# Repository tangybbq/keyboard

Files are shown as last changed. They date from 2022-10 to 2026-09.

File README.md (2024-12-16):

# David Brown (d3zd3z) keyboard designs

This repo captures the design files associated with my custom
keyboards.

These keyboards are primarily focused on Steno input, mainly using
[Plover](https://www.openstenoproject.org/plover/). In the spirit of
open steno, I have made these designs open. Anyone is free to make
designs based on these keyboards, for non-commercial purposes.  I am
releasing the designs under the [CC BY-NC
3.0](https://creativecommons.org/licenses/by-nc/3.0/) license.
Specifically, this means if you wish to sell a product based on the
design, you should talk to me.

## The "Jolt" keyboard

At this point, I've decided to give the keyboard a real name, hence "jolt".  The jolt 1 is still in
Eagle, and I may migrate the files here.

But, I have added the "jolt2".  The jolt2 is an experiment beyond just a traditional corne-like
keyboard, and something fully in 3-space, like the dactyl.  There are individual base plates for
left and right, and then small strips of 3 keys for each column.  The base PCB has 4 pairs of pin
headers to support these individual 3-key columns.  This will allow me to experiment with elevation
as well as just the X and Y position of each key.  I still want each column to be at the same
elevation, because I rely heavily on pressing keys together (both for my qwerty layout, and for
steno).

At this point, there are 4 PCBs here:

- [jolt2-left](jolt2/jolt2-left/): The layout of the left
  side using a directly assembled rp2040
- [jolt2-tiny2040-left](jolt2/jolt2-tiny2040-left/): The same left side pcb, but built around the [Pimoroni
  Tiny 2040](https://shop.pimoroni.com/products/tiny-2040?variant=39560012234835).  Note that only
  the left side needs the 8MB version (to hold the steno dictionary), but I just ordered all the
  same, and use the 8MB version on each side.
- [jolt2-tiny2040-right](jolt2/jolt2-tiny2040-right/): The Tiny 2040-based, made for the right side.
- [jolt2-verts](jolt2/jolt2-verts/): These are the small 3-key support boards.  It will take 28 of these,
  plus a left and a right to build a full keyboard.

In addition, there is also a [jolt2-pim-left](jolt2/jolt2-pim-left/), based around the [Pimoroni
PGA2350](https://shop.pimoroni.com/products/pga2350?variant=42092629229651).  There are numerous
errors in this that need to be fixed, as I messed up the reference numbers for the headers to the
key-boards.

## The "bletest2"

This isn't really a keyboard, but my experiments putting an nRF5340 module on a board.  This is work
in progress, and has numerous things I've discovered wrong with it.  I will work to improve it over
time:

- The power supply was suppose to auto switch between USB power and battery power.  However, I
  accidentally chose a boost converter instead of a boost/buck converter, and if USB is connected,
  all it does is fry everything on the board.  You can either leave out D1, or install a chain of
  diodes in its place (I used 5) to drop the voltage enough to make VBUS less than the 3.3.
  Auto-switching will probably end up preferring the battery, though, so I just recommend removing
  D1 entirely, and powering the board off of the batteries.
- The RGB LEDs don't work.  I'm not quite sure what is wrong, as I see no signal on the DIN pin.  I
  maybe have issues, given the difficult of properly soldering down the BLE module.
- The LEDs probably need a 5V supply, which isn't readily available.  Realistically, if I build a
  battery power device, I'll likely just use an analog RGB component, and use 3 gpios with PWM.

The intent was to be able to remove the various jumpers, and use the Power Profiler Kit II to
observer power consumption.  Despite rev 2, I'm still not far enough along with this to be able to
do that meaningfully.

## The "shield-kb1"

This is an Arduino-style shield, designed to plug into the nRF5340 DK.  It provides non-working
LEDs, a 2x2 keyboard matrix, and inter-board headers for left and right that should allow it to talk
to the jolt or proto3 designs.

## The "proto3"

This is basically the same design as the proto2, but with a third row.
The qmk supports an easier qwerty mode, but still with a modified
homerow modifier support (I use the lower row as it has slightly fewer
rollover conflicts).

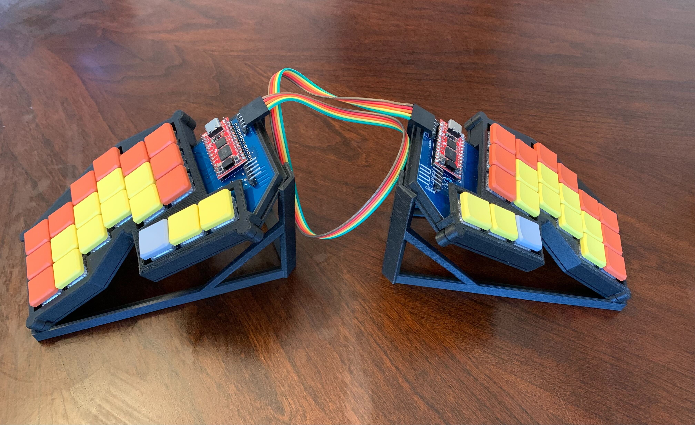
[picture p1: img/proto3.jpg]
proto3


The BOM is the same as the proto2, but it will need 42 diodes.

## The "proto2"

For lack of a better name, this first design is called the "proto2".

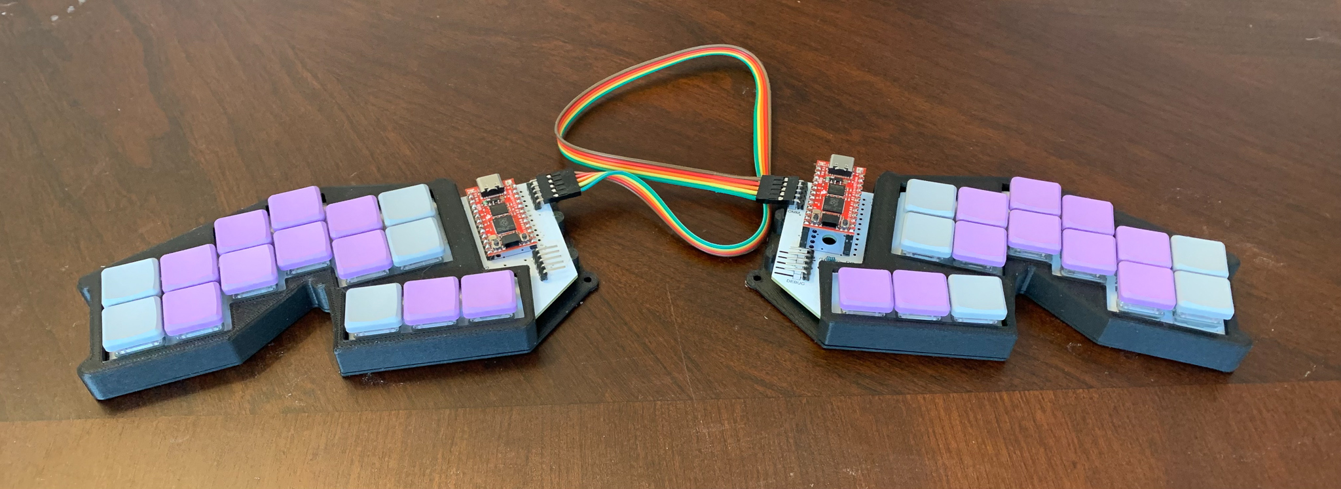
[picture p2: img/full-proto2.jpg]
full-proto2


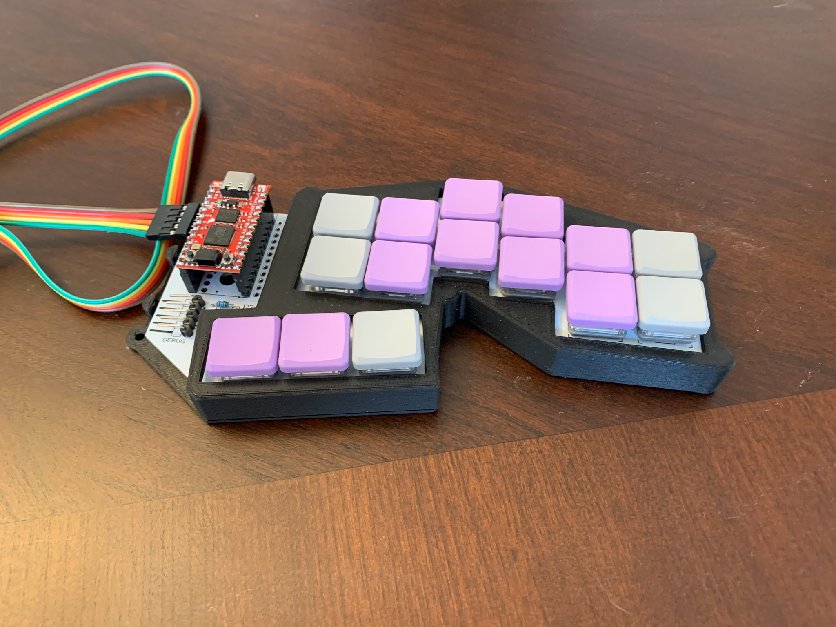
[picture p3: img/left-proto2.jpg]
left-proto2


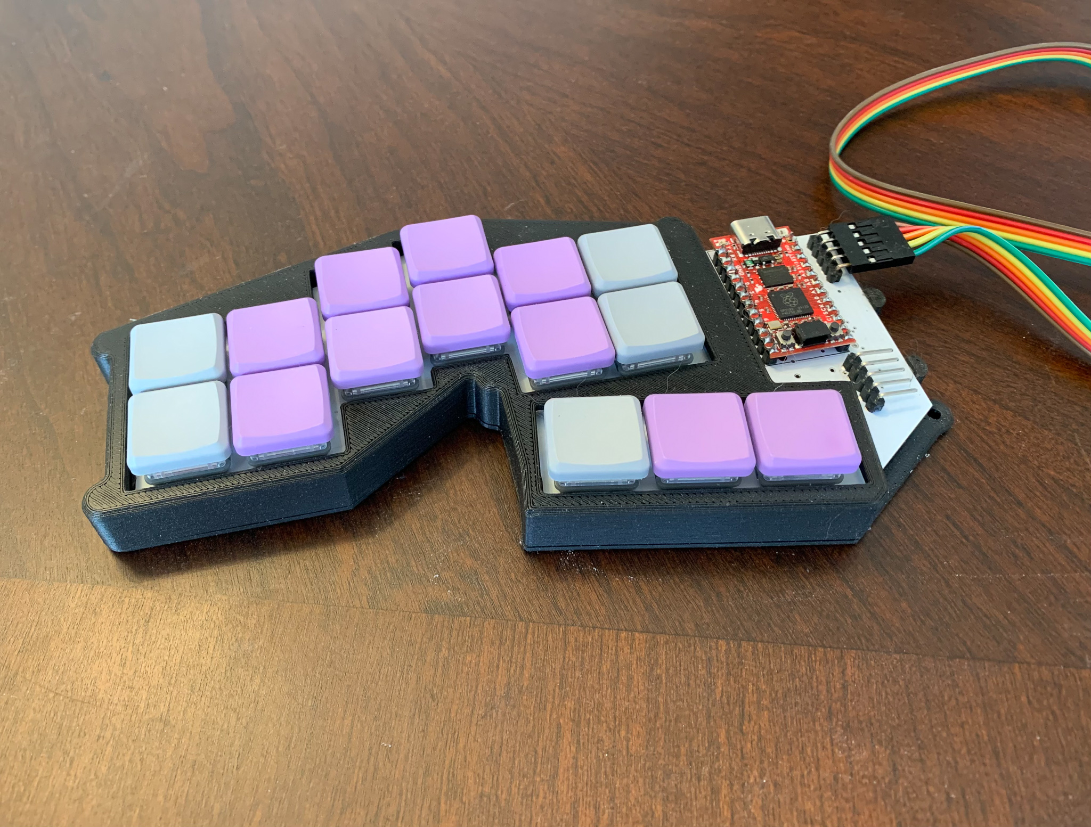
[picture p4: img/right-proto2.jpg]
right-proto2


There was an earlier prototype, that was handwired, and rather
fragile.  This is the first version I would consider to be a usable
keyboard.  In the above pictures, the left half has the MCU (Pro Micro
RP2040) soldered directly to a header, soldered to the PCB, and the
right one uses a socket.

To build this, in addition to the PCBs, you will need

- 2 [Pro Micro RP2040](https://www.sparkfun.com/products/18288)
  boards.  At the time of my build, these are running about $11, and
  seem readily available.
- 30 Kailh Choc switches.  I sourced mine from
  [Mkultra](https://mkultra.click/choc-switches).  I recommend the
  "pink" version, which has 20gf springs, and I find work well.
- 30 keycaps for these switches.  I used the [MBK Factory
  Colors](https://mkultra.click/mbk-factory-colors/) keycaps, which
  allows me to make the "primary" keys stand out a little, and just
  looks rather nice.
- 30 general purpose SOD123 diodes.  I got
  [BAV19W](https://www.digikey.com/en/products/detail/smc-diode-solutions/BAV19W/5993796),
  although almost any diode will work for this.
- 2 or 4 5-pin right angle headers.  Two are needed for the
  communication between the boards.  The others are interested if you
  want to use SWD, since the RP2040 Pro Micro inconveniently puts
  these connectors on the underside of the board.

The PCB is reversable.  The RP2040 board should be mounted in the
labeled holes, which is always the left set when viewed from the top.
The diodes are intended to be soldered to the bottom side of the
board.

I have also a case design that can be 3d printed.  The models are for
the right side. Use your slicing software to mirror about the X axis
to print the pieces for the other side.

The firmware I am using for this keyboard is in my fork of
[QMK](https://github.com/tangybbq/qmk_firmware/tree/proto2).

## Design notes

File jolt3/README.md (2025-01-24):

# The Jolt 3

The Jolt 2, with the varying-elevation design has turned out to be a rather nice keyboard to use.
However there are some challenges:

- Even with sockets, assembling all of the key risers is quite time consuming.  This makes it more
  challenging to experiment with the rest of the electronics.
- With more circuitry on the main board, the left/right distinction greatly increases the work to
  try a new design.

As such, the main goal of the Jolt 3 is to modularize the board design.  This is similar to using
existing rp2040 modules in the design, but in this case, the mezzanine board is my design instead,
with the following changes:

- Larger available area.  This allows me to put more on the board.
- Always have a debug headers.  The plethora of small boards that don't bother with debug headers is
  baffling to me.  I understand a lot of people are doing python, but this makes the board almost
  entirely useless for any serious development.

In order to make this board able to be used on either side of the keyboard, we'll need to avoid any
connectors that vary from side to side, notably the rj-45 (or whatever jack I decide on).  Now might
be a good time to try a different connector.  USB-C would work well for this, but it seems to be
hard to find thin USB-C cables.  I don't want 240W, I want a thin cable.  The old Apple cable is
really nice, but is getting harder and harder to find.  Another option is RJ-9.  The cables aren't
quite as available (and tend to be curly), but this might be a nice compromise.

Another thought, since I now have a tented stand, is to put the rj45 on the bottom side of the
board, and cut a notch for it.

It is fine to have the USB and debug header on the small board.

Sockets are going to be nice.  Regular pin header sockets are fine, but do lift the board up quite a
bit.  It still might end up being the best approach, as narrower pitch are harder to find.

This design should make some number of pins available in standard places:

- GPIOs for row and column.  4+6 is adequate for any of my current designs.  A two-row version with
  a single CPU would need 5+6, so 11 pins for this seems fine.
- Pins for the RJ-45?  If this is underneath, it gives more space.
- Battery.  The base board should be designed to allow a battery underneath.  The lines will just
  run directly to the small board.

## Dimensions

If we put the RJ-45 underneath, this gives us 41mm across by 39mm high.  It might make more sense to
just have the board be square at 40x40mm.

For a two-row design, this space could still be available.  It is unclear to me where my future
desire for 2-row will go (it depends on whether I become fully comfortable with steno+taipo).

## Design

The main boards will be jolt3-left, and jolt3-right, with the same connector on each.

- Supports the 7 risers in the same positioning and connection as the jolt2.
- Has a 40x40mm area for a mezzanine board.
- Defines a pinout for connections between the boards.  There are 20 pins needed, plus whatever is
  needed for extra grounding. A single row is likely to be fine.r
- Decide on the particular mezzanine connector to use.  It might make sense to have on one side with
  standoffs on the other sides.

The smallest M-2 size is 22x42, which would fit (but give half the available area.

I've ended up going for the [DF40C](https://www.hirose.com/product/p/CL0684-4010-9-51#) series of
connectors, 30 pin with a 3mm board spacing.  I could probably do 2mm, but the pins on the RJ-45 are
fairly long, and 3mm avoids the need to trim.  I'll use 3 1mm thick nylon washers for each standoff.

Rev A implements the following:

- jolt3-left: The left side.  The only components are the holes to mount the risers, the RJ-45, a
  place to mount the 2AA battery holder, and two pull up resistors for I2C.
- jolt3-right: The same as left, with minor changes: no pullups on I2C, Tx and Rx on the serial
  lines are swapped.
- jolt3-mez2040: The rp2040 circuitry on the mezzanine board.  I ended up with 38x38mm, to bring the
  mounting holes in enough on the main board to clear the stand.  The rp2040 is rotated 90 degrees
  to better route gpios to the connector (moves the crystal out of the way).
- Use the same riser boards "jolt2-verts" from the Jolt2.

The biggest change from previous designs is moving away from the Arm Cortex-M debug header to the
6-pin [Tag Connect](https://www.tag-connect.com/).  This requires no components on the board, just
some holes and pads, taking about the same area as the Cortex-M connector.  There is a smaller one,
but for these prototypes, the definitive connection seems better.  The cable is about $45 and should
last a long time.

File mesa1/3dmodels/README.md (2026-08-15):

# mesa1 3D models

Models for the parts that stick up off the board, so the 3D viewer and
`File → Export → STEP` show what a case or stand actually has to clear.

| File | Footprint | Offset (mm) | Rotation (deg) |
|---|---|---|---|
| `Kailh_socket_PG1350.step` | `mesa1:Kailh_socket_PG1350` | 0, 0, 0 | 0, 0, 0 |
| `SW_Kailh_Choc_V1.step` | `mesa1:Kailh_socket_PG1350` | 0, 0, 0 | 0, 0, **180** |
| `MBK_Keycap_1u.step` | `mesa1:Kailh_socket_PG1350` | 0, 0, **6.65** | 0, 0, 0 |
| `Pimoroni_Tiny2040.step` | `mesa1:Pimoroni_Tiny2040` | 0, 0, 0 | 0, 0, 0 |
| `RJ45_Amphenol_54602-x08_Horizontal.step` | `Connector_RJ:RJ45_…` | 0, 0, 0 | 0, 0, 0 |

Path prefix for all of them: `${KIPRJMOD}/../3dmodels/`. Use the variable, not
an absolute path, or the references break for anyone who clones the repo.

The first three all hang off the one key footprint — it is the whole key:
switch on the front, hotswap socket on the back. Add them in Footprint Editor →
Properties → 3D Models, then `Tools → Update Footprints from Library` in each
PCB to push them to the placed instances.

The RJ45 model has to go on the PCB instance rather than the library footprint,
since that footprint comes from KiCad's stock `Connector_RJ` library.

## Why those numbers

**Socket.** The transform is baked into the STEP (rotate +90° about X, then
translate 5.0, -3.75, -1.6), so KiCad needs no offset. The -1.6 puts it on the
back face of the board and therefore assumes the 1.6 mm stackup — regenerate if
the board thickness changes. Alignment was checked against the footprint: the
two receptacle collars (r 1.45) land in the 3 mm NPTH at (0, 5.95) and
(-5, 3.75), and the contact tails land inside pads 1 and 2.

**Switch.** Used as published, in KiCad 3D coordinates. The upstream footprint
puts the switch pins at board (0, -5.9) / (5, -3.8); ours has them at
(0, 5.95) / (-5, 3.75), i.e. the switch is turned around, hence the 180° about
Z. With that rotation the pins line up with the socket collars.

**Keycap.** +6.65 in Z seats the cap's stem plate (model z = 1.4) on the
switch's slider top (z = 8.05). Checked for interference against the switch
solid: zero intersection volume. The two stem legs drop into the slider's
slots without bottoming out, and the skirt clears the switch housing by 1.6 mm
at rest, shrouding it on the way down.

## Envelope, per key, relative to the front face of the PCB

| | Z (mm) |
|---|---|
| Socket, lowest point | -3.44 (1.84 below the back face) |
| Board back face | -1.60 |
| Switch housing top | +5.05 |
| Keycap bottom rim | +6.65 |
| Keycap top | +10.80 |

Keycap outline is 17.45 × 16.45 mm against an 18 × 17 mm pitch, so 0.55 mm of
air between neighbours in both directions.

## Tiny 2040 and RJ45

Neither is a real vendor model — both are envelope solids, enough to place a
wall or a cutout against, not enough to render nicely.

**Tiny 2040.** Built here in FreeCAD; see `Pimoroni_Tiny2040.step`. Pimoroni do
not publish a STEP; SnapMagic and TraceParts have one but both want an account.
The XY is exact, lifted from the F.Fab geometry of our own footprint, which came
verbatim from Pimoroni's `pimoroni-boards.lbr`:

- module PCB 20.32 × 18.0, 0.4 mm corner chamfers, from X 0 to 20.32, Y ±9
- USB-C receptacle 7.82 × 8.64, X -2.175 to 5.645, overhanging the module end
- underside components filling the footprint's 16.92 × 12.6 Edge.Cuts relief

The Z split is derived, not measured. Pimoroni quote 22.9 × 18.2 × 6 mm overall;
6.00 is reproduced exactly as 1.84 underside + 1.00 module PCB + 3.16 USB-C
receptacle. Those three are a plausible decomposition of a figure that is only
quoted as a total, so treat the individual numbers as approximate — in
particular check the 1.84 before committing to a pocket depth. Overall L and W
come out 22.50 × 18.00 against their quoted 22.9 × 18.2; the package geometry is
the more trustworthy of the two.

**RJ45.** `RJ45_Amphenol_54602-x08_Horizontal.step` is a plain 6-face box,
15.31 × 17.74 × 13.5, already in this directory. It lines up with the stock
footprint exactly — X -3.210…12.100 against an F.Fab of -3.205…12.095, and Y
mirrored as KiCad's 3D convention requires.

Note that KiCad 10 does **not** ship a model for this connector. Its
`Connector_RJ.3dshapes` has only three RJ45s (`Amphenol_RJHSE538X`,
`Molex_9346520x_Horizontal`, `Pulse_JK0654219NL_Horizontal`), so the
`${KICAD10_3DMODEL_DIR}/…/RJ45_Amphenol_54602-x08_Horizontal.step` reference the
footprint carries can never resolve. Point the instance at the local box
instead. If a proper model is ever wanted, Amphenol's 54602 CAD is on SnapMagic
and TraceParts, behind a signup.

## Keycap colour

The upstream MBK file ships with Fusion's `Opaque(214,14,14)` appearance baked
in — a hard red. Changed to a neutral charcoal by editing the one colour entity
the keycap solid resolves to:

    #6912=COLOUR_RGB('MBK Charcoal',0.235294117647059,0.235294117647059,
    0.250980392156863);

Three RGB floats, 0–1. Geometry is untouched. `#6911` ('Steel - Satin') is
unreferenced upstream leftover — editing it does nothing.

## Sources and licensing

- `Kailh_socket_PG1350.step` — Kailh's own PG1350 socket CAD (`PG1350.STEP`,
  SolidWorks 2018), the copy already in this repo at
  `jolt2/jolt2-verts/PG1350-socket.STEP`, repositioned.
- `SW_Kailh_Choc_V1.step` — from [kiswitch](https://github.com/kiswitch/kiswitch)
  (formerly perigoso/keyswitch-kicad-library),
  `library/3dmodels/3d-library.3dshapes/SW_Kailh_Choc_V1.stp`. Dual licensed
  MIT / CC BY-SA 4.0; taken under the MIT option.
- `MBK_Keycap_1u.step` — MBK reproduction by darryldh,
  [Thingiverse thing:4564253](https://www.thingiverse.com/thing:4564253), via
  [namnlos-io/choc_keycaps](https://github.com/namnlos-io/choc_keycaps).
  **CC BY-NC 4.0.** Published with Max Burger's permission. It is a
  reproduction for rendering, not the production file — close but not exact, so
  do not treat it as a tolerance reference. 1.5u, 2u and homing variants are in
  the same upstream folder if they are ever needed here.

The NC clause matches this repo's own CC BY-NC 3.0 terms, but it does mean the
keycap model cannot travel into anything commercial.

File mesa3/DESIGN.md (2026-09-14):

# mesa3 — design decisions and setup notes

Companion to `LAYOUT.md`, which holds the geometry. This file holds the decisions: what
changes from mesa2, why, and what was checked.

Status: **Rev A ordered 2026-09-07 and in transit. Rev B is open** — see *Rev B* below.
Everything in this file describes Rev A unless a section says otherwise.

## What the Mesa 3 is

The mesa2 Rev B keyboard, cut into two independently-positioned halves in the style of
mesa1. Same 18 keys, same Dosh layout, same key geometry. A single **Tiny2040 on the
left half** runs everything; the right half is passive and reaches the left over one
RJ-45 cable.

```
mesa3/
  3dmodels -> ../mesa1/3dmodels     symlink, so ${KIPRJMOD}/../3dmodels resolves
  mesa3-left/    Tiny2040, 4x SK6812, Tag-Connect, reset pad, RJ-45, 9 keys
  mesa3-right/   9 keys, 9 diodes, RJ-45. Nothing else.
```

Both halves were made by copying the finished mesa2 Rev B project **whole** and deleting
the other side, rather than building each up from parts. That is why the geometry
survives exactly.

## The matrix

**One 5 × 4 grid spanning both halves** — not one matrix per half.

- **5 columns, one per finger, shared across the halves.** The index column carries all
  four index keys: `I`/`E` on the left, then over the cable to `I`/`E` on the right.
- **4 rows, two per half.** `ROW_A`/`ROW_B` are the left's far and near rows,
  `ROW_C`/`ROW_D` the right's.
- 18 keys in 20 slots. The two empty ones are where mesa2's outer pinky keys were.

Column-to-pin assignment, unchanged from Rev B:

| net | keys | Tiny2040 pin |
|---|---|---|
| `COL_1` | pinky `A`, both hands | GP7 |
| `COL_2` | ring `S`/`O` | GP6 |
| `COL_3` | middle `N`/`T` | GP5 |
| `COL_4` | index `I`/`E` | GP4 |
| `COL_5` | thumb `SP`/`BK` | A3/GP29 |
| `ROW_A` | left far | A2/GP28 |
| `ROW_B` | left near | A1/GP27 |
| `ROW_C` | right far | GP0 |
| `ROW_D` | right near | GP1 |

**GP2 and GP3 are spare** and stay that way — see *Which board am I?* below.

### The firmware must not be able to tell a Rev B from a Mesa 3

This is a hard constraint, not a nicety. All 18 keys keep their **exact mesa2 (column,
row)** — verified key by key against Rev B's netlist — so one keymap serves the unibody
and the split alike, and no board-specific code is needed.

## The interconnect

Seven signals cross: **5 columns + `ROW_C` + `ROW_D`**. The columns run straight through
because they are shared by both hands; only the right's two rows are local to it.

| RJ-45 pin | net |
|---|---|
| 1 | *unused* |
| 2 | `COL_1` |
| 3 | `COL_2` |
| 4 | `COL_3` |
| 5 | `COL_4` |
| 6 | `ROW_D` |
| 7 | `ROW_C` |
| 8 | `COL_5` |

**Verified identical at both ends**, which is what makes a straight-through cable
correct. This is the check mesa1 learned to do and the one that fails silently: get it
wrong and the cable quietly becomes a crossover.

The pin *order* runs in opposite directions on the two boards. That is not a mistake —
an RJ-45 cannot be mirrored, so on mirror-image boards the same part necessarily has its
pin 1 at opposite ends. Only the net mapping has to match, and it does.

**Pin 1 is left unconnected on purpose.** It is tempting to run a ground down it, but
there would be nothing to connect it to: the right half has no ground net. The return
path for a scanned row is the column conductor it is switched into, so every loop already
closes through two wires of the same cable. mesa1 runs the same way.

### The right half is genuinely passive

No power, no ground, no LEDs — 23 components and 17 nets, all of it switches, diodes and
the connector. Nothing on it needs a supply, so none crosses the cable.

## The LED supply, inherited from Rev B

Carried across unchanged, and it must not be dropped: **this board needs the diode.**
mesa2 Rev A shipped without one and had to be reworked by hand.

| part | role |
|---|---|
| `D1` (1N4148W) | series diode, `+5V` to the `+4V5` rail |
| `JP1` (SolderJumper, open) | across `D1`; solder to bypass |
| `C1`-`C4` (100nF) | one per LED across `+4V5`/`GND` |

An SK6812 wants data above 0.7 × VDD. At 5.0 V that is 3.5 V and the RP2040 drives 3.3 V;
dropping the LED rail to ~4.3 V moves the threshold to 3.0 V. Only LED1 is actually
marginal — LED2-4 are driven by the previous LED's DOUT, which swings to its own VDD —
but the diode sits in the common feed anyway, because that reproduces the Rev A rework
exactly and keeps all four LEDs at matching brightness. `mesa2/LAYOUT.md` has the longer
version.

## Which board am I?

Nothing on the board answers this, by design. **Each keyboard is flashed with a small
CBOR blob naming its model**, and the firmware reads that. No board-ID strap, no
GPIO burned, and it works on boards already fabbed — which a hardware scheme could not
have done for mesa2 Rev A.

## The RJ-45 part

`RJ45_Amphenol_54602-x08_Horizontal`, Amphenol **54602**-908LF. Note it is the 54602;
the 54601 is the RJ12 six-position part and KiCad ships footprints under both numbers.

The part is **Active**, not discontinued — a stock gap against a 22-week lead time is
what makes it look otherwise. The escape hatch, should it ever be needed: that staggered
pin pattern (8 pins at 1.27 mm in two rows 2.54 mm apart, 8.89 mm span, posts 11.43 mm
apart 6.35 mm from the near row) is an industry standard. The TE **1705951-1** matches it
exactly, as do `RJ45_RCH_RC01937` (LCSC C708652), `RJ45_Ninigi_GE` and
`RJ45_HALO_HFJ11-x2450HRL`, all already in KiCad's library. **Not**
`RJ45_Bel_SI-60062-F` — that is a magjack and its magnetics would block the DC the matrix
runs on.

A swap would therefore be a **drill-size change, not a re-layout**: KiCad's 54602
footprint uses 0.76 mm signal holes and 3.2 mm posts where the others use 0.89-0.9 and
3.25.

## Verification performed

- **DRC: no errors on either half.** Schematic parity clean on both. The right half has
  nothing unrouted.
- **Outlines close**, checked vertex by vertex.
- **Every key pair mirrors exactly** — sums to 270.000 in x, matching y, negated rotation.
- **RJ-45 pinout identical at both ends.**
- **All 18 keys keep their mesa2 (column, row).**

### Known and accepted

None of these are being fixed:

- `J1` pin 1 unconnected on both boards, one ERC error each. Deliberate.
- Silkscreen clipped by the board edge in four places — A1's front silk at the left's
  inner edge, `J1`'s back silk on both boards. Cosmetic.
- Mounting hole designators disagree between the halves. Positions are right; see
  `LAYOUT.md`.
- The RJ-45 sits 0.300 mm off exact mirror.
- Four dangling 0.0254 mm wire stubs, in the schematics only.
- Inherited from Rev B on the left: GP2/GP3 floating, `A1` GND2 on no net, `LED4` DOUT,
  `J2` pin 6, `GND` without a `PWR_FLAG`.

**The "unconnected GND" DRC item is a false positive.** The symbol ties the Tiny2040's
three GND pads into one net, so DRC wants copper joining them, but the module commons
them internally and the board does not need to. It appears on mesa2 as well. A DRC
exclusion is the only thing that silences it — do not add copper to satisfy it.

## Rev B

Opened 2026-09-14, the moment Rev A shipped, so the delivered boards keep a stable name.
The bump to Rev B touched the two title blocks, `sch_revision` and the silkscreen on each
half, and nothing else — no geometry, netlist or routing moved with it.

**The change is one extra key per hand, immediately inboard of the near-row index key,
for mode switching.** A layer key, momentary or toggle, deliberately outside the chording
set because the lateral reach from index home is uncomfortable. It was a standing intent
before Rev A was routed and was left out of Rev A on purpose, that board already being on
its way to fab.

It is nearly free, which is why it was worth waiting for a revision rather than
retrofitting. Checked against the Rev A netlists:

| half | pinky `A` occupies | slot left free by dropping `R` |
|---|---|---|
| left | `COL_1` × `ROW_B` | `COL_1` × `ROW_A` |
| right | `COL_1` × `ROW_D` | `COL_1` × `ROW_C` |

No GPIO is consumed, and **no new conductor crosses the cable** — `COL_1` and `ROW_C`
are already two of the seven that make the trip, so the right half's key is free on the
interconnect as well as in the matrix. The pinky column just runs a trace across to the
index side; matrix position and physical position need not agree. Each key still gets its
own diode.

The *firmware must not be able to tell a Rev B from a Mesa 3* constraint above bends
rather than breaks. All 18 existing keys keep their exact mesa2 `(column, row)`, and the
two new slots are ones the older boards never assert — so one keymap still serves every
board, with the mode key simply unreachable where it is absent. What is lost is
feature-identity: a mesa2 Rev B has no mode key, so whatever that key unlocks must stay
reachable another way on boards without it.

**The left half is the mechanically constrained one.** Inboard of `SW_LE1` the left board
already carries `A1`, the reset pad, `J2` and `J1`; the right half's inner region holds
only two mounting holes and its `J1`. Solve the left position first and the right will
follow.

**The interconnect stays RJ-45.** USB-C was considered on 2026-09-14 and set aside. The
requirement never moved off seven conductors, since the new key adds none, and a USB 2.0
C-to-C cable carries about five; a full-featured cable has enough but is not
orientation-safe without a CC-sensing mux, and a USB-C receptacle invites being plugged
into a charger in a way an RJ-45 never is. The real point is that the connector question
is a **topology** question: USB-C only makes sense if the right half gains an MCU, at
which point the link is a two- or three-wire serial one between smart halves rather than
a passive matrix stretched over a cable. Reopen it only if that changes.
`mesa3-tasks.md` has the full argument.

## Still to do

- **Feet.** Reuse `davidb-keyboard-foot.pretty`; standoffs vs. adhesive not yet decided.
- **Case and plate models**, once boards exist.
- The keymap itself. The matrix map above is what the firmware needs to bring the board
  up; the layout on top of it is separate work.

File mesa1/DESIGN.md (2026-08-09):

# mesa1 — design decisions and setup notes

Companion to `LAYOUT.md`, which holds the recovered geometry. This file holds the decisions
about how mesa1 is built and what changes from proto4.

Status: **libraries built; KiCad projects not yet created.**

## What exists so far

```
mesa1/
  LAYOUT.md                              recovered geometry
  DESIGN.md                              this file
  mesa1.kicad_sym                        project symbols
  mesa1.pretty/
    Kailh_socket_PG1350.kicad_mod        upgraded to KiCad 10 format
    Pimoroni_Tiny2040.kicad_mod          new, built from Pimoroni's Eagle package
  mesa1-left/   fp-lib-table sym-lib-table
  mesa1-right/  fp-lib-table sym-lib-table
```

Both lib tables use `${KIPRJMOD}`-relative URIs, so the projects are self-contained and do
not depend on this machine's global KiCad tables. Drop a new KiCad project into either
directory and the `mesa1` libraries are already wired up.

Verification performed:

- both footprints parse and render under `kicad-cli` 10.0.5 (`fp export svg`)
- the symbol library parses and renders (`sym export svg`)
- all 19 Tiny2040 pad positions match Pimoroni's `.lbr` exactly, after negating Y for
  KiCad's downward axis
- all 19 symbol pin *numbers* match the footprint pad *names* exactly, both directions

Board outlines and all 30 switch placements are done and verified against the actual
`.kicad_pcb` files — 15 sockets per board, no pad off-board, worst clearance +1.147 mm
(mesa1-left, LNUM0) and +1.425 mm (mesa1-right, TS0).

Both schematics are complete and netlist-verified, including a cross-check that the RJ-45
pinout is identical at both ends (straight-through cable is correct).

**mesa1-left**: 38 components — 15 switches, 15 diodes, 4 LEDs, Tiny2040, RJ-45 (B.Cu),
Tag-Connect, reset pad. Outline valid (21 segments, incl. A1's cutout).

**mesa1-right**: 31 components — 15 switches, 15 diodes, RJ-45 (B.Cu). Outline is an exact
mirror of the left's plus the mirrored latch notch; 17 segments, closed loop.

Still to do: routing both boards.

### Matrix diodes

`Diode_SMD:D_SOD-123`, cathode (pad 1) to `ROW_n` — the same convention as proto4. Confirmed
the stocked part is SOD-123; the slightly smaller SOD-123W would also solder fine on this
land pattern, so the choice is not critical for hand assembly.

> **Assembly note: the band does not face the same way on both halves.** Grid diodes have the
> cathode toward −X on mesa1-left and +X on mesa1-right; the thumb diodes are the opposite
> again. This follows from the socket rotations (left grid 180°, right grid 0°) and is
> correct, not an error. **Orient by the silkscreen** — the banded end goes into the closed
> end of the three-sided bracket — rather than by copying the pattern from the other half.
>
> Note also that `Device:D` numbers the **cathode as pin 1**, which is the opposite of many
> diode symbols. Re-check the netlist if the symbol is ever swapped.

### Connector placement — mirror the BODY, not the origin

Both the RJ-45 footprint and the notch caught this. The Amphenol footprint's origin is at
pad 1, **4.445 mm off the body centre in Y and 5.1 mm in X**. Two consequences:

- The **latch notch** must be centred on the jack *body*, not the footprint origin.
- **Mirroring the right-hand jack** by mirroring its origin position puts the body in the
  wrong place. Because the right board's jack is rotated 180° from the left's, the
  origin-to-body offset flips sign, so the correction is *twice* the offset — 8.89 mm in Y.

Correct placements: left J1 origin (218.55, 102.77) rot −90; right J1 origin
(114.45, 111.66) rot 90. Both B.Cu. Both put the body centre at y 107.215, mirrored in x
about 166.5 (223.65 / 109.35).

### Outline asymmetry is fine

The left board's top edge carries the Tiny2040 slot; the right has no MCU and no slot, so
the two perimeters are not exact mirrors there. **This is not a problem** — proto4 does the
same and the mirrored 3D-printed stand fits both halves.

Known and deferred: silkscreen DRC warnings originate on **B.Fab**, which is not fabricated.
Cosmetic, no action needed.

### Library provenance — checked against Konnect, keep the current files

Konnect's operating rules say libraries should be built through its MCP tools. These were
hand-generated first, so they were re-checked. Conclusion: **keep them.**

- `Kailh_socket_PG1350.kicad_mod` and `mesa1.kicad_sym` were both rewritten by KiCad's own
  serializer (`kicad-cli fp upgrade` / `sym upgrade`), so the bytes on disk are KiCad's.
- `Pimoroni_Tiny2040.kicad_mod` was forced through a KiCad reserialization round-trip in a
  scratch copy. All 19 pads identical as numbers; Edge.Cuts, F.Fab, F.CrtYd and F.SilkS
  geometry identical segment-for-segment; UUIDs preserved. Only differences were cosmetic
  (`0.0` vs `0`, paste/mask layer ordering).
- The symbol was independently regenerated with `create_symbol` and compared: **all 19 pins
  matched exactly** on number, name, electrical type, position and angle.
- Both project lib tables resolve correctly through Konnect, `${KIPRJMOD}` expanding as
  intended.

Two limitations found in Konnect's library tools, worth knowing before relying on them:

1. **`create_footprint` takes only pads.** There is no parameter for arbitrary graphics, so
   it cannot express Pimoroni's `Edge.Cuts` cutout — the single most important feature of the
   Tiny2040 footprint. Rebuilding through it would silently drop the slot.
2. **`get_footprint_info` mis-parses KiCad-format footprints.** It reports `pad_count: 0` for
   any footprint using KiCad's multi-line pad serialization — including files KiCad itself
   wrote — because it only matches Konnect's own single-line style. Do not use it to validate
   footprints; use `kicad-cli` instead.

Konnect also writes `(version 20240108)` (KiCad 8-era) where KiCad 10 writes `20260206`.
Valid, and KiCad upgrades it on read, but it means round-tripping through Konnect is a
format downgrade.

### Placement rule for the Tiny2040 cutout — read before placing

Pimoroni's cutout is an **open** polyline: five segments, open at the module-end side at
package `x = 0.7`, endpoints `(0.7, ±6.3)`. It is open by design, because the module hangs
off the edge of the host board so the USB port is reachable. **The board outline has to
close it**, or KiCad will report an unclosed board edge.

Concretely: place the footprint so the board's edge passes exactly through `(0.7, ±6.3)` in
footprint coordinates. With the footprint origin at the module end and +X running into the
board, that means the origin sits **0.7 mm outside the board edge**.

Note this differs from proto4, where the board edge sat at package `x = −0.71` — 1.41 mm
further out — because the slot there was hand-drawn to the edge rather than taken from
Pimoroni. Do not copy proto4's placement value directly.

---

## Toolchain

Target **KiCad 10.0.5 only** (`/Applications/KiCad/KiCad.app`, `kicad-cli` 10.0.5). No
attempt at 8.0 compatibility.

### Library plumbing — this needs doing before anything else

Two real blockers, both a consequence of the custom libraries only ever having been
registered under KiCad 8:

1. **KiCad 10's global `fp-lib-table` contains only stock libraries.** None of
   `keyswitches.pretty`, `davidb-keyboard-foot.pretty`, or `Keebio-Parts.pretty` are
   registered. They exist only in `~/Library/Preferences/kicad/8.0/fp-lib-table`, with
   absolute `/Users/davidb/...` URIs.
2. **KiCad 10's global `sym-lib-table` contains no custom libraries at all.**
   `~/Documents/KiCad/8.0/symbols/David Brown Keyboard Parts.kicad_sym` is unregistered, and
   it lives outside this repo.

Plan: give each mesa1 project a **project-local** `fp-lib-table` and `sym-lib-table` using
`${KIPRJMOD}`-relative URIs, and commit them. That makes the projects self-contained and
reproducible instead of depending on this machine's global tables. Example:

```
(lib (name "keyswitches")(type "KiCad")(uri "${KIPRJMOD}/../../keyswitches.pretty")(options "")(descr "Kailh keyswitches and sockets"))
```

Symbols that mesa1 actually needs should be copied into a repo-tracked
`mesa1/mesa1.kicad_sym` rather than referenced from `~/Documents/KiCad/8.0/`.

### Legacy footprint format

Every footprint in `keyswitches.pretty` is in the KiCad 5-era `(module ...)` format.
`kicad-cli fp upgrade` converts them cleanly — verified on a scratch copy, which came back
as `(footprint ...)` with `(version 20260206)`.

Do this on a **copy** committed under mesa1's control, not in place on `keyswitches.pretty`,
so the older projects that still reference it are not disturbed.

---

## Mirroring: mesa1-right

proto4 did *not* mirror — both halves shared identical coordinates (see `LAYOUT.md`). That
was a workaround, not a design choice: mirroring the board was too much trouble, so the
right hand was built by soldering the switches onto the **back** of an identical board.

**That escape hatch is gone in mesa1.** proto4 used through-hole `PG1350` switches, which
can be inserted from either face. `Kailh_socket_PG1350` is SMD with its pads on `B.Cu`
only — the socket can only ever mount on one side. So mirroring is now mandatory rather
than merely tidier.

The transform, about a vertical axis at `x = A`:

```
x' = 2A - x
y' = y
rot' = -rot
```

`A` is TBD because the outline may change. If the outline is kept as-is, the natural choice
is the bounding-box centre, `rel x = 66.5`.

### Socket rotation differs between the hands — and must

The two boards use **opposite grid rotations**: left 180°, right 0° (thumbs −30° and −150°
respectively). This is not an oversight and cannot be tidied up.

`Kailh_socket_PG1350` is asymmetric: pad 2 sits at x = −8.275 with a 2.6 mm pad, reaching
**9.575 mm** from the switch centre on one side and only ~4.6 mm on the other. The pinky
column sits **9 mm** from the board edge. So at one rotation the socket overhangs the edge by
0.575 mm, and at the other it clears comfortably — and because mirroring puts that edge on
the opposite side of the board, the two hands need opposite rotations.

Only 0° and 180° are available. Any other angle physically rotates the keycap; that is why
the thumbs are −30°/−150° (a 180° pair) rather than an angle that scores better on
clearance but sits the keycap wrong.

All 16 rotation combinations were evaluated against the outline. **Exactly one clears**:

```
left grid 180°, left thumbs -30°, right grid 0°, right thumbs -150°   worst +1.147 mm
```

Every other combination puts at least one pad off the board. Expanding the outline does not
create additional options — it only makes the working combination comfortable.

Practical consequence: switches insert rotated 180° relative to each other on the two halves.

**This was checked feature-by-feature against the footprint, not assumed.** Exactly the three
mechanical features are invariant under a half-turn:

| feature | position | invariant under 180°? |
|---|---|---|
| centre boss, ⌀3.429 | (0, 0) | **yes** |
| positioning post, ⌀1.702 | (−5.5, 0) | **yes** |
| positioning post, ⌀1.702 | (+5.5, 0) | **yes** |
| pin holes ⌀3.0 at (0, 5.95) and (−5, 3.75) | — | no — move with the socket |
| pads 1 and 2 | — | no — move with the socket |

So the switch body sits in an identical physical position on both hands, retained by the same
centre boss and the same two posts on the horizontal axis. Everything that moves, moves
*together with the socket*, which is what makes the arrangement sound rather than merely
tolerable.

Keycaps are unaffected: the Choc stem is itself 180°-symmetric, so a cap mounts either way
round independent of switch rotation. The differing rotation is invisible from the top.

**Leftover feature:** the footprint also carries a ⌀0.991 mm NPTH at (5.22, −4.2) which is
neither structural nor electrical — it is one of a symmetric pair in the `_reversible`
variant, so here it is a vestige (probably an in-switch LED leg). It is the only feature that
lands somewhere genuinely different on each hand. Harmless, but a candidate for deletion if
in-switch LEDs are never fitted.

### Why rotations negate rather than the footprints being flipped

The reflection applies to the *arrangement*, never to an individual footprint. Each
footprint is only ever translated and rotated — never mirrored onto the other copper layer.
A Choc switch is a physical part that is the same in both hands; you do not get a
left-handed switch.

The consequence, which is expected and fine: because `Kailh_socket_PG1350` is asymmetric,
the socket bodies point in a rotated — not mirrored — direction on the right half. The two
finished boards will not look like mirror images in the socket area. Electrically and
mechanically this is correct. **The one thing to watch is edge clearance**: the socket
extends to `x = -8.275 + 1.3 ≈ -9.6` on one side and `+4.6` on the other, so a key that
clears the board edge comfortably on the left half may not on the mirrored right half.
Check the column-0 and thumb keys specifically.

### The reversible alternative, and why not

`keyswitches.pretty/Kailh_socket_PG1350_reversible.kicad_mod` carries duplicate pads on both
`F.Cu` and `B.Cu`, so one PCB works either way up. That is the trick that lets a single
design serve both hands. It does not suit mesa1, since the halves are genuinely different
boards — only the left carries the MCU — so the extra pads and the second pair of
`np_thru_hole` alignment holes would be dead weight. Use the plain
`Kailh_socket_PG1350`.

---

## Changes from proto4

### Notches become footprints

Agreed, and it is the idiomatic approach. KiCad footprints may carry `Edge.Cuts` graphics
that contribute to the board outline — confirmed present in stock libraries, e.g.
`Battery.pretty/BatteryHolder_Keystone_1057_1x2032` and
`LED_SMD.pretty/LED_SK6812MINI-E_3.2x2.8mm_P1.5mm_ReverseMount`.

Both outline features have now been identified, and both are exactly the case this is for.

**The 12 × 18 mm feature is the Tiny2040 slot, not a tab.** Traversing the outline, the top
edge dips *down* (into the board) between x = 195 and x = 207, so material is removed. It is
clearance for the components on the underside of the Tiny2040, which bridges the slot and
solders to board material either side. Full detail, including its recovery from the Eagle
source, is in the Tiny2040 section below.

This also explains why the feature is absent from `proto4-right`: no MCU, no slot.

**The 5 × 5 mm notch is RJ-45 relief.** The RJ-45 at `(200.76, 110.02)` rot 90 works out to
board `x 196.1..215.0`, `y 101.1..117.6`. Its outer face lands exactly on the right board
edge at x = 215, and the notch (`x 210..215`, `y 107..112`, centred y = 109.5) sits centred
on the jack (centred y = 109.4). It is the cable-entry / latch relief at the edge.

Rolling both into their footprints is therefore straightforwardly right, and it pays off
immediately: **moving the RJ-45 to the back side moves its edge relief with it**, instead of
requiring a hand-edit of the outline. Same for the Tiny2040 slot if its position shifts.

### RJ-45 3D model

`3dmodels/RJ45_Amphenol_54602-x08_Horizontal.step` — a plain rectangular prism, generated
because KiCad's footprint references a `.step` that the distribution never shipped (only
`RJ45_Amphenol_RJHSE538X.step` exists), leaving a dangling reference.

X/Y are taken from the footprint's own F.Fab outline, so it registers to the pads with no
offset; Y is negated for KiCad's 3D coordinate convention.

```
X  -3.21 .. 12.10   (15.31 mm)
Y -13.97 ..  3.77   (17.74 mm)
Z   0.00 .. 13.50   (13.50 mm)
```

> **The 13.5 mm height is deliberately oversized.** The real jack measures ~12 mm. This is a
> **clearance proxy for case design**, not an accurate part model — it errs 1.5 mm large on
> purpose. Do not use it for fit or interference checking where the true height matters.

Attach via Footprint Properties → 3D Models with the project-relative path
`${KIPRJMOD}/../3dmodels/RJ45_Amphenol_54602-x08_Horizontal.step`.

Still missing for case work: the **mating plug envelope** (plug + strain relief projects
~25–30 mm beyond the jack face, plus finger room for the latch). That, not the jack body, is
what the case aperture has to clear.

### RJ-45 moves to the back side

proto4 used the Eagle-imported `C-BMJ-0051-RJ45`. Don't carry that forward — jolt3 already
uses the stock **`Connector_RJ:RJ45_Amphenol_54602-x08_Horizontal`**, which is in KiCad 10's
default libraries and needs no library work.

Back-side placement is just placing the footprint on `B.Cu`. Two things to check: that the
jack body clears whatever the board sits on, and that a horizontal jack on the back does not
fight the case or the riser boards.

### Tag-Connect replaces the Cortex-M debug header

Matches the jolt3 decision — see `jolt3/README.md`, which notes it needs no components, only
holes and pads, and occupies about the same area as the Cortex-M connector.

Footprint: **`Connector:Tag-Connect_TC2030-IDC-FP_2x03_P1.27mm_Vertical`**, as used in
`jolt3/j3-mez-2040`. Also stock, also no library work. Being the `-FP` (footprint-only, no
legs) variant it needs retention — check what jolt3 does about holding the cable in place.

### Tiny2040 castellated mount — this is the main piece of new work

**The Tiny2040 did not survive the Eagle conversion.** `proto4-left.kicad_sch` has the
`TINY2040` symbol, but `proto4-left.kicad_pcb` has no matching footprint — 37 footprints,
none of them an MCU. The land pattern exists only in the original Eagle board.

Recovered from `proto4/proto4-left.brd`, where the part is `element A1`,
`library="pimoroni-boards"`, `package="TINY2040"`, at `(56.16, 17.29)` rot `R270`. That is
**Pimoroni's own footprint**, not a hand-drawn one. Downloading the current upstream
`pimoroni-boards.lbr` and diffing confirms it is byte-identical — same 19 SMD pads, same
dimension layer, same silkscreen. Pimoroni has not revised it, so this geometry is
authoritative.

#### Official land pattern

All pads `F.Cu` only, 2.54 mm pitch, each 1.9 mm along the row × 3.0 mm radial.

| row | position | pins (in order) |
|---|---|---|
| upper | `y = +8.17`, `x = 1.27 … 19.05` | 0, 1, 2, 3, 4, 5, 6, 7 |
| lower | `y = −8.17`, `x = 1.27 … 19.05` | 5V, GND1, 3V3, A3, A2, A1, A0, GND2 |
| end | `x = 19.49`, `y = +2.54, 0, −2.54` | SWDIO, GND3, SWCLK |

Row spacing is therefore **16.34 mm**, and the origin sits at one end of the module, not at
its centre. Module body is 18 mm wide (silk at `y = ±9`) × 20.32 mm long (silk `x = 0 … 20.32`).
Pads straddle the module edge: centred at 8.17 with 3 mm radial extent, so 6.67 … 9.67 —
2.33 mm under the module and 0.67 mm proud of it for the solder fillet.

#### This settles the footprint question

`davidb-keyboard-foot:Pimoroni-Tiny2040` (untracked, KiCad-native) uses **17.78 mm** row
spacing with 2.54 × 1.524 mm pads and a centred origin. That disagrees with Pimoroni's
official pattern by 1.44 mm on row spacing. **Do not use it** unless there is a known reason
Pimoroni's is wrong. Rebuild the footprint in KiCad from the Eagle package above.

#### The cutout is part of Pimoroni's package

Pimoroni's package carries its recommended milling cutout on Eagle **layer 20 (Dimension)**:

```
(0.7, 6.3) → (16.62, 6.3) → (17.62, 5.3) → (17.62, −5.3) → (16.62, −6.3) → (0.7, −6.3)
```

That is **12.6 mm wide × 16.92 mm long with 1 mm chamfers** at the far end. Its purpose is
clearance for the components on the underside of the module — the module bridges the slot,
resting on 2.7 mm of board material each side, which is where the castellations land.

So the cutout was always meant to travel with the footprint. Folding it into the KiCad
footprint's `Edge.Cuts` restores Pimoroni's original intent rather than inventing anything.

#### Slot width — decided: use Pimoroni's 12.6 mm

Mapping Eagle to KiCad coordinates for proto4-left — verified against two independent parts,
`RESET (48, −10) → (193, 94)` and `CORTEX U$2 (56.96, −10.04) → (201.96, 94.04)`:

```
kicad = (eagle_x + 145, 84 − eagle_y)
```

A1 therefore lands at KiCad **(201.16, 66.71)**, and Pimoroni's cutout maps to
`x 194.86 … 207.46`, `y 67.41 … 84.33`. The Edge.Cuts actually in `proto4-left.kicad_pcb` is
`x 195 … 207`, `y 66 … 84` — a plain rectangle, chamfers dropped, snapped to the mm grid,
and **12.0 mm wide against Pimoroni's 12.6 mm**.

Someone redrew it by hand and tightened it 0.3 mm per side. **On the built board that is
quite tight**, so mesa1 goes back to Pimoroni's specified 12.6 mm, chamfers included.

Consequence: the slot no longer lands on the mm grid. That is fine — once the cutout lives
inside the footprint, only the footprint's placement needs to be on grid, and the cutout
follows it. This is a second reason to fold the cutout into the footprint rather than draw
it into the outline by hand.

#### Reset wire pad — keep as-is

`RESET`, a single-pad `SMD1,27-2,54` wirepad at KiCad `(193, 94)`. A wire runs from it to
the reset button on the Tiny2040 itself. This exists because the RP2040 does not reset
peripherals on a soft reset over SWD, so the J-Link needs a real reset line. It is intended
to be permanent, not a bodge.

There is no better option available on the board side: **the Tiny2040 brings out no RUN or
RESET castellation.** Its 19 pads are 0–7, 5V, GND1–3, 3V3, A0–A3, SWCLK, SWDIO — reset
appears only as the physical button. So the wire has to be hand-run to the button whatever
the board does, and a single wirepad is the correct board-side answer. Carry it forward
unchanged; just place it where the wire run is short and mechanically sensible.

#### Side note

The module mounts on `F.Cu`, the same face as the keycaps, while the sockets are on `B.Cu`.
That is only tolerable because it drops into the slot, so the slot is not optional.

### MCU choice — Tiny2040, and why not the alternatives

**Tiny2350: ruled out.** Verified against Pimoroni's current `pimoroni-boards.lbr` — the
`TINY2350` package has **16 pads to the Tiny2040's 19**, and the three missing ones are
exactly `SWCLK`, `SWDIO`, and `GND3`. Pimoroni brought SWD out to castellations on the 2040
and then dropped it on the 2350. With no debug access it is not usable here, regardless of
the newer silicon.

```
TINY2040 (19): 0-7, 5V, GND1, GND2, GND3, 3V3, A0-A3, SWCLK, SWDIO
TINY2350 (16): 0-7, 5V, GND1, GND2,       3V3, A0-A3
```

**PGA2350: wrong shape for this board.** It is 25.4 × 25.4 mm with 64 PGA holes in two
rings around the edge. Using it would mean adding a socket *and* providing the USB connector
on the keyboard PCB, since the module has neither. That is a significant amount of extra
board area and BOM for a 15-key half — overkill here even setting aside the extra design
work. Not for mesa1.

It is not in Pimoroni's `.lbr` either, which ships only `PGA2040_PTH_NO_SLOT`,
`PGA2040_PTH_WITH_SLOT`, and `PGA2040_SMT_WITH_SLOT`. The repo's untracked
`davidb-keyboard-foot.pretty/PIMORONI-PGA2035-PM722.kicad_mod` **is** this part despite the
name: 64 through-hole pads spanning 22.86 × 22.86 mm in a ~26.5 × 27.2 mm body. The `2035`
looks like a transposition of `2350`. Worth renaming if it is ever used.

This is worth writing down because it constrains the future: the debug story depends on the
module exposing SWD on castellations, and that is not a given across Pimoroni's range. Any
substitute MCU module has to be checked for SWD castellations first.

### Outline changes

Open. The recovered outline in `LAYOUT.md` is the proto4 shape and is a reasonable starting
point, but nothing depends on keeping it. Note that changing it changes the mirror axis `A`
above.

---

## Open questions

- Where does the thumb cluster anchor? Its 18 mm / 30° spacing is exact but its origin is
  off-grid; pick a clean anchor for mesa1 rather than importing proto4's.
- Where does the reset wirepad go, now that the RJ-45 and debug header are moving? Its only
  constraint is a short, sensible wire run to the module's button.
- Do the LEDs from proto4-left (4 × SK6812-MINI-HS) carry forward?

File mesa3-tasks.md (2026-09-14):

# Toward the Mesa 3

This document describes a series of design steps to work our way through:
- some improvements to the Mesa 2 keyboard
- an alternate design of the Mesa 2 to test a different scanning technique on the matrix
- the design of the Mesa 3, which will take the physical layout learned from the Mesa 2 and apply it to a split design in the style of the Mesa 1.

The main change to the layout is to eliminate the outermost pinky key. I am now
using a custom layout, called Dosh, that only uses 7 finger keys per side.

Dosh uses the same key names as Taipo for the keys it keeps. Only the outer pinky
key (`R`) goes away, so the surviving refs are unchanged: pinky `A`, ring `S`/`O`,
middle `N`/`T`, index `I`/`E`, thumbs `SP`/`BK`. **9 keys per side, 18 total.**
No ref renaming is needed anywhere — `SW_LR1`, `SW_RR1` and their diodes are simply
deleted.

**Everything here ends in one fab order.** It was planned as four PCBs — mesa2 Rev B,
mesa2x Rev A, mesa3-left, mesa3-right — and is now **three**: the 2x experiment was
completed, analysed and dropped, because the pairwise matrix cannot resolve chords and no
hardware change short of more pins fixes it. Fab cost is dominated by shipping, so the
remaining three designs must be finished and reviewed before anything is ordered.

## Conventions

- `(human)` — a step I do in the KiCad GUI. `(AI)` — a step done by script or analysis.
  Untagged steps are open to either.
- **Geometry is generated, not hand-nudged.** Key positions come from `mesa2/layout.py`
  → `placement.json` → the PCB, and the outline from `outline.py` → `outline.json` →
  `dxf.py`. Change the scripts and re-emit; don't drag footprints in the editor and let
  the model go stale.
- `mesa2/LAYOUT.md` is the geometry record of truth for humans, and must be updated in
  the same commit as any geometry change.
- Rev letters are per board, in the silkscreen, and bumped when a board is sent to fab.
- **Firmware is my own, in Rust + Embassy.** Not QMK, not ZMK, not KMK. Anything a board
  needs from the firmware side is a spec an agent working in that codebase implements
  from — see below.

## Boards in this batch

| board | dir | keys | matrix | controller |
|---|---|---|---|---|
| mesa2 Rev B | `mesa2/mesa2` | 18 | 5 × 4, per-finger columns | Tiny2040, unibody |
| ~~mesa2x Rev A~~ | `mesa2/mesa2x` | 18 | pairwise — **not being fabbed**, see below | Tiny2040, unibody |
| mesa3-left | `mesa3/mesa3-left` | 9 | the same 5 × 4, spanning both halves | Tiny2040 + RJ-45 |
| mesa3-right | `mesa3/mesa3-right` | 9 | " | passive, RJ-45 only |

Rev B and the two Mesa 3 halves are one matrix as far as the firmware is concerned.

## What the firmware sees

The firmware is mine, in Rust + Embassy, so the board designs answer to it rather than the
other way round. The requirement on this batch:

- **mesa2 Rev B and mesa3 present one identical matrix.** Same five columns, same four
  rows, the same key at every (column, row). The firmware must not be able to tell a
  Rev B from a Mesa 3 — one keymap, one build, no board-specific code. Mesa 3 is copied
  from Rev B, so this holds for free as long as neither board's wiring is changed on its
  own afterwards.
- **Rev A's column pairing is mirrored, and Rev B fixes it.** As wired today the two
  hands number their columns in opposite order, so a shared column joins *different*
  fingers:

  | net | left | right | after the Rev B fix |
  |---|---|---|---|
  | `COL_1` | pinky `A` | index `I`/`E` | pinky `A` both sides |
  | `COL_2` | ring `S`/`O` | middle `N`/`T` | ring both sides |
  | `COL_3` | middle `N`/`T` | ring `S`/`O` | middle both sides |
  | `COL_4` | index `I`/`E` | pinky `A` | index both sides |
  | `COL_5` | thumb `SP`/`BK` | thumb `SP`/`BK` | unchanged |

  It works either way — every column carries four keys and the firmware maps
  (column, row) to a key regardless. It is just confusing, and it is cheap to fix while
  Rev B is being rerouted anyway.
- **Rows are already right**: `ROW_A`/`ROW_B` are the left's far and near rows,
  `ROW_C`/`ROW_D` the right's. Unchanged from Rev A, unchanged in Mesa 3.
- **Rev A is the one board it has to tell apart**, because Rev A has the outer pinky `R`
  and Taipo makes sense on it, and Rev B/Mesa 3 have neither. **Already solved in
  software:** each keyboard is flashed with a small CBOR blob naming its model, so the
  firmware reads the model rather than probing the hardware. No board-ID strap, no
  GPIO, nothing to design in — and it works on Rev A, which is already fabbed and could
  not have been changed anyway. GP2 and GP3 simply stay free.
- **mesa2x is deliberately its own thing** — different scan algorithm, separate build,
  spec'd in `mesa2x/SCANNING.md`.
- The matrix map is written once and shared by Rev B and Mesa 3. Two copies would drift.

## Housekeeping

**Do this first.** Rev A is the board I am typing on right now, and none of it is in git
yet — capture it before anything changes.

- [x] Add necessary .gitignore file(s) and commit the current mesa rev A design.
  `.DS_Store`, `__pycache__/` and `~*.lck` added to the root `.gitignore`;
  `production/` is committed, following mesa1.
- [x] Clean the strays that came along when mesa2 was copied from mesa1:
  `mesa1-left-backups/`, `mesa1-left-unsaved-export-JyNPS8.kicad_prl` and a duplicate of
  mesa1's `production/mesa1-left_A.zip`. All three still exist under `mesa1/`.
- [x] The tracked `.DS_Store` files under `mesa1/` removed from the index, along with a
  tracked `~mesa1-left.kicad_pro.lck`.

## Mesa 2 Rev B

Starting point: mesa2 Rev A — 20 keys, routed (401 segments, 41 vias, one zone),
outline drawn, `production/mesa2_A.zip` already exported.

**Status:** schematic and PCB both carry the Rev B netlist and placement. What is
left is routing, the outline, and the fab-facing tidying.

**Konnect's IPC path is unusable here** — it segfaults KiCad 10.0.5 on writes *and*
on read-only queries. Footprint placement goes through `apply-revb.py`, which drives
KiCad's own bundled `pcbnew` module (KiCad must be closed). Net changes still come
from *Update PCB from Schematic* in the GUI.

- [x] Remove the outermost pinky key
  - [x] Delete `SW_LR1`, `SW_RR1`, `D_LR1`, `D_RR1` from the schematic — with the
    eight wire stubs that tied those two cells to their row and column buses
  - [x] Update the matrix map in `LAYOUT.md` — the pinky column now carries one key
  - [x] Delete the four footprints from the PCB — via *Update PCB from Schematic*,
    which also re-applied the column nets
- [x] Rotate the pinky keys 90° so that their orientation is similar to the other
  finger keys. **−90 on the left, +90 on the right**: `SW_LA1` +62.9 → −27.1,
  `SW_RA1` −62.9 → +27.1. The direction is not visible in the geometry — the two
  options are 180° apart, so the cap lands identically and every clearance number
  matches; only the socket body and diode change sides. Settled by looking at the
  board, and written down in `LAYOUT.md` so the numbers don't argue for the wrong
  one later
- [x] Move the Sp keys 1mm closer to the Bk key: 18.00 mm → **17.00 mm**. Checked — the
  thumb pair is separated along the cap's 16.5 mm axis, same as the finger rows (the
  caps are rotated across the direction of travel), so Rev A's 18 mm leaves a 1.50 mm
  gap where every finger row has 0.50 mm. 17.00 mm makes the thumbs match everything
  else exactly.
- [x] Fix the mirrored column pairing — one column per finger, the same finger on
  both sides (see *What the firmware sees*). Done by moving the right-hand symbols
  between grid cells, so every wire stayed put: index ↔ pinky and middle ↔ ring
- [x] Decide and implement the Rev A / Rev B distinction — **nothing to do on the
  board.** Each keyboard carries a flashed CBOR blob naming its model, so the firmware
  reads the model directly. GP2 and GP3 stay free
- [x] Adjust the diodes of the moved keys. Mechanical: every diode sits at local
  (0, −4.876) mm in its switch's frame, rotated 180°, verified across all 20 Rev A
  keys — the targets in `revb-placement.json` already preserve it
- [x] Generate the Rev B geometry (AI) — `revb.py` reads Rev A straight out of
  `mesa2.kicad_pcb` and writes `revb-placement.json`. Note `placement.json`,
  `sw.json` and `LAYOUT.md`'s original table all predate the 5° hand rotation and do
  **not** match the board; the PCB is the record of truth
- [x] Apply `revb-placement.json` to the PCB — `apply-revb.py`, via KiCad's bundled
  `pcbnew` module. All 36 footprints verified against the target; board structure
  unchanged (50 footprints, 401 segments, 41 vias, one zone)
- [x] Re-run the cap clearance check over all remaining pairs (AI). Worst gap
  0.494 → 0.496 mm, and it is the ring column, untouched by any of this. The pinky's
  tightest neighbour goes 0.869 → 0.681 mm and the thumbs land on 0.503 mm, matching
  the finger rows. Nothing drops below the 0.5 mm target
- [x] Fix the routing (human)
- [x] Adjust the board outline (human)
- [x] Confirm the six M2 mounting holes are still inside the outline and clear of
  sockets and caps
- [x] Fixup label for Rev B
- [~] Print the 1:1 placement sheet and check it against my hands before fab (human).
  Mockup printing now. Low stakes: Rev A is in daily use and the geometry barely moved
  — one key gone, one cap rotated in place, thumbs in by 1 mm.
- [x] Update `LAYOUT.md` to the Rev B geometry — target positions, the rotation
  reasoning, the diode invariant and the clearance table
- [ ] Write the shared matrix map — column/row net to key for both Rev B and Mesa 3, plus
  scan order and debounce expectations. This is what the firmware agent implements from
- [x] ERC — no new violations. The 8 errors that remain are byte-identical in
  Rev A (dangling GP2/GP3 stubs, `LED4` DOUT, `J2` pin 6, and the Tiny2040's power
  pins having no driving output pin on a board it powers itself)
- [x] DRC clean — **0 errors**, down from 58 before the reroute. The 9 remaining
  warnings are all the cosmetic "footprint does not match copy in library" note.
  Schematic parity: 0 issues. One unconnected item, A1 pad `GND1`, which Rev A has
  identically
- [x] Design review — findings below
- [x] Git commit Rev B

Both cosmetic loose ends are closed: the LED diode is `D1` now, and `PWR_FLAG`s on
`+5V` and `+4V5` took ERC from 12 entries to 10. What remains is all inherited from
Rev A — `GND` wants a flag of its own, `A1`'s `GND2` is on no net, and `GND1` has no
copper reaching it on the board. See *ERC noise* in `LAYOUT.md`; worth doing before
fab only so a real problem cannot hide in the noise.

Rev B keeps `COL_1..5 × ROW_A..D` — 18 keys in 20 slots, the two empty ones being the
deleted pinky `R` keys. Don't re-pack to free a GPIO: the Tiny2040 has pins to spare, and
Mesa 3 needs this exact shape. The columns ended up on **GP7..GP4** rather than GP4..GP7,
reassigned once they paired by finger to make the fan-out to the MCU tidier.

### Design review

**Verdict: no defects. What is left is decisions, not fixes.**

Checked and clean: DRC 0 errors · schematic parity 0 issues · ERC unchanged from Rev A ·
all 36 footprints still exactly on `revb-placement.json` after routing · outline
214.0 × 111.0 mm, centred on the mirror axis, and closed (it is an open chain by design,
and A1's five Edge.Cuts segments meet both loose ends) · six M2 holes present with no
edge or hole clearance violations · silkscreen carries the rev · track widths
0.25/0.3/0.5 mm on 0.6/0.3 mm vias, all comfortably inside fab limits.

Findings, in priority order:

1. ~~The Rev A / Rev B distinction is undecided.~~ **Resolved in software** — the
   flashed CBOR model blob already identifies the board, so no strap is needed and
   GP2/GP3 stay free.
2. ~~No decoupling on the four SK6812s.~~ **Done** — `C1`-`C4`, one 100 nF per LED
   across `+4V5`/`GND`. Along with it, the LED supply diode Rev A needed as a hand
   rework is now designed in: `D_RE2` in series, `JP1` open across it to bypass.
   See *Rev B — the SK6812 supply* in `LAYOUT.md`.
3. A1's `3V3`/`5V` pins have no decoupling either. Ignorable: the Tiny2040 is a module
   and carries its own.
4. A1 pad `GND1` is unrouted, exactly as in Rev A. The module commons its grounds and
   GND3 is routed, so it is cosmetic — but it sits in the DRC report permanently and
   could mask a real unconnected item later. A short hop clears it.

## Mesa 2x Rev A

This is an experiment with a new matrix. The idea is to not have a fixed idea of
a grid, but that for GPIOs 1-m, for a given GPIO n, there is a key+diode to each
of n+1..m.

Branches from **Rev B**, so the two boards share one geometry and only the wiring
differs. 18 keys needs the smallest m with m(m−1)/2 ≥ 18, which is **m = 7** (21 pairs,
3 spare) — down from the 9 pins the grid uses.

- [x] Copy the mesa2 Rev B dir to mesa2x (it lives at `mesa2/mesa2x`), rename the
  project files and internal refs
- [x] Assign the 18 keys to GPIO pairs — `SCAN_1..7` on GP0-GP4, GP27, GP28. All 21
  pairs available, 18 used, `5-4`/`6-1`/`7-1` spare. GP5, GP6, GP7 and GP29 freed
- [x] Fix the diode polarity convention — as built it is **cathode toward the
  lower-numbered pin**, the opposite of the guess here, applied consistently to all 18
  keys. Recorded in `SCANNING.md`
- [x] Rewire keys (human)
- [x] AI analysis of ghosting with arbitrary chords. **The result is negative and it is
  structural.** Two pressed keys `a→c` and `c→b` forge `a→b` through a two-diode sneak
  path, and **21 two-key chords forge a third real key** — `LA1`+`LBK1` reads as `LT1`,
  and so on. The forged key is electrically identical to a real one, so no scan order or
  timing resolves it. It is not the assignment's fault: 18 keys on 7 pins is 18 edges on
  7 vertices, and Mantel's theorem caps a triangle-free graph there at 12 edges, so
  triangles — and therefore ghosts — are unavoidable. The first pin count that fits 18
  keys triangle-free is **9**, where the optimum is the complete bipartite 4 × 5 graph:
  the conventional matrix mesa2 Rev B already uses. The pin saving and the ghosting are
  the same fact. Full analysis and the chord tables are in `mesa2x/SCANNING.md`
- [x] Write `mesa2x/SCANNING.md` — pin map, key table, the six strobe steps, pull
  configuration, settle and debounce, the ghost tables, and the hardware change that
  would fix it. The algorithm did **not** come out clean on paper, which per this task's
  own terms means the board is wrong rather than the firmware — see the decision below
- [x] Make the silkscreen clearly distinguish this board from the Rev B one
- [x] Reroute (human)
- [x] ERC and DRC — **DRC has no errors**, schematic parity is clean, and the single
  unconnected item is the Tiny2040 GND false positive. ERC carries the inherited noise
  plus four now-unused pins (GP5, GP6, GP7, A3)
- [x] Design review — findings below
- [x] Git commit

### Design review

The board is built correctly and does what it was drawn to do. The experiment answers
its question, and the answer is no.

- **DRC clean, parity clean.** 18 keys, 18 diodes, all on distinct pin pairs with a
  consistent polarity. The LED supply work from Rev B came across intact: `D1`, `JP1`,
  `C1`-`C4`.
- **It buys back four GPIOs** — GP5, GP6, GP7, GP29 — exactly as advertised.
- **It cannot resolve chords**, and cannot be made to in firmware. See above.
- The two-diode voltage difference between a real press and a ghost is real but
  unusable: the RP2040's input thresholds are characterisation data, not guaranteed, and
  a ghost lands in the indeterminate band between V_IL and V_IH.
- **Series resistors do not fix it.** Checked with a DC solve of the real network, not
  by argument. Driving the non-read pins high does block the ghost, but it lifts the
  strobe node by a diode drop for every *other* key pressed on that strobe, and the real
  press rides up out of the low band with it — 1.79 V where it needs to be under 0.8 V.
  Trading a false key for a missed key. Making the strobe stiff instead recovers
  detection and hands the ghost back. The read pin sits one diode drop above the strobe
  for a real press and two for a ghost; resistors move the strobe node but never change
  that the separation is one Vf ≈ 0.6 V, where the RP2040's guaranteed levels need 1.2 V.
  A higher-Vf part raises both sides equally, and the ADC cannot help because the real
  press reads 0.41 V alone and 1.79 V with one more key down.

**Recommendation: drop it from the fab batch.** Reversing the earlier call to fab it
anyway. There is no configuration of this board that resolves chords, so a physical copy
would only demonstrate what the analysis already establishes, and the analysis is
structural rather than empirical. The useful output of the experiment is
`mesa2x/SCANNING.md`. Keep the project in the tree — it is finished, reviewed and
routed — and if the curiosity is ever worth a board, it is one file change to add back.

## Mesa 3

Split, in the style of the Mesa 1: a single **Tiny2040 on the left half**, RJ-45 on
B.Cu at each end with a straight-through cable, and a **passive right half** — no power,
no LEDs, not even a ground. Mesa 1 set the precedent: its right half carried eight matrix
nets and nothing else.

### The matrix

One 5 × 4 grid spanning both halves, the same shape mesa2 uses, so the two boards behave
alike from the firmware's point of view.

- **5 columns, one per finger, shared across the halves.** The index column carries all
  four index keys: `I`/`E` on the left, then out over the RJ-45 to `I`/`E` on the right.
  Same for the other four columns.
- **4 rows, two per half.** `ROW_A`/`ROW_B` are the left's far and near rows,
  `ROW_C`/`ROW_D` the right's.
- **7 signals between the halves**: 5 columns + `ROW_C` + `ROW_D`. One of the RJ-45's
  eight conductors is spare.
- 18 keys in 20 slots; the two empty ones are where the deleted pinky `R` keys were.

Per column: pinky 2 keys, ring 4, middle 4, index 4, thumb 4.

- [x] Make a mesa3 directory — with a `3dmodels` symlink to `../mesa1/3dmodels`, so the
  boards' `${KIPRJMOD}/../3dmodels/…` model paths resolve the same way mesa2's do
- [x] Copy the mesa2 **Rev B** design project to mesa3/mesa3-left and mesa3/mesa3-right,
  renaming projects and refs. Both halves start as the *complete* 18-key board, to be
  cut down rather than built up. Verified identical to mesa2: same 55 components, 43
  nets, 55 footprints at identical positions, 409 segments, 41 vias, 26 outline lines.
  Only the names, the rev (each half starts at Rev A) and the silkscreen differ.
  Not carried over: `production/`, the freerouting `.dsn`/`.ses`, the stale `.step`
  export, `fpdiff.py`
- [ ] Fix `sym-lib-table` in **four** projects: `mesa2/mesa2`, `mesa2/mesa2x`,
  `mesa3/mesa3-left`, `mesa3/mesa3-right`. All four say
  `${KIPRJMOD}/../mesa1.kicad_sym`, inherited from mesa1 where that path is correct —
  mesa1's own projects sit inside `mesa1/`, so `../` finds the symbol file. The copies
  do not, so it resolves to `mesa2/mesa1.kicad_sym` and `mesa3/mesa1.kicad_sym`, neither
  of which exists. That is the long-standing "symbol library 'mesa1' was not found"
  ERC warning.

  The fix is the same one string in all four, matching what `fp-lib-table` already uses:

      ${KIPRJMOD}/../../mesa1/mesa1.kicad_sym

  In the GUI: **Preferences → Manage Symbol Libraries → Project Specific Libraries**,
  edit the `mesa1` row's path. Leave mesa1's own two projects alone — they are correct
- [x] Manually create the split (human) — left keeps the Tiny2040, all four SK6812s, the
  Tag-Connect and the reset pad; right is switches, diodes and the RJ-45 only. The right
  half came out genuinely passive: 23 components, 17 nets, no power, no ground
- [x] Assign the 7 matrix nets to RJ-45 pins, then cross-check the pinout is identical at
  both ends so a straight-through cable is correct (AI, as in `mesa1/DESIGN.md`).
  **Verified identical**: pin 2 `COL_1`, 3 `COL_2`, 4 `COL_3`, 5 `COL_4`, 6 `ROW_D`,
  7 `ROW_C`, 8 `COL_5`, pin 1 spare. Pin order runs opposite between the halves, which
  is what a part that cannot be mirrored does, and does not matter since the nets match
- [x] Manually layout design (human). Both halves kept the mesa2 coordinate frame, so
  every key pair still sums to x = 270.000 with matching y and negated rotation
- [x] Draw new left outline (human) — 124 × 111 mm
- [x] Reflect and generate right outline (human) — also 124 × 111 mm. Both are closed
  loops: the left closes through A1's cutout as mesa2 did, the right closes on its own
  with a straight inner edge where the MCU cutout was. The relief notches mirror exactly
- [x] Place the RJ-45 and its edge relief notch — B.Cu on both halves, notches mirrored
  exactly (147-152 on the left, 118-123 on the right, y 106-111)

  **On the jack.** It is `54602`, not `54601` — 54601 is the RJ12 6P6C part, and KiCad
  ships footprints under both numbers. `54602-908LF` is **Active**, not discontinued;
  what looked like an EOL was a stock gap, with 3,120 landing at DigiKey on 16 Sep 2026
  and thousands more on Marketplace. Standard lead time is 22 weeks, so it is worth
  knowing the escape hatch:

  Its pin pattern is an industry standard — 8 pins staggered 1.27 mm in two rows 2.54 mm
  apart, 8.89 mm span, two posts 11.43 mm apart sitting 6.35 mm from the near row. The
  TE **1705951-1** matches it exactly (checked against TE's customer drawing), as do
  `RJ45_RCH_RC01937` (LCSC C708652), `RJ45_Ninigi_GE` and `RJ45_HALO_HFJ11-x2450HRL`,
  all already in KiCad's library. Not `RJ45_Bel_SI-60062-F` — that one is a magjack, and
  its magnetics would block the DC the matrix needs.

  So a jack swap is **not a layout change**: same pins, same posts, same position. The
  only difference is drill size. KiCad's 54602 footprint uses 0.76 mm signal holes and
  3.2 mm posts; every other footprint in that list uses 0.89-0.9 and 3.25, and TE's
  drawing asks for 0.9 ±0.1. If the Amphenol ever does go away, widening the drills is
  the whole migration. The shielded options additionally want two 1.6 mm tab holes —
  at y 9.4 for RCH and Ninigi, y 3.3 for HALO, so those two cannot both be covered.
- [x] Mounting holes — four per half, mirrored exactly (every pair sums to 270.0)
- [ ] Feet — reuse `davidb-keyboard-foot.pretty`; decide standoffs vs. adhesive feet
- [x] Reroute (human)
- [x] ERC and DRC on both halves — **DRC has no errors on either board**, schematic
  parity is clean on both, and the right half has nothing unrouted
- [x] Write `mesa3/LAYOUT.md` and `mesa3/DESIGN.md` in the mesa1 style — geometry and
  verification in the first, decisions in the second
- [x] Check the built halves against the shared matrix map from Rev B — **all 18 keys
  keep their exact mesa2 (column, row)**, so one keymap still serves Rev B and both
  halves and the firmware cannot tell them apart
- [x] Design review — findings below
- [x] Git commit

### Design review — findings, all accepted as-is

Nothing blocking, and none of it is being fixed: reviewed and deliberately left.

- **`J1` pin 1 unconnected on both boards**, one ERC error each. Deliberate — 7 signals
  over 8 conductors, and the eighth has no job to do. Running GND down it would achieve
  nothing: the right half has no ground net, so the wire would terminate in nothing. The
  return path for a scanned row is the column conductor it is switched into, so every
  loop already closes through two wires of the same cable. mesa1 runs the same way.
- **Silkscreen clipped by the board edge in 4 places** — A1's front silk at the left's
  inner edge, `J1`'s back silk on both boards. Cosmetic.
- **Mounting hole designators disagree between the halves** — H1/H2/H3/H5 on the left,
  H2/H4/H5/H6 on the right, left over from deleting different subsets of mesa2's six.
  The holes themselves are mirrored exactly; only the names differ.
- **The RJ-45 sits 0.300 mm off exact mirror**, uniformly, where the keys, holes and
  notches mirror to the micron. Harmless inside a 5 mm relief notch.
- **Four dangling 0.0254 mm wire stubs** — three on the left, one on the right. They are
  in the *schematic*, not on the boards, so they cost an ERC line each and nothing more.
- Inherited from mesa2 Rev B on the left: GP2/GP3 floating, `A1` GND2 on no net,
  `LED4` DOUT, `J2` pin 6, and `GND` without a `PWR_FLAG`.

**The "unconnected GND" DRC item is a false positive — do not chase it.** The symbol
ties the Tiny2040's GND pads into one net, so DRC wants copper between them, but the
module commons them internally and the board does not need to. The same item appears on
mesa2. A DRC exclusion is the only thing that would silence it.

Deferred until the boards exist: the case/plate models, and the keymap itself.

## Fab batch — ordered

**Ordered 2026-09-07**, immediately after the export, and the boards are in transit.
Three boards, not four: mesa2x was dropped before the order.

- [x] Same `.kicad_dru` and stackup across all boards — the three `.kicad_dru` files are
  byte-identical, and all three are 1.6 mm two-layer
- [x] Each board's silkscreen carries its name and rev, so the bare boards are
  distinguishable on arrival — `Mesa2/Rev B`, `Mesa3-left/Rev A`, `Mesa3-right/Rev A`
- [x] Fabrication Toolkit outputs for each board; bare PCBs, not assembly — the sockets
  and 1N4148Ws are hand-soldered (confirm at order time)
- [ ] 3D viewer sanity check on each board — done or skipped at order time, not recorded
- [x] Place the order
- [x] Git commit the production outputs with the order date — `mesa2_B.zip`,
  `mesa3-left_A.zip` and `mesa3-right_A.zip` are committed

Note that `mesa2x`'s silkscreen still reads `Mesa2 / Rev B` rather than naming itself.
It was never fabbed, so nothing came of it, but a revival would have to fix that first.

## Mesa 3 Rev B

Opened 2026-09-14, once Rev A had shipped. The letter was bumped on both halves before
any design change, so the boards arriving from the fab stay identifiable as Rev A.

### The change: a mode key per hand

**One extra key per half, immediately inboard of the near-row index key** (`SW_LE1` /
`SW_RE1`), for mode switching. It is a layer key, momentary or toggle, and it is
explicitly **not** part of chording — the lateral reach from the index home position is
too uncomfortable to chord from. This is the standing intent for every future board,
recorded before Rev A was routed and deliberately left out of it.

**It costs no GPIO and no cable conductor.** The Dosh layout dropped mesa2's outer pinky
`R`, leaving one empty slot per half in the 5 × 4 grid — 18 keys in 20 slots. Checked
against the Rev A netlists rather than assumed:

| half | pinky `A` sits at | free slot | conductors added |
|---|---|---|---|
| left | `COL_1` × `ROW_B` | **`COL_1` × `ROW_A`** | none — both local to the left |
| right | `COL_1` × `ROW_D` | **`COL_1` × `ROW_C`** | none — `COL_1` and `ROW_C` already cross |

Physical position and matrix position need not agree; the pinky column simply runs a
trace over to the index side. The right half's new key is free across the cable because
every net it needs is already one of the seven that cross.

Each new key still needs **its own diode**. "Does not chord" is a statement about chord
resolution in firmware, not licence to skip ghosting isolation.

### What this does to the firmware invariant

Rev A's hard constraint was that *the firmware must not be able to tell a mesa2 Rev B
from a Mesa 3* — one keymap, one build, no board-specific code. Adding these keys does
**not** break it, but it does bend it, and the distinction is worth stating:

- The grid is still 5 × 4, and all 18 existing keys keep their exact mesa2 `(column,
  row)`. Nothing is renumbered and no existing key moves.
- The two new keys land in slots that mesa2 Rev B and Mesa 3 Rev A simply **never
  assert**. One keymap therefore still serves every board; the mode key is unreachable
  on the boards that lack it, rather than wrong.
- So the invariant survives in the direction that matters (one build), but the keyboards
  are no longer feature-identical. A mesa2 Rev B has no mode key and whatever the mode
  key unlocks has to stay reachable some other way, or that board loses the function.

Decide this before routing, not after.

### Open before anything is routed

- [ ] **Name the key.** Every other ref follows the Dosh key name (`SW_LA1`, `SW_LE1`).
  Reusing `R` would be actively confusing — that was the outer pinky the layout deleted.
- [ ] **One hand or both.** Symmetry argues for both, and both are free; the input method
  may only want one. If only one, the other half's slot stays empty and mirroring breaks.
- [ ] **Placement, generated not nudged.** Geometry comes from the layout script, and the
  `LAYOUT.md` invariant (every left/right pair sums to 270.000 in x, shares a y, negates
  rotation) has to hold for the new pair too.
- [ ] **Mechanical clearance — the left half is the constrained one.** Inboard of
  `SW_LE1` at (98.007, 76.032) the left board already carries `A1` at (135, 59.7), the
  reset pad at (130, 85), `J2` at (139.835, 95.83) and `J1` at (137.7, 104). The right
  half's inner region is nearly empty by comparison — only `H5` (152, 63), `H6`
  (151, 105) and `J1` (132, 113.12) — so a position that clears the left will clear the
  right, and the left is what to solve first.
- [ ] Keycap gap against the 0.5 mm target, as for every other key pair.

### The interconnect stays RJ-45 — settled 2026-09-14

**The signal count does not change.** Seven still cross — five columns plus `ROW_C` and
`ROW_D` — because the new right-hand key reuses nets that already make the trip. Any
replacement connector therefore still needs **seven usable conductors**, the same bar
RJ-45 clears today with one pin spare.

**Decision: RJ-45 stays for Rev B.** USB-C was considered and set aside. The reasoning
below is kept because it is the argument, not just the answer, and because mesa3w will
have to make the same call.

The deciding point is not the pin count at all — it is **what is on the other end**. A
USB-C cable only starts to make sense if the right half gains an MCU of its own, because
then the link becomes a serial one between two smart halves, needing two or three
conductors rather than seven, and orientation stops mattering. Carrying a passive matrix
over USB-C is using a connector for something it was never shaped for. So the connector
question is really a topology question, and it should be reopened only if the right half
stops being passive.

The pin analysis, for when that question comes back:

- **A USB 2.0 C-to-C cable carries about five usable conductors** — `VBUS`, `GND`, `D+`,
  `D-` and one `CC`, plus shield. That is **fewer than the seven needed**, so if the
  cable is USB 2.0 the idea is dead on arrival regardless of how nice it is. Most cables
  sold for split keyboards are USB 2.0, because carrying one serial link is all they are
  asked to do.
- **A full-featured USB 3.x C-to-C cable** adds `SBU1`, `SBU2` and two SuperSpeed lanes
  (four pairs, eight wires), so conductors are not the constraint — there are well over
  seven.
- **Reversibility is the real problem.** A USB-C plug goes in either way up. The
  receptacle ties `A6/A7` to `B6/B7`, so `D+`/`D-` survive a flip, but `CC1`/`CC2` swap
  and the SuperSpeed lanes land on different pins depending on orientation. Devices
  normally resolve this with a CC-sensing mux. Without one, a passive matrix wired to
  those pins is a **different circuit depending on which way the user plugged it in** —
  and a matrix has no way to detect or correct that.
- **The failure mode is worse than RJ-45's.** A USB-C receptacle on a keyboard half
  invites plugging it into a real host or charger, which would put 5 V, or a PD
  negotiation, straight onto matrix lines. Nobody plugs an RJ-45 into a charger. This is
  the strongest argument for staying put.

On sourcing: Keebio is not a useful supplier for this kind of question. They publish no
datasheets to speak of — their surface-mount USB-C connector is listed with no part
number at all — because they are selling to people building from published kits rather
than designing boards. Anything of theirs would have to be characterised by continuity
test before it could be designed against, which is a poor foundation for an interconnect.

- [x] Determine what the candidate cable actually connects, then decide — moot; RJ-45
  stays, and the question is deferred to whether the right half ever gains an MCU

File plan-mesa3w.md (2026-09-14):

# The mesa3w wireless

A BLE, battery-powered spin-off of the mesa3.

**Scope, settled 2026-09-13: mesa3w is a rework of the left board only.** The right half
stays exactly as mesa3 already has it — nine keys, nine diodes, RJ-45, nothing else — and
the wired RJ-45 interconnect between the halves stays. Only the left board changes: the
Tiny2040 comes out, and an nRF52840 module, a PMIC and a cell pack go in.

This is a late reversal. The plan was two independently wireless halves in the ZMK style,
and most of the analysis below was done under that assumption. What broke it was wanting
the keyboard to **run from USB**, so that one keyboard serves a wired desk and untethered
travel. USB reaches one half; anything powering the other half is a conductor between
them, which is a cable. And once a cable is granted, a *passive* right half is strictly
better than a smart one:

- The cable carries **no power** — a passive half needs none — so the existing 7-conductor
  RJ-45 pinout carries over untouched. No TRRS, no power distribution, no battery
  paralleling, no hot-plug hazard.
- **mesa3-right needs no redesign at all.** It is already routed and reviewed.
- One module, one PMIC, one cell pack, one USB port, one board to flash.
- The cross-half wake problem, the two-transport firmware and the split pairing work all
  disappear. BLE talks only to the host.
- **The mesa3 "firmware must not be able to tell a Rev B from a Mesa 3" constraint is
  restored.** A wireless split would have broken the single 5 × 4 grid into two local
  5 × 2 matrices and forced a board-specific keymap. Keeping the right half passive keeps
  the one grid, so one keymap still serves the unibody and the split alike.

A wireless mesa2 — unibody, no cable at all — was considered and rejected as too bulky for
travel.

Original notes, kept because they still frame the requirements:

- The firmware will be based off of a zephyr port of the jolt firmware. BLE support will
  come from Zephyr, possibly learning from ZMK.
- An nRF module supporting BLE and USB device (1.1 is fine for a keyboard).
- Nordic's recent PMIC for primary cells; one or two AA NiMH fit my usage better.
- PCB will contain PMIC, LEDs, SWD Tag-Connect, the USB-C connector, and the module
  soldered directly down.
- Assembly by JLC. Key sockets can go either way depending on part availability and
  assembly cost. Hand assembly isn't difficult, just tedious.

## Parts survey — what JLC actually stocks

Checked against JLCPCB's SMT parts library on 2026-09-09. Stock numbers move, but the
*shape* of the answer is unlikely to change soon.

### The headline: nRF52840, not nRF53

The nRF52840 has a **USB 2.0 full-speed device** peripheral, the same as the nRF5340. So
the "BLE plus USB device" requirement does not force the 53 — the 52840 satisfies it, is
$2–3 cheaper, and is the part every open wireless keyboard firmware (ZMK, nrfmicro,
nice!nano) already runs on. That matters for the Zephyr port: `nrf52840` boards are the
best-trodden path in-tree.

That is fortunate, because **JLC stocks no nRF5340 module at all.**

| Part | LCSC | Package | Stock | Price |
|---|---|---|---|---|
| Raytac MDBT53-1M / -P1M / -U1M | C5355663 / C5796572 / C5768063 | LGA-65 / SMD-65P | **0** | $9–15 |
| Minew MS45SF1-nRF5340 | C9900245340 | SMD 12.5×18.5 | **0** | — |
| Holyiot 21069-nRF5340 | C9900280684 | SMD | **0** | — |
| Bare NRF5340-QKAA-R | C3015611 | AQFN-94 7×7 | 9440 | $5.24 |

Every nRF5340 *module* is a catalogue entry with zero stock — JLC would have to buy them
through global sourcing (MOQ, prepay, weeks of lead time, and no guarantee). Only the
bare die is stocked, and a bare die means designing the 2.4 GHz front end, matching
network and antenna, which is exactly what the plan says to avoid.

Same story for the nRF52840 modules that get recommended in keyboard circles: Minew
MS88SF3 (C5291489), all the JLC-Assembly-branded module entries — zero stock.

### nRF52840 modules that are actually in stock

| Part | LCSC | Size | Stock | Price |
|---|---|---|---|---|
| **Ebyte E73-2G4M08S1C** | **C356849** | 13×18 mm, ceramic ant. | **2008** | $7.06 |
| Ebyte E73-2G4M08S1CX | C2764963 | 13×18 mm, IPEX (ext. ant.) | 1542 | $6.18 |
| RF-star RF-BM-ND04 | C5441197 | 24.8×15 mm | 179 | $4.07 |
| RF-star RF-BM-ND05I | C5441194 | 24.8×15 mm | 43 | $5.86 |
| Seeed XIAO nRF52840 | C17209540 | 21×17.8 mm board | 162 | $10.44 |

**Recommendation: E73-2G4M08S1C** (`C356849`). It is the only one with comfortable
stock, it is the module nrfmicro and a pile of ZMK boards already use, and — checked
against Ebyte's user manual — it brings out everything this design needs:

- 43 castellated pads on 1.27 mm pitch, 13.0 × 18.0 mm, 4-layer, built-in ceramic
  antenna, nRF52840-QIAAC0 (aQFN-73), 1 MB flash / 256 KB RAM.
- **`VBUS` (27), `D-` (29), `D+` (31)** — the USB device port is fully exposed, so the
  USB-C receptacle wires straight to the module.
- **`VDD` (19), `VDDH` (23), `DCH`/DCCH (25)** — both the normal and high-voltage supply
  pins are out, which is what makes a USB-versus-battery power path possible at all.
- `SWD` (37), `SWC` (39), `RST` (26) — straight to the Tag-Connect.
- `XL1` (11) / `XL2` (13) for the 32.768 kHz crystal.
- 32 GPIO, of which **15 are unrestricted** — see the pin budget below.

Two things to know about it:

- The **`C` suffix is the ceramic-antenna part; `CX` is the IPEX connector** version
  needing an external antenna. Despite being $0.90 cheaper, `CX` is the wrong one here.
- **The 32.768 kHz crystal is *not* on the module.** `XL1`/`XL2` are brought out so you
  can add one. Without it the LFCLK falls back to the internal RC, which costs roughly
  **8–10 µA of extra average current** — small in absolute terms, but on a design whose
  whole point is running months off an AA, it is worth the two pads. A bare cylindrical
  32.768 kHz can be soldered across XL1/XL2 with no load caps.

The **XIAO nRF52840** deserves a mention as the "Tiny2040 of the BLE world": castellated,
in stock, and it already carries a USB-C jack and a BQ25101 Li-ion charger. That last
part is the problem — it hardwires the board to a LiPo, which is the opposite of the
AA-cell plan. Listed here in case the battery decision goes the other way.

### GPIO budget — the "low frequency I/O" restriction

The nRF52840 marks 21 of its 48 GPIOs "Standard drive, low frequency I/O only". Worth
being precise about what that means, because it is less restrictive than it sounds:

- The product spec's own footnote defines it as **"signals with a frequency up to
  10 kHz"** — not the kilohertz-or-less it is often taken for.
- Nordic's answer on DevZone is that it is **not an electrical limit at all**: "They are
  not restricted to 10 kHz, just recommended to not be set higher due to interference
  issues with the radio." These pins sit on the die edges nearest the RF output; the
  concern is desense and RF certification, not the pin's switching ability. Someone in
  that thread ran 8 MHz SPI on them without trouble.
- A key scan is nowhere near the line either way. Even an aggressive 1 kHz full-matrix
  scan toggles each column at about 1 kHz — an order of magnitude under the guideline.

So the matrix would be fine on the restricted pins. But it does not have to be, because
the E73 brings out plenty of unrestricted ones. Classifying all 32 of the module's GPIO
pads against the aQFN-73 pin table:

| | E73 pads |
|---|---|
| **Unrestricted** (18) | `P0.00`/XL1, `P0.01`/XL2, `P0.04`, `P0.05`, `P0.06`, `P0.07`, `P0.08`, `P0.12`, `P0.13`, `P0.15`, `P0.17`, `P0.18`/RESET, `P0.20`, `P0.22`, `P0.24`, `P0.26`, `P1.00`, `P1.09` |
| Low-frequency only (14) | `P0.02`, `P0.03`, `P0.09`/NFC1, `P0.10`/NFC2, `P0.28`, `P0.29`, `P0.30`, `P0.31`, `P1.02`, `P1.04`, `P1.06`, `P1.10`, `P1.11`, `P1.13` |

Three of the unrestricted eighteen are spoken for — `XL1`/`XL2` for the 32.768 kHz
crystal and `P0.18` for RESET — which leaves **15 free unrestricted GPIOs**. (`P0.22` and
`P1.00` are nominally QSPI pins, but there is no external QSPI flash on this board, so
they are ordinary I/O here.)

The left board now drives the **whole** 5 × 4 grid, both halves, over the RJ-45 — so the
matrix costs **5 columns + 4 rows = 9 pins**, not the 7 a local half would need. Add
`SWO` on Tag-Connect pin 6 and that is **10 of the 15 unrestricted pads**, leaving 5
spare. The four or five LEDs sit on the low-frequency pads and cost nothing from this
budget. GPIO is not a constraint, though it is tighter than the two-half plan would have
been.

### The PMIC — nPM2100 is real and stocked

| Part | LCSC | Package | Stock | Price |
|---|---|---|---|---|
| **NPM2100-QEAA-R7** | **C46968654** | QFN-16, 4.0×4.0 mm | 1555 | $0.92 |
| NPM2100-CAAA-R7 | C46968655 | WLCSP-16, 1.9×1.9 mm | 1179 | $0.94 |
| NPM1300-CAAA-R7 | C25346894 | WLCSP-35, 2.4×3.1 mm | 1490 | $1.57 |

**Take the QFN** (`C46968654`). The WLCSP is 0.4 mm pitch — which pushes the board into
JLC's finer-spec tier — and Nordic's datasheet carries an explicit warning that the WLCSP
is sensitive to visible and near-IR light and must be shielded from it in the final
product. Neither is worth it to save 14 mm² on a keyboard.

From the datasheet (v0.7 preliminary / v1.0):

- Boost: **0.7–3.4 V in, 1.8–3.3 V out, 150 mA max**, with automatic pass-through when
  the cell is above the target.
- **`VSET` open = 3.0 V out, `VSET` grounded = 1.8 V out.** Set at power-on-reset by a
  pin, so the 3.0 V rail comes up with no firmware and no I²C traffic at all.
- Separate LDO/load switch, 0.8–3.0 V at up to 50 mA — a natural software-controlled
  supply for the RGB LEDs.
- 150 nA quiescent, 35 nA ship mode (so the board can ship with cells installed), plus
  battery-voltage/temperature measurement feeding Nordic's fuel gauge.
- Externals are trivial: one **2.2 µH inductor (DCR < 150 mΩ, I_sat > 0.55 A)** and five
  ceramics. JLC has dozens of suitable inductors at ~$0.02 (e.g. C2826618, C354563).
- Nordic's own example battery is "two alkaline AA/AAA in series or one CR2032". **Two
  AA NiMH in series is 2.4 V nominal, 1.8–2.9 V over their discharge — dead centre of the
  input range.** A single NiMH cell at 1.2 V also works and is what the part is tuned
  for, it just carries half the energy.

**The catch: the nPM2100 has no charger and no VBUS input.** It is a boost for cells you
replace, not cells you recharge in place. If charging over USB is a requirement, the part
is the **nPM1300** (`C25346894`, in stock) with a Li-ion cell — but that abandons the AA
NiMH idea, since neither Nordic PMIC can charge NiMH.

### The LEDs — plain 3535 LEDs, not SK6812

Two independent reasons the SK6812s go, and it is worth separating them because only one
is about the protocol:

1. **The protocol.** SK6812/WS2812 one-wire is timing-critical bit-banging with no
   peripheral support on Nordic silicon.
2. **The quiescent draw.** An integrated controller is a live IC on every LED, roughly
   1 mA each doing nothing. Four of them is ~4 mA of pure idle drain — enough to flatten
   two AA NiMH in about three weeks with the keyboard never once typed on, against the
   ~30 µA floor worked out further down.

**No integrated I²C-addressable LED exists in a 3535 package.** Every smart LED in that
size (SK6812MINI, WS2812B-MINI, WS2813B-MINI, TZ-3535S2RGB) is one-wire. The **APA102 /
SK9822** family solves reason 1 properly — plain 2-wire SPI, no timing sensitivity, an
in-tree Zephyr driver — and it does exist in 3535 (`SK9822MINI-HB`, `C42457611`), JLC
simply stocks none of them, nor any APA102 including the 2020. Hand assembly would keep
them on the table, and four LEDs is a trivial hand-solder. But reason 2 disqualifies them
regardless of stock: they are still a controller per LED.

**So: plain, dumb 3535 RGB LEDs**, driven from the nRF's own PWM — see *LEDs: at four or
five* further down for that decision and its numbers.

| LED | LCSC | Package | Stock | Price |
|---|---|---|---|---|
| **NationStar RS-3535MWAR** | **C110402** | SMD3535-6P | 518829 | $0.051 |
| NationStar NH-Z3535RGBA-SG | C2874123 | SMD3535-6P | 38208 | $0.013 |
| TCWIN TC3535RGBE07-3CJH-E01 | C784546 | SMD3535-6P | 10958 | $0.031 |

Six-pin parts: three dies with both terminals brought out, so they will wire to anything —
GPIO with series resistors, or a current-sink driver with the anodes commoned. `C110402`
has half a million in stock.

Two notes carried forward:

- **Confirm forward voltages against the 3.0 V rail at schematic time.** Red is
  comfortable; blue and green sit around 3.0–3.2 V and will be marginal. This may end up
  being the real argument for setting the boost to 3.3 V rather than leaving `VSET` open
  for 3.0 V.
- **No MOSFET rail cut is needed.** A GPIO configured as an input is already an open
  circuit, so "off" costs nothing. That was only ever required to tame the SK6812s'
  quiescent draw, which no longer exists.

**Fallback if the LED count grows:** a TI LP50xx constant-current sink driver over I²C —
**LP5009** (9 channels, `C701960`, WQFN-20-EP 3×3, 2455 in stock, $0.43) or **LP5012**
(12 channels, `C1849481`, 1340 in stock, $0.64). Twelve channels is exactly four RGB LEDs
with nothing wasted, per-channel current is set in registers so the ceiling is enforced in
hardware, and shutdown is 0.2 µA. It buys back GPIO and lets the LEDs run while the MCU
sleeps, at the cost of an IC and an I²C bus. The crossover is around six channels.

### Consequences for the rest of the board

- **The 150 mA boost ceiling has stopped being a problem.** Four or five indicator LEDs
  at a milliamp or so apiece is single-digit mA, and the series resistors fix the ceiling
  in hardware. The nRF52840 itself peaks around 17 mA transmitting at +8 dBm. Total peak
  draw now sits an order of magnitude under the boost's limit.
- The module's 13 × 18 mm ceramic-antenna footprint wants keep-out: no copper pour, no
  ground plane and no battery under the antenna end.
- USB-C, Tag-Connect and the reset pad carry over from mesa3 unchanged.

### Rough BOM delta

One board's worth — the right half gains nothing.

| | LCSC | ~$ |
|---|---|---|
| E73-2G4M08S1C | C356849 | 7.06 |
| NPM2100-QEAA-R7 | C46968654 | 0.92 |
| 2.2 µH inductor + 5 ceramics | — | ~0.10 |
| 32.768 kHz crystal | — | ~0.10 |
| 4–5 × 3535 LED + series resistors | C110402 etc. | ~0.25 |
| Ship/power button (SHPHLD) | — | ~0.05 |
| 2 × profiler break point | — | ~0 |
| USB LDO + P-FET switchover | — | ~0.20 |
| | | **~$8.65** |

All of these are extended parts, not basic — so budget JLC's per-unique-extended-part
loading fee on top.

## Sleep, wake, and where the current actually goes

### Wake-on-keypress: drive all columns, sense the rows

The standard trick, and the right one here. Before idling, drive **every column at once**
and configure **every row as an input with its internal pull resistor and `SENSE`
enabled** for the opposite level. Any key closing anywhere in the matrix drags its row to
the driven level, `DETECT` fires, and the part wakes. No scanning, no timer, one event
for the whole matrix. Scanning resumes only once awake.

**Which polarity depends on the diodes, and mesa3's are already committed.** Pulled from
`mesa3-right/production/netlist.ipc`, which is unambiguous:

```
327/ROW_D            SW_RT1-1     switch pin 1  -> ROW_D
327NET-(D_RT1-A)     SW_RT1-2     switch pin 2  -> diode ANODE
327NET-(D_RT1-A)     D_RT1-2      diode pin 2 = A (anode)
327/COL_3            D_RT1-1      diode pin 1 = K (cathode) -> COL_3
```

The path is **row → switch → anode → cathode → column**, so the diodes conduct from row
to column. Current can only flow when the row sits above the column, which means
**columns driven LOW, rows pulled UP, sensing for LOW** — active-low, not active-high.
Driving the columns high with this orientation reverse-biases every diode and detects
nothing, which is the failure mode to avoid.

That is a statement about mesa3 as built, not a law. mesa3w is a new board and the diodes
can be flipped — anode to the column, cathode to the switch — which gives active-high
sensing with pull-downs on the rows. The nRF52840 supports both (`PIN_CNF.SENSE` = 2 for
high, 3 for low) and its pull-up and pull-down are both 11–16 kΩ, so there is no
electrical reason to prefer one. The only requirement is that the diode orientation and
the sense polarity agree. Reusing mesa3's footprints and orientation means active-low;
choosing active-high means deliberately reversing every diode and saying so on the
schematic.

**The one number that matters:** use the GPIO **`PORT` event** (the `SENSE`/`DETECT`
latch), not per-pin `GPIOTE IN` events. From the nRF52840 PS's own measured idle
currents at 3 V:

| Mode | Current |
|---|---|
| System ON, full RAM retention, wake on **GPIOTE `PORT`** | **2.36 µA** |
| System ON, full RAM retention, wake on GPIOTE `IN` | 17.37 µA |
| System ON, full RAM retention, wake on RTC | 3.16 µA |
| System ON, full RAM retention, wake on any event | 2.35 µA |
| System OFF, full RAM retention, wake on reset | 1.86 µA |
| System OFF, no RAM retention, wake on reset | 0.40 µA |

Identical functionality, 7× the current, purely from picking the wrong wake source.
`GPIOTE IN` needs the high-frequency clock running to catch edges; `PORT` is a
level-latch in the always-on domain, which is also why it works from System OFF.

Two things to check against the schematic:

- **A key held down during idle is a real drain.** The internal pull-up is 11–16 kΩ
  (13 kΩ typ), so one closed switch against a driven column sinks about **180 µA at
  3.0 V** once the diode drop is taken off — nearly a hundred times the idle current,
  indefinitely. Something resting on the
  keyboard in a bag will flatten it. Worth a firmware guard: if `DETECT` re-fires
  immediately and the same key is still down after a scan, mask that column out. The
  power button below is the better answer for anything longer than a desk-drawer.

### The power button is already in the PMIC

The Apple-keyboard arrangement — a real off switch alongside the firmware's sleep — comes
free with the nPM2100. Its **`SHPHLD` pin is a multifunction single-button input**:

- Hold ~2 s and release → **Ship mode, 35 nA**, boost off, rail dead. A genuine off.
- Press again → wake, cold start, rail comes back up.
- Hold for `tRST_DEB_L` (default 10 s) → hard reset, for when firmware has wedged.

One button, one net, no firmware involvement, and it works even if the MCU is hung. It
also disposes of the held-key drain: a keyboard going into a bag gets switched off rather
than left to sink ~180 µA through a pull-up.

**Layout caveat:** `SHPHLD` is an analog pin with an absolute maximum of 1.9 V, well under
the 3.0 V rail. The button goes from `SHPHLD` to ground, using the pin's internal pull-up
(both pull-up and pull-down are register-controlled). Do not tie it to the rail.

### Cross-half wake: moot, and worth recording why

**The passive right half removes this problem rather than solving it.** There is one
matrix, driven entirely from the left board over the RJ-45, so a single `PORT` event
covers all eighteen keys. A key on the right pulls a row low through the cable exactly as
a key on the left does. There is no second MCU to wake and no radio involved.

Kept because it was the strongest argument against the two-wireless-halves plan, and
because it still constrains System OFF:

> System OFF means the radio is off, so a keypress on one half cannot reach a
> deep-sleeping other half over BLE. That is physics, not a firmware gap. ZMK's tracker
> position is "key presses on a peripheral keeps the central awake but not the reverse",
> alongside open bugs about the central failing to wake at all — the source of the "press
> a key on each side" behaviour split wireless keyboards are known for.

**System OFF still is not worth it, for the remaining reason.** System ON with full RAM
retention and `PORT` wake is 2.36 µA; System OFF with RAM retention is 1.86 µA. Half a
microamp, against the cost of a sleep state machine, a lost first keypress and a
multi-second BLE reconnect. On a 110 mAh LiPo that trade makes sense, which is why ZMK
takes it; on two AA it is noise.

So the board stays in System ON, idling at ~2.4 µA between keypresses with the BLE link to
the host held up, and duty-cycles the radio with connection parameters rather than power
modes.

### The current budget

The radio, not the CPU, is the whole story — and there is now exactly **one** link, to the
host. Nordic's power profiler and measurements on DevZone put a 20 ms connection interval
with no peripheral latency at roughly **226–320 µA** average just to hold a link up.
Peripheral latency is the knob: skipping *n* of every *n+1* connection events divides that
cost by about *n+1*, so a 20 ms interval with latency 9 behaves like 200 ms when nothing is
being typed and drops into the tens of µA, while snapping back to 20 ms the moment a key
goes down.

Scanning the right half's nine keys over the cable adds essentially nothing: the columns
are driven only during a scan, and in idle they sit driven with no current flowing until a
switch closes. Cat5's ~50 pF/m of capacitance is irrelevant at keyboard scan rates.

Against two AA NiMH (2000 mAh at 2.4 V = 4.8 Wh, ≈1.44 Ah at the 3.0 V rail after the
boost's ~90%):

| Average rail current | Runtime, 2×AA | Runtime, 1×AA |
|---|---|---|
| 50 µA (idle, long effective interval) | ~26 months | ~13 months |
| 250 µA (link held tight, no latency) | ~7 months | ~3.5 months |
| 500 µA (busy typing) | ~4 months | ~2 months |

One cell pack now runs the entire keyboard, both halves — but it also only feeds one
radio link instead of two, so the figures above are the whole keyboard rather than one
half of it.
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

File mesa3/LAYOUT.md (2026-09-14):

# mesa3 — reference geometry

Geometry for both halves of the Mesa 3. The keys are inherited wholesale from mesa2
Rev B — this file records where they ended up once the board was cut in two, and what
survived the split unchanged.

Companion to `DESIGN.md`, which holds the decisions rather than the coordinates.

KiCad convention throughout: **+X is right, +Y is down.**

## The frame both halves share
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

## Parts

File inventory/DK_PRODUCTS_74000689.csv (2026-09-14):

Index | DigiKey Part # | Manufacturer Part Number | Description | Customer Reference | Quantity | Backorder | Unit Price | Extended Price
1 | 2648-SC0915CT-ND | SC0915 | RASPBERRY PI PICO RP2040 |  | 4 | 0 | $4.00000 | $16.00
 |  |  |  |  |  |  | Subtotal | $16.00

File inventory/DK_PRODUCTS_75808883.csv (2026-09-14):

Index | DigiKey Part # | Manufacturer Part Number | Description | Customer Reference | Quantity | Backorder | Unit Price | Extended Price
1 | 497-B-U585I-IOT02A-ND | B-U585I-IOT02A | STM32U5 DISCOVERY KIT FOR IOT |  | 1 | 0 | $65.00000 | $65.00
 |  |  |  |  |  |  | Subtotal | $65.00

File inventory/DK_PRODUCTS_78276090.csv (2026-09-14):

Index | DigiKey Part # | Manufacturer Part Number | Description | Customer Reference | Quantity | Backorder | Unit Price | Extended Price
1 | S6100-ND | PPTC121LFBN-RC | CONN HDR 12POS 0.1 TIN PCB |  | 8 | 0 | $0.78000 | $6.24
2 | 1655-BAV19WCT-ND | BAV19W | DIODE GEN PURP 100V 200MA SOD123 |  | 70 | 0 | $0.19100 | $13.37
 |  |  |  |  |  |  | Subtotal | $19.61

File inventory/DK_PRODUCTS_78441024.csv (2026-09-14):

Index | DigiKey Part # | Manufacturer Part Number | Description | Customer Reference | Quantity | Backorder | Unit Price | Extended Price
1 | 2648-SC0914(7)CT-ND | SC0914(7) | IC MCU 32BIT EXT MEM 56QFN |  | 3 | 0 | $1.00000 | $3.00
2 | W25Q128JVPIQCT-ND | W25Q128JVPIQ TR | IC FLASH 128MBIT SPI/QUAD 8WSON |  | 3 | 0 | $2.04000 | $6.12
3 | CTX1170CT-ND | 445I23D12M00000 | CRYSTAL 12.0000MHZ 18PF SMD |  | 3 | 0 | $0.76000 | $2.28
4 | 380-SS-52400-003CT-ND | SS-52400-003 | CONN USB TYPE C RT. ANGLE JACK |  | 6 | 0 | $2.55000 | $15.30
5 | AP2112M-3.3TRG1DICT-ND | AP2112M-3.3TRG1 | IC REG LINEAR 3.3V 600MA 8SOIC |  | 3 | 0 | $0.42000 | $1.26
6 | BAT60AE6327HTSA1CT-ND | BAT60AE6327HTSA1 | DIODE SCHOTTKY 10V 3A SOD323-2 |  | 3 | 0 | $0.50000 | $1.50
7 | CKN10244CT-ND | KMR221NG LFS | SWITCH TACTILE SPST-NO 0.05A 32V |  | 6 | 0 | $0.44000 | $2.64
8 | S7000-ND | PPTC021LFBN-RC | CONN HDR 2POS 0.1 TIN PCB |  | 12 | 0 | $0.27500 | $3.30
9 | 732-4987-1-ND | 150080YS75000 | LED YELLOW CLEAR 0805 SMD |  | 3 | 0 | $0.19000 | $0.57
10 | 732-4986-1-ND | 150080VS75000 | LED GREEN CLEAR 0805 SMD |  | 3 | 0 | $0.19000 | $0.57
11 | 1276-1076-1-ND | CL05A105KP5NNNC | CAP CER 1UF 10V X5R 0402 |  | 12 | 0 | $0.03600 | $0.43
12 | 1276-1108-1-ND | CL05A225KP5NSNC | CAP CER 2.2UF 10V X5R 0402 |  | 3 | 0 | $0.15000 | $0.45
13 | 478-KGM05ACG1H270KHCT-ND | KGM05ACG1H270KH | CAP CER 27PF 50V C0G/NP0 0402 |  | 10 | 0 | $0.03900 | $0.39
14 | 1276-1043-1-ND | CL05A104KA5NNNC | CAP CER 0.1UF 25V X5R 0402 |  | 50 | 0 | $0.00540 | $0.27
15 | RMCF0402ZT0R00CT-ND | RMCF0402ZT0R00 | RES 0 OHM JUMPER 1/16W 0402 |  | 10 | 0 | $0.01000 | $0.10
16 | YAG3271CT-ND | RC0402JR-07110RL | RES 110 OHM 5% 1/16W 0402 |  | 10 | 0 | $0.01200 | $0.12
17 | 311-1.0KJRCT-ND | RC0402JR-071KL | RES 1K OHM 5% 1/16W 0402 |  | 10 | 0 | $0.01200 | $0.12
18 | 311-10KJRCT-ND | RC0402JR-0710KL | RES 10K OHM 5% 1/16W 0402 |  | 10 | 0 | $0.01200 | $0.12
19 | 311-5.10KLRCT-ND | RC0402FR-075K1L | RES 5.1K OHM 1% 1/16W 0402 |  | 10 | 0 | $0.01500 | $0.15
20 | YAG3086CT-ND | RC0402FR-0727RL | RES 27 OHM 1% 1/16W 0402 |  | 10 | 0 | $0.01500 | $0.15
21 | 13-RC0402FR-13200RLCT-ND | RC0402FR-13200RL | RES 200 OHM 1% 1/16W 0402 |  | 10 | 0 | $0.01500 | $0.15
 |  |  |  |  |  |  | Subtotal | $38.99

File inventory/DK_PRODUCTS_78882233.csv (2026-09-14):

Index | DigiKey Part # | Manufacturer Part Number | Description | Customer Reference | Quantity | Backorder | Unit Price | Extended Price
1 | CKN10244CT-ND | KMR221NG LFS | SWITCH TACTILE SPST-NO 0.05A 32V |  | 10 | 0 | $0.44000 | $4.40
2 | 160-1446-1-ND | LTST-C191KGKT | LED GREEN CLEAR SMD |  | 10 | 0 | $0.14100 | $1.41
3 | 160-1447-1-ND | LTST-C191KRKT | LED RED CLEAR SMD |  | 10 | 0 | $0.14100 | $1.41
4 | 1276-1043-1-ND | CL05A104KA5NNNC | CAP CER 0.1UF 25V X5R 0402 |  | 100 | 0 | $0.00450 | $0.45
5 | 1276-1119-1-ND | CL10A106MQ8NNNC | CAP CER 10UF 6.3V X5R 0603 |  | 10 | 0 | $0.08300 | $0.83
6 | 1276-1102-1-ND | CL10A105KA8NNNC | CAP CER 1UF 25V X5R 0603 |  | 100 | 0 | $0.01400 | $1.40
7 | 1276-2247-1-ND | CL10C270JB81PNC | CAP CER 27PF 50V C0G/NP0 0603 |  | 50 | 0 | $0.02500 | $1.25
8 | BAT60AE6327HTSA1CT-ND | BAT60AE6327HTSA1 | DIODE SCHOTTKY 10V 3A SOD323-2 |  | 10 | 0 | $0.40900 | $4.09
9 | 311-5.1KGRCT-ND | RC0603JR-075K1L | RES 5.1K OHM 5% 1/10W 0603 |  | 100 | 0 | $0.00700 | $0.70
10 | 311-27GRCT-ND | RC0603JR-0727RL | RES 27 OHM 5% 1/10W 0603 |  | 100 | 0 | $0.00700 | $0.70
11 | 311-200GRCT-ND | RC0603JR-07200RL | RES 200 OHM 5% 1/10W 0603 |  | 100 | 0 | $0.00700 | $0.70
12 | 13-RC0603JR-131KLCT-ND | RC0603JR-131KL | RES 1K OHM 5% 1/10W 0603 |  | 100 | 0 | $0.00700 | $0.70
13 | 13-RC0603JR-1310KLCT-ND | RC0603JR-1310KL | RES 10K OHM 5% 1/10W 0603 |  | 100 | 0 | $0.00700 | $0.70
14 | 2073-USB4085-GF-ACT-ND | USB4085-GF-A | CONN RCPT USB2.0 TYPE C 16+8POS |  | 10 | 0 | $0.79200 | $7.92
15 | 2648-SC0914(7)CT-ND | SC0914(7) | IC MCU 32BIT EXT MEM 56QFN |  | 5 | 0 | $1.00000 | $5.00
16 | AP2112M-3.3TRG1DICT-ND | AP2112M-3.3TRG1 | IC REG LINEAR 3.3V 600MA 8SOIC |  | 10 | 0 | $0.36100 | $3.61
17 | W25Q128JVPIQ-ND | W25Q128JVPIQ | IC FLASH 128MBIT SPI/QUAD 8WSON |  | 5 | 0 | $1.76000 | $8.80
18 | CTX1162CT-ND | 445C25D12M00000 | CRYSTAL 12.0000MHZ 18PF SMD |  | 5 | 0 | $0.68000 | $3.40
 |  |  |  |  |  |  | Subtotal | $47.47

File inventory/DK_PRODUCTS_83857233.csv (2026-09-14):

Index | DigiKey Part # | Manufacturer Part Number | Description | Customer Reference | Quantity | Backorder | Unit Price | Extended Price
1 | 899-8.19.00-ND | 8.19.00 | J-LINK BASE COMPACT |  | 1 | 0 | $498.00000 | $498.00
2 | 899-8.06.02-ND | 8.06.02 | J-LINK 9-PIN CORTEX-M ADAPTER |  | 1 | 0 | $40.40000 | $40.40
3 | 1528-1429-ND | 2743 | BOARD BO SWD 2X5 1.27MM CBL |  | 5 | 0 | $2.95000 | $14.75
4 | 609-3695-1-ND | 20021121-00010C4LF | CONN HEADER SMD 10POS 1.27MM |  | 5 | 0 | $0.99000 | $4.95
 |  |  |  |  |  |  | Subtotal | $558.10

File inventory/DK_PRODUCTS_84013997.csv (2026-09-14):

Index | DigiKey Part # | Manufacturer Part Number | Description | Customer Reference | Quantity | Backorder | Unit Price | Extended Price
1 | 1528-4884-ND | 4884 | ADAFRUIT FEATHER RP2040 |  | 5 | 0 | $11.95000 | $59.75
2 | 1528-2827-ND | 4048 | CONN HEADER SMD 10POS 1.27MM |  | 5 | 0 | $1.95000 | $9.75
 |  |  |  |  |  |  | Subtotal | $69.50

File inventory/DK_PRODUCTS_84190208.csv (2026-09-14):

Index | DigiKey Part # | Manufacturer Part Number | Description | Customer Reference | Quantity | Backorder | Unit Price | Extended Price
1 | 1528-2009-ND | 1675 | 10-PIN 2X5 SOCKET-SOCKET 1.27MM |  | 2 | 0 | $2.95000 | $5.90
2 | 1528-5384-ND | 5384 | STEMMA QT/QWIIC CABLE 300MM |  | 4 | 0 | $1.25000 | $5.00
3 | BAV19WTPMSCT-ND | BAV19W-TP | DIODE GEN PURP 100V 200MA SOD123 |  | 200 | 0 | $0.06670 | $13.34
4 | 455-SM05B-SRSS-TBCT-ND | SM05B-SRSS-TB | CONN HEADER SMD R/A 5POS 1MM |  | 6 | 0 | $0.71000 | $4.26
 |  |  |  |  |  |  | Subtotal | $28.50

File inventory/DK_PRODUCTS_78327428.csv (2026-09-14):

Index | DigiKey Part # | Manufacturer Part Number | Description | Customer Reference | Quantity | Backorder | Unit Price | Extended Price
1 | 568-15287-ND | LPC55S69-EVK | LPCXPRESSO LPC55S6X EVAL BRD |  | 1 | 0 | $47.65000 | $47.65
 |  |  |  |  |  |  | Subtotal | $47.65

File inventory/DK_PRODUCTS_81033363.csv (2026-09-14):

Index | DigiKey Part # | Manufacturer Part Number | Description | Customer Reference | Quantity | Backorder | Unit Price | Extended Price
1 | 1490-NRF5340-DK-ND | NRF5340-DK | DEV KIT FOR NRF5340 |  | 1 | 0 | $49.00000 | $49.00
 |  |  |  |  |  |  | Subtotal | $49.00

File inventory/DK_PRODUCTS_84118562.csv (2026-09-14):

Index | DigiKey Part # | Manufacturer Part Number | Description | Customer Reference | Quantity | Backorder | Unit Price | Extended Price
1 | 609-5081-ND | 54601-908WPLF | CONN MOD JACK 8P8C R/A UNSHLD |  | 4 | 0 | $0.69000 | $2.76
2 | 609-5080-ND | 54601-906002WPLF | CONN MOD JACK 6P4C R/A UNSHLD |  | 4 | 0 | $0.42000 | $1.68
3 | 1276-1000-1-ND | CL10B104KB8NNNC | CAP CER 0.1UF 50V X7R 0603 |  | 100 | 0 | $0.01140 | $1.14
4 | 1528-4650-ND | 4650 | ADAFRUIT FEATHERWING OLED - 128X |  | 1 | 0 | $14.95000 | $14.95
 |  |  |  |  |  |  | Subtotal | $20.53

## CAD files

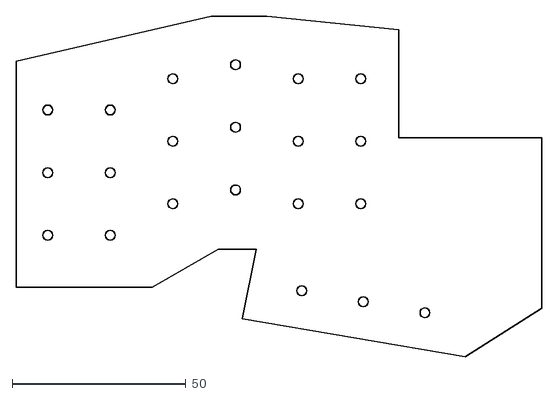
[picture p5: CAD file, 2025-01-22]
jolt2/jolt2-left/jolt2-left-Edge_Cuts.dxf
151.0 x 98.0

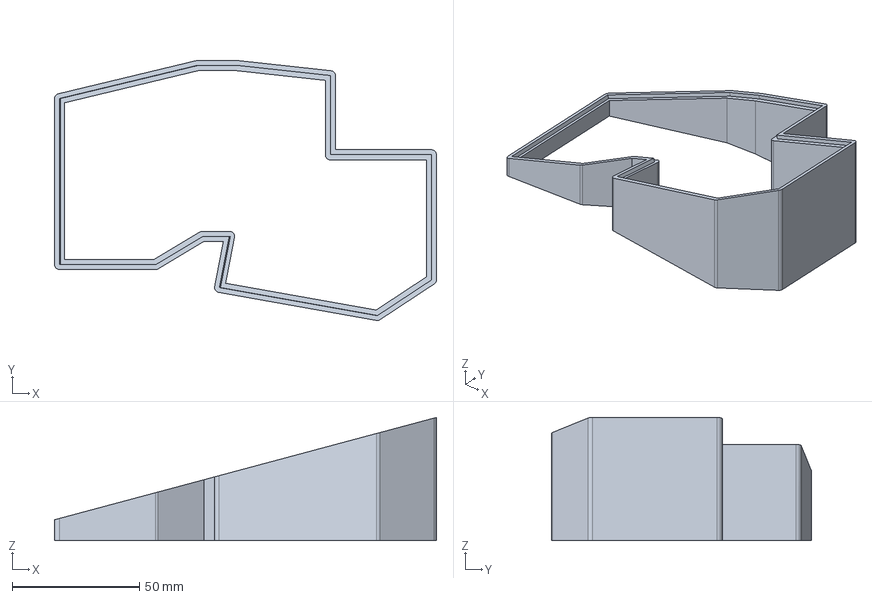
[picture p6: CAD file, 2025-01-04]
jolt2/jolt2-pm2350-left/stand1.FCStd
149.9 x 102.0 x 48.3 mm

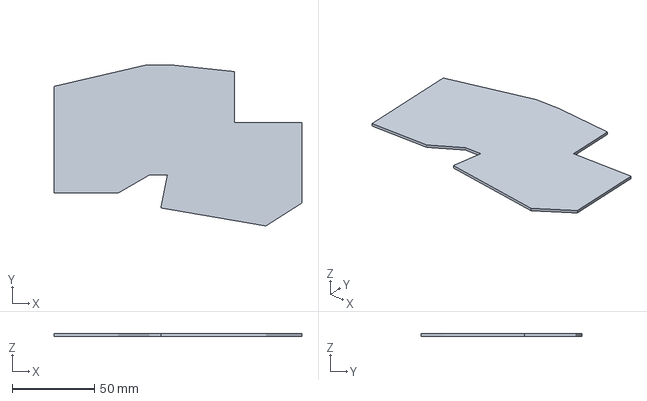
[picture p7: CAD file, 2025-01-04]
jolt2/jolt2-tiny2040-left/board-case-Pad (Meshed).3mf
151.0 x 98.0 x 1.60 mm

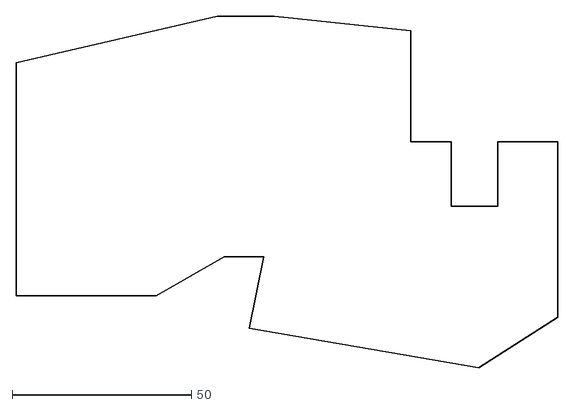
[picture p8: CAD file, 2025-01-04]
jolt2/jolt2-tiny2040-left/board-dxf/jolt2-tiny2040-left-Edge_Cuts.dxf
151.0 x 98.0

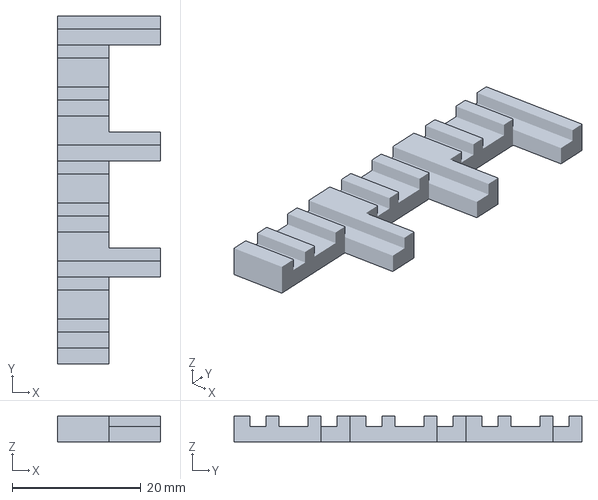
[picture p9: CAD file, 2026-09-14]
jolt2/jolt2-verts/vert-spacers-Body-4mm.3mf
16.0 x 54.0 x 4.00 mm

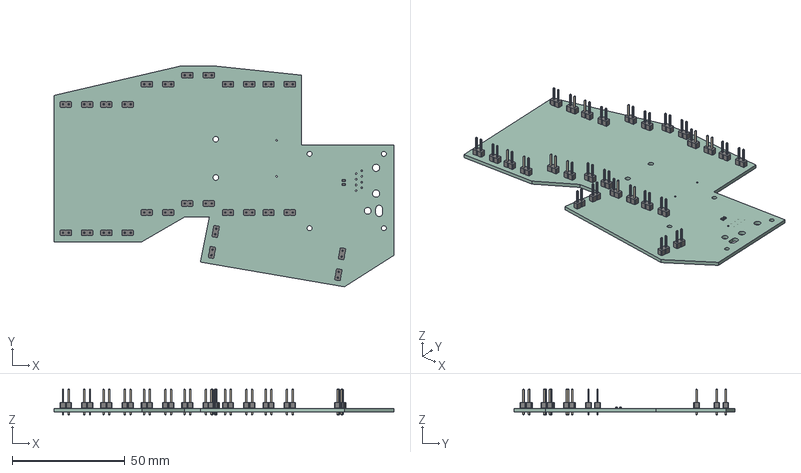
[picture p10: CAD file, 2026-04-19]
jolt3/jolt3-left/jolt3-left.step
151.0 x 98.0 x 11.5 mm
R_0603_1608Metric x 2
PinHeader_1x02_P254mm_Vertical x 28
jolt3-left_PCB

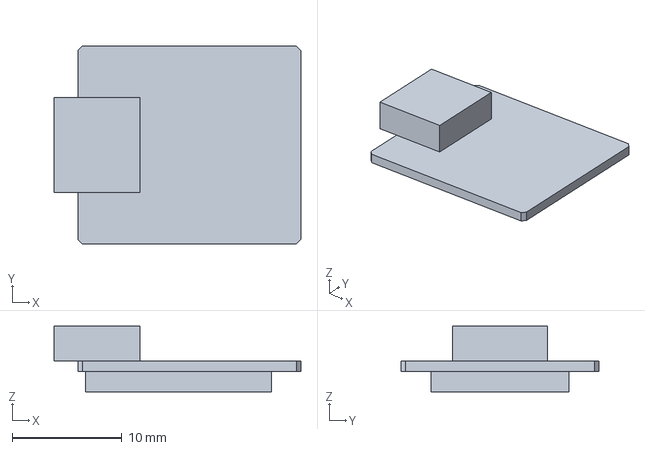
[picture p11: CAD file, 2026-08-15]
mesa1/3dmodels/Pimoroni_Tiny2040.step
22.5 x 18.0 x 6.00 mm

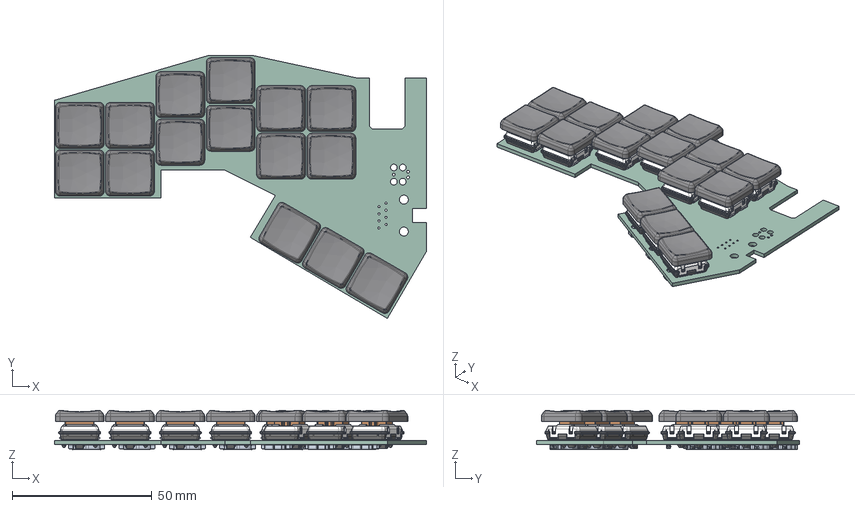
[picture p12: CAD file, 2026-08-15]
mesa1/mesa1-left/mesa1-left.step
133.0 x 94.0 x 14.1 mm
socket001 x 15
pin002 x 15
pin003 x 15
SW_Kailh_Choc_V1_cp x 15
(Unsaved) x 15
D_SOD-123 x 15
mesa1-left_PCB

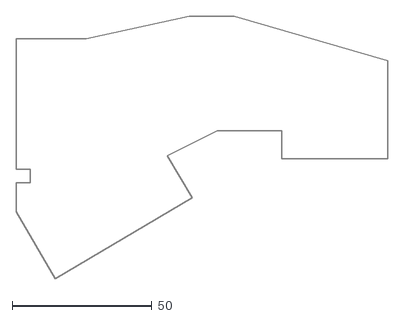
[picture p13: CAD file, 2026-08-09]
mesa1/mesa1-right-Edge_Cuts.dxf
133.0 x 94.0

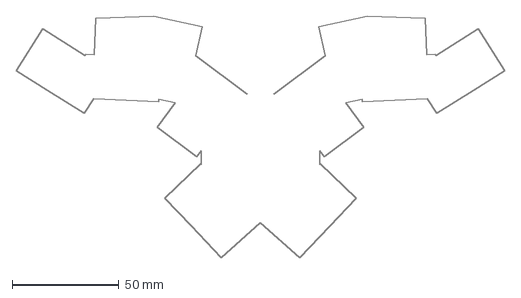
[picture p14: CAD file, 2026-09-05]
mesa2/mesa2-Edge_Cuts.dxf
228.2 x 113.0 mm

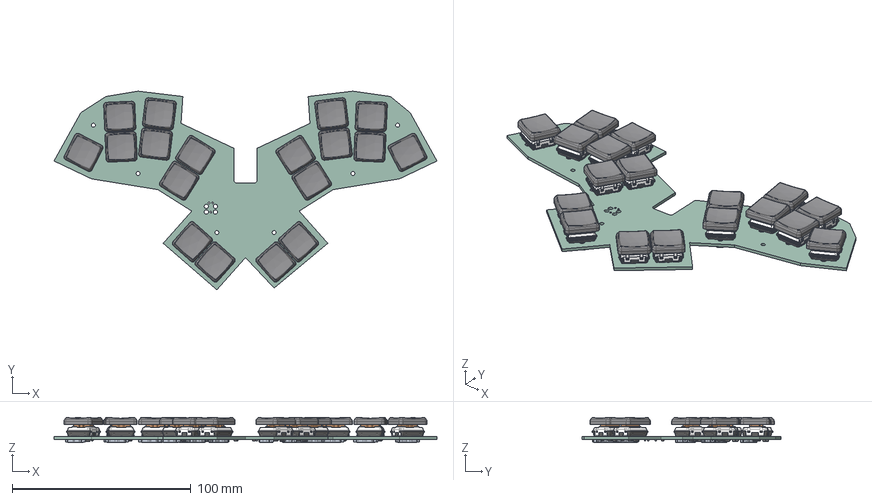
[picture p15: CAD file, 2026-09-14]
mesa2/mesa2/mesa2.step
214.0 x 111.0 x 14.1 mm
socket001 x 18
pin002 x 18
pin003 x 18
SW_Kailh_Choc_V1_cp x 18
(Unsaved) x 18
D_SOD-123 x 19
C_0603_1608Metric x 4
mesa2_PCB

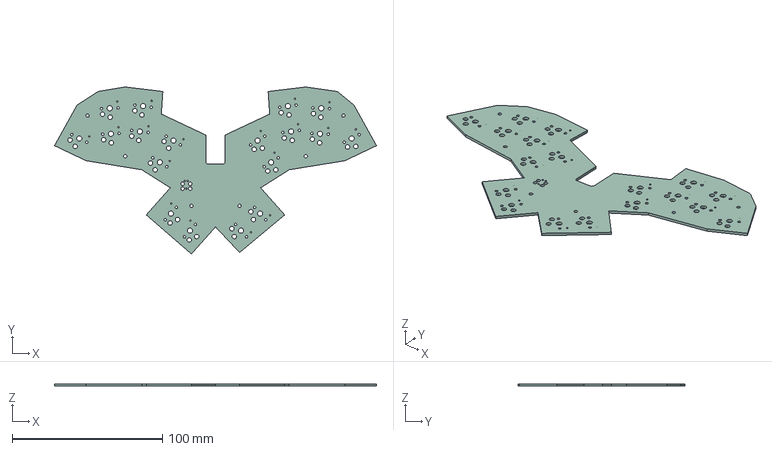
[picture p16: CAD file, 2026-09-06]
mesa2/mesa2x/mesa2x.step
214.0 x 111.0 x 1.51 mm

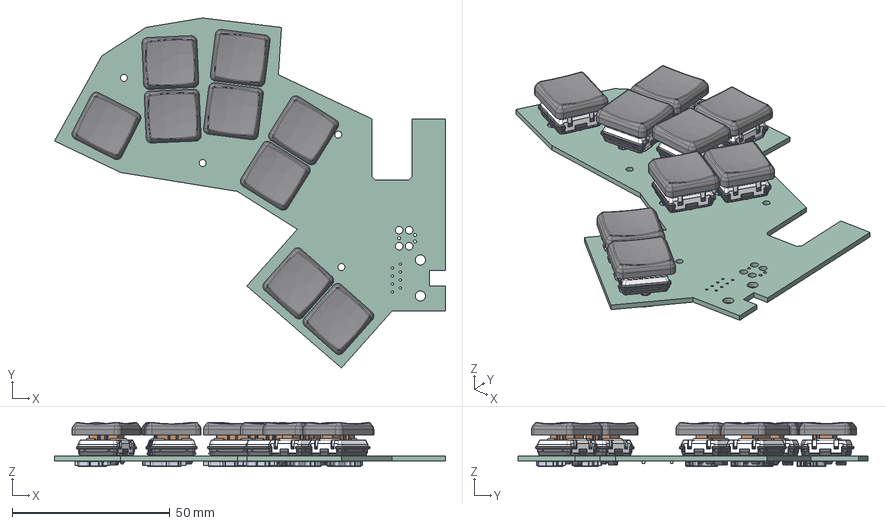
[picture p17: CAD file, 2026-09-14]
mesa3/mesa3-left/mesa3-left.step
124.0 x 111.0 x 14.1 mm
socket001 x 9
pin002 x 9
pin003 x 9
SW_Kailh_Choc_V1_cp x 9
(Unsaved) x 9
D_SOD-123 x 10
C_0603_1608Metric x 4
mesa3-left-unsaved-export-qLmJHM_PCB

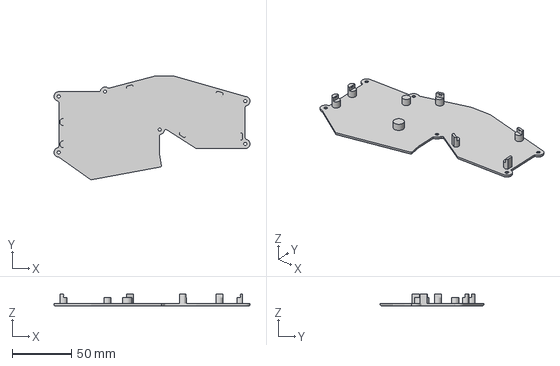
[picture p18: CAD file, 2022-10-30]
proto2/case-right-base.3mf
165.0 x 87.2 x 10.0 mm

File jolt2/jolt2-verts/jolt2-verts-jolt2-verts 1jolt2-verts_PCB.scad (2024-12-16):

// CSG file generated from FreeCAD 1.0.0
group() {
 group(){
polyhedron ( points = [[122.000000,-112.000000,0.000000],[122.000000,-112.000000,1.600000],[106.000000,-112.000000,1.600000],[106.000000,-112.000000,0.000000],[122.000000,-52.000000,0.000000],[122.000000,-52.000000,1.600000],[106.000000,-52.000000,1.600000],[106.000000,-52.000000,0.000000],[108.000000,-110.500000,0.000000],[113.000000,-106.350899,0.000000],[113.000000,-101.714500,0.000000],[108.800003,-95.275299,0.000000],[113.000000,-95.350899,0.000000],[113.000000,-88.350899,0.000000],[116.750000,-106.500000,0.000000],[120.000000,-110.500000,0.000000],[118.949997,-101.500000,0.000000],[116.750000,-88.500000,0.000000],[108.800003,-77.275299,0.000000],[113.000000,-83.714500,0.000000],[113.000000,-77.350899,0.000000],[113.000000,-70.350899,0.000000],[108.800003,-59.275299,0.000000],[108.000000,-54.500000,0.000000],[113.000000,-65.714500,0.000000],[113.000000,-59.350899,0.000000],[116.750000,-70.500000,0.000000],[118.949997,-83.500000,0.000000],[118.949997,-65.500000,0.000000],[120.000000,-54.500000,0.000000],[108.000000,-110.500000,1.600000],[113.000000,-106.350899,1.600000],[113.000000,-101.714500,1.600000],[108.800003,-95.275299,1.600000],[113.000000,-95.350899,1.600000],[113.000000,-88.350899,1.600000],[116.750000,-106.500000,1.600000],[120.000000,-110.500000,1.600000],[118.949997,-101.500000,1.600000],[116.750000,-88.500000,1.600000],[108.800003,-77.275299,1.600000],[113.000000,-83.714500,1.600000],[113.000000,-77.350899,1.600000],[113.000000,-70.350899,1.600000],[108.800003,-59.275299,1.600000],[108.000000,-54.500000,1.600000],[113.000000,-65.714500,1.600000],[113.000000,-59.350899,1.600000],[116.750000,-70.500000,1.600000],[118.949997,-83.500000,1.600000],[118.949997,-65.500000,1.600000],[120.000000,-54.500000,1.600000],[122.000000,-112.000000,0.800000],[118.800003,-112.000000,1.600000],[115.599998,-112.000000,1.600000],[112.400002,-112.000000,1.600000],[109.199997,-112.000000,1.600000],[106.000000,-112.000000,0.800000],[118.800003,-112.000000,0.000000],[115.599998,-112.000000,0.000000],[112.400002,-112.000000,0.000000],[109.199997,-112.000000,0.000000],[122.000000,-52.000000,0.800000],[122.000000,-56.615383,1.600000],[122.000000,-61.230770,1.600000],[122.000000,-65.846153,1.600000],[122.000000,-70.461540,1.600000],[122.000000,-75.076920,1.600000],[122.000000,-79.692307,1.600000],[122.000000,-84.307693,1.600000],[122.000000,-88.923080,1.600000],[122.000000,-93.538460,1.600000],[122.000000,-98.153847,1.600000],[122.000000,-102.769234,1.600000],[122.000000,-107.384613,1.600000],[122.000000,-56.615383,0.000000],[122.000000,-61.230770,0.000000],[122.000000,-65.846153,0.000000],[122.000000,-70.461540,0.000000],[122.000000,-75.076920,0.000000],[122.000000,-79.692307,0.000000],[122.000000,-84.307693,0.000000],[122.000000,-88.923080,0.000000],[122.000000,-93.538460,0.000000],[122.000000,-98.153847,0.000000],[122.000000,-102.769234,0.000000],[122.000000,-107.384613,0.000000],[106.000000,-107.384613,1.600000],[106.000000,-102.769234,1.600000],[106.000000,-98.153847,1.600000],[106.000000,-93.538460,1.600000],[106.000000,-88.923080,1.600000],[106.000000,-84.307693,1.600000],[106.000000,-79.692307,1.600000],[106.000000,-75.076920,1.600000],[106.000000,-70.461540,1.600000],[106.000000,-65.846153,1.600000],[106.000000,-61.230770,1.600000],[106.000000,-56.615383,1.600000],[106.000000,-52.000000,0.800000],[106.000000,-107.384613,0.000000],[106.000000,-102.769234,0.000000],[106.000000,-98.153847,0.000000],[106.000000,-93.538460,0.000000],[106.000000,-88.923080,0.000000],[106.000000,-84.307693,0.000000],[106.000000,-79.692307,0.000000],[106.000000,-75.076920,0.000000],[106.000000,-70.461540,0.000000],[106.000000,-65.846153,0.000000],[106.000000,-61.230770,0.000000],[106.000000,-56.615383,0.000000],[109.199997,-52.000000,0.000000],[112.400002,-52.000000,0.000000],[115.599998,-52.000000,0.000000],[118.800003,-52.000000,0.000000],[108.000000,-109.500000,0.000000],[112.263100,-105.074547,0.000000],[113.736900,-105.074547,0.000000],[111.285500,-100.000000,0.000000],[113.000000,-98.285500,0.000000],[114.714500,-100.000000,0.000000],[108.800003,-94.284698,0.000000],[112.263100,-94.074547,0.000000],[113.736900,-94.074547,0.000000],[112.263100,-87.074547,0.000000],[113.736900,-87.074547,0.000000],[115.250000,-105.000000,0.000000],[116.750000,-103.500000,0.000000],[118.250000,-105.000000,0.000000],[120.000000,-109.500000,0.000000],[117.449997,-100.000000,0.000000],[118.949997,-98.500000,0.000000],[120.449997,-100.000000,0.000000],[115.250000,-87.000000,0.000000],[116.750000,-85.500000,0.000000],[118.250000,-87.000000,0.000000],[108.800003,-76.284698,0.000000],[111.285500,-82.000000,0.000000],[113.000000,-80.285500,0.000000],[114.714500,-82.000000,0.000000],[112.263100,-76.074547,0.000000],[113.736900,-76.074547,0.000000],[112.263100,-69.074547,0.000000],[113.736900,-69.074547,0.000000],[108.800003,-58.284698,0.000000],[108.000000,-53.500000,0.000000],[111.285500,-64.000000,0.000000],[113.000000,-62.285500,0.000000],[114.714500,-64.000000,0.000000],[112.263100,-58.074551,0.000000],[113.736900,-58.074551,0.000000],[115.250000,-69.000000,0.000000],[116.750000,-67.500000,0.000000],[118.250000,-69.000000,0.000000],[117.449997,-82.000000,0.000000],[118.949997,-80.500000,0.000000],[120.449997,-82.000000,0.000000],[117.449997,-64.000000,0.000000],[118.949997,-62.500000,0.000000],[120.449997,-64.000000,0.000000],[120.000000,-53.500000,0.000000],[109.199997,-52.000000,1.600000],[112.400002,-52.000000,1.600000],[115.599998,-52.000000,1.600000],[118.800003,-52.000000,1.600000],[108.000000,-109.500000,1.600000],[112.263100,-105.074547,1.600000],[113.736900,-105.074547,1.600000],[111.285500,-100.000000,1.600000],[113.000000,-98.285500,1.600000],[114.714500,-100.000000,1.600000],[108.800003,-94.284698,1.600000],[112.263100,-94.074547,1.600000],[113.736900,-94.074547,1.600000],[112.263100,-87.074547,1.600000],[113.736900,-87.074547,1.600000],[115.250000,-105.000000,1.600000],[116.750000,-103.500000,1.600000],[118.250000,-105.000000,1.600000],[120.000000,-109.500000,1.600000],[117.449997,-100.000000,1.600000],[118.949997,-98.500000,1.600000],[120.449997,-100.000000,1.600000],[115.250000,-87.000000,1.600000],[116.750000,-85.500000,1.600000],[118.250000,-87.000000,1.600000],[108.800003,-76.284698,1.600000],[111.285500,-82.000000,1.600000],[113.000000,-80.285500,1.600000],[114.714500,-82.000000,1.600000],[112.263100,-76.074547,1.600000],[113.736900,-76.074547,1.600000],[112.263100,-69.074547,1.600000],[113.736900,-69.074547,1.600000],[108.800003,-58.284698,1.600000],[108.000000,-53.500000,1.600000],[111.285500,-64.000000,1.600000],[113.000000,-62.285500,1.600000],[114.714500,-64.000000,1.600000],[112.263100,-58.074551,1.600000],[113.736900,-58.074551,1.600000],[115.250000,-69.000000,1.600000],[116.750000,-67.500000,1.600000],[118.250000,-69.000000,1.600000],[117.449997,-82.000000,1.600000],[118.949997,-80.500000,1.600000],[120.449997,-82.000000,1.600000],[117.449997,-64.000000,1.600000],[118.949997,-62.500000,1.600000],[120.449997,-64.000000,1.600000],[120.000000,-53.500000,1.600000],[108.000000,-110.500000,0.800000],[113.000000,-106.350899,0.800000],[113.000000,-101.714500,0.800000],[108.800003,-95.275299,0.800000],[113.000000,-95.350899,0.800000],[113.000000,-88.350899,0.800000],[116.750000,-106.500000,0.800000],[120.000000,-110.500000,0.800000],[118.949997,-101.500000,0.800000],[116.750000,-88.500000,0.800000],[108.800003,-77.275299,0.800000],[113.000000,-83.714500,0.800000],[113.000000,-77.350899,0.800000],[113.000000,-70.350899,0.800000],[108.800003,-59.275299,0.800000],[108.000000,-54.500000,0.800000],[113.000000,-65.714500,0.800000],[113.000000,-59.350899,0.800000],[116.750000,-70.500000,0.800000],[118.949997,-83.500000,0.800000],[118.949997,-65.500000,0.800000],[120.000000,-54.500000,0.800000],[109.166374,-112.000000,1.323590],[112.388794,-112.000000,1.323590],[115.611206,-112.000000,1.323590],[118.833626,-112.000000,1.323590],[114.000000,-74.034088,0.000000],[114.000000,-53.633598,0.000000],[108.110886,-104.634819,0.000000],[119.889114,-104.634819,0.000000],[114.000000,-94.434578,0.000000],[111.055443,-109.734947,0.000000],[116.944557,-109.734947,0.000000],[114.000000,-104.634819,0.000000],[119.889114,-84.234337,0.000000],[108.110886,-84.234337,0.000000],[111.055443,-89.334457,0.000000],[108.110886,-94.434578,0.000000],[116.944557,-99.534698,0.000000],[111.055443,-99.534698,0.000000],[119.889114,-94.434578,0.000000],[116.944557,-89.334457,0.000000],[114.000000,-84.234337,0.000000],[111.055443,-79.134209,0.000000],[108.110886,-74.034088,0.000000],[116.944557,-79.134209,0.000000],[108.110886,-63.833843,0.000000],[111.055443,-68.933968,0.000000],[116.944557,-58.733723,0.000000],[111.055443,-58.733723,0.000000],[119.889114,-53.633598,0.000000],[108.110886,-53.633598,0.000000],[119.889114,-74.034088,0.000000],[116.944557,-53.633598,0.000000],[111.055443,-53.633598,0.000000],[121.361389,-61.283783,0.000000],[
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

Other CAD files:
jolt2/empty-outline/board-case.FCStd
jolt3/jolt3-right/jolt3-right.step
mesa3/mesa3-right/mesa3-right.step
BasePlate-jolt1.3mf
BasePlate.3mf
Top-jolt1.3mf
jolt2/empty-outline/empty-outline.step
jolt2/jolt2-pm2350-left/jolt2-pm2350-left.step
jolt2/jolt2-pm2350-left/stand1-Cut - Final (Meshed).3mf
jolt2/jolt2-pm2350-left/stand1-Cut - Final.obj
jolt2/jolt2-pm2350-left/stand1-Cut - Final.step
jolt2/jolt2-tiny2040-left/board-case-Base-obj.3mf
jolt2/jolt2-tiny2040-left/board-case.FCStd
jolt2/jolt2-tiny2040-left/jolt2-tiny2040-left.step
jolt2/jolt2-verts/PG1350-socket.STEP
jolt2/jolt2-verts/base-left.FCStd
jolt2/jolt2-verts/jolt2-verts-jolt2-verts 1jolt2-verts_PCB.3mf
jolt2/jolt2-verts/jolt2-verts-jolt2-verts 1jolt2-verts_PCB.scad.FCStd
jolt2/jolt2-verts/jolt2-verts.FCStd
jolt2/jolt2-verts/jolt2-verts.step
jolt2/jolt2-verts/just-fucking-print-it.3mf
jolt2/jolt2-verts/kailhlowprofilev102.skp
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

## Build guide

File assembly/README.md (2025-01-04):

# Assembly of keyboards

These instructions describe how to assembly the "Jolt2".  In the images are the "dir" variant which
has the rp2040 directly mounted on the board.  The assembly describe here is the same for the key
parts, no matter which variant is chosen.

## Key base

Before assembling all of the vertical risers, it is probably best to assemble the base, and make
sure it works.

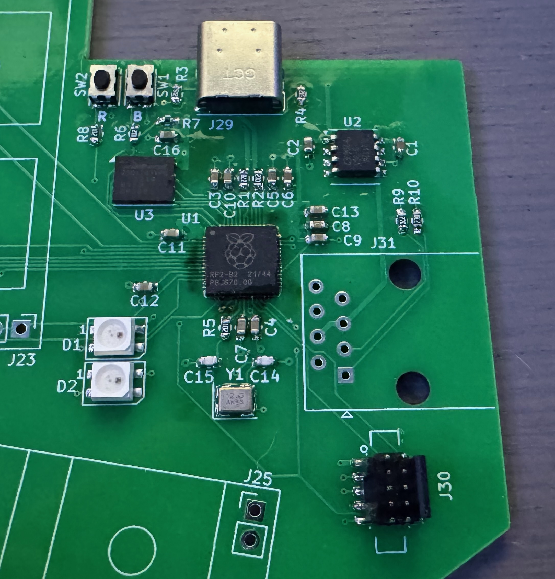
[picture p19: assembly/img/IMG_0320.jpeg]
Mostly assembled jolt2dir-left


As you can see here, I've done most of the assembly, and testing revealed that not all of the pins
on the rp2040 have contact. I spent some time getting this to work (meanwhile gradually getting
better at SMD assembly).

Once I got the rp2040 mounted (with a good layer of residual no-clean flux), and figured out that
the SK6812-MINI and the SK6812-MINI-HS have very different footprints, I got the main part working.
I used a wire across the key mounts (J1-J28) by connecting the lowest numbered pin with one of the
others to simulate that key being pressed, and confirmed that the circuitry was working.

The base PCB ends up looking like this:

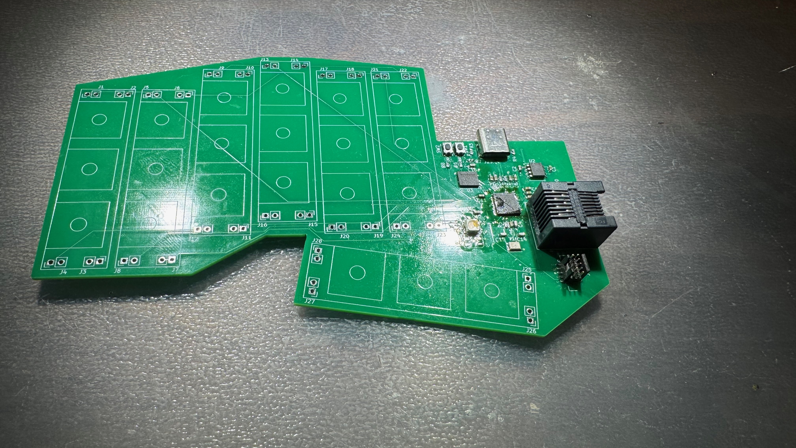
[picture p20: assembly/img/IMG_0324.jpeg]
PCB base for left side of keyboard


## Risers

For each keyboard half, 7 risers are needed (the "verts").  Each has 3 diodes, and 3 sockets for
Kailh Choc v1 switches. I have had much better results soldering the sockets while having a switch
mounted as I found that sometimes adding the switch later, the misalignment was sufficient enough to
permanently damage the socket.

The end result looks like this:

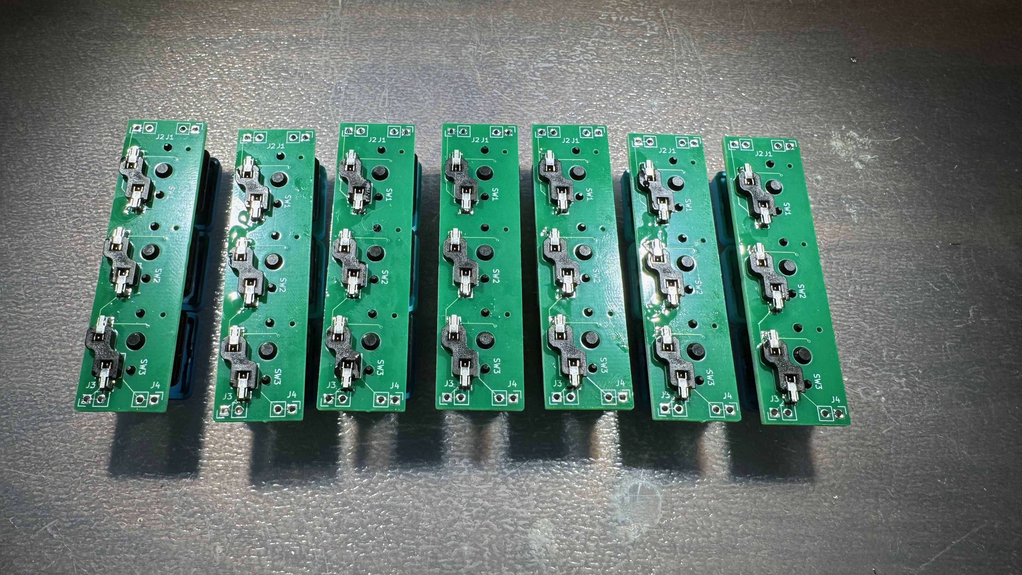
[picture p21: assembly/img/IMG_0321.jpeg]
Risers, back side


With the tops looking like:

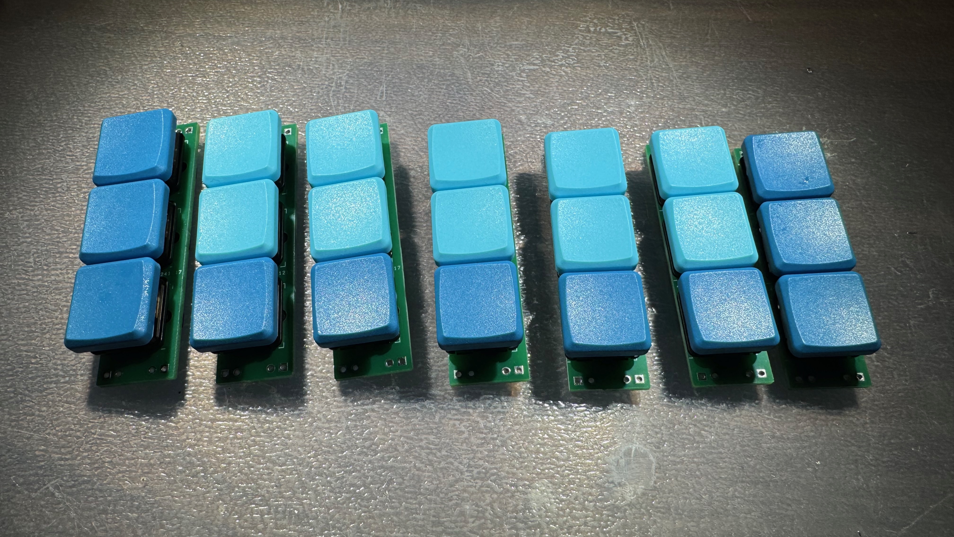
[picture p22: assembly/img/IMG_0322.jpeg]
Riser tops


## Mounting the risers

The risers for the left side should be installed starting from the keys closest to the circuitry
(index finger keys) and working your way left. That is because the spacer jig used to add them only
comes out in one direction, due to the position of the switches.

For the right side, you can assembl starting from the pinky keys. It can be a little tricky to get
the jig out of the keys nearest the CPU (the pushbuttons notably get in the way.  What I did is just
solder the pins furthest from the circuitry, and was able to lift the PCB up enough to get the
spacer out. I then used the spacer along the edge to solder the last pieces.)

You can use pin headers of an appropriate length, or just get a pack of long ones.  Ideal lengths
for the 4 heights used here are 8mm, 10mm, 12mm, and 16mm.  In my case, I had 12 and 19mm header
pins, and used an appropriate one, cutting for the rest.

The two part (TODO: STL) header jig holds the header pins in position to solder.  Place the
appropriate pins, long end first, into the jig, and use the second part to push them flush. For most
headers, this moves the plastic part slightly.

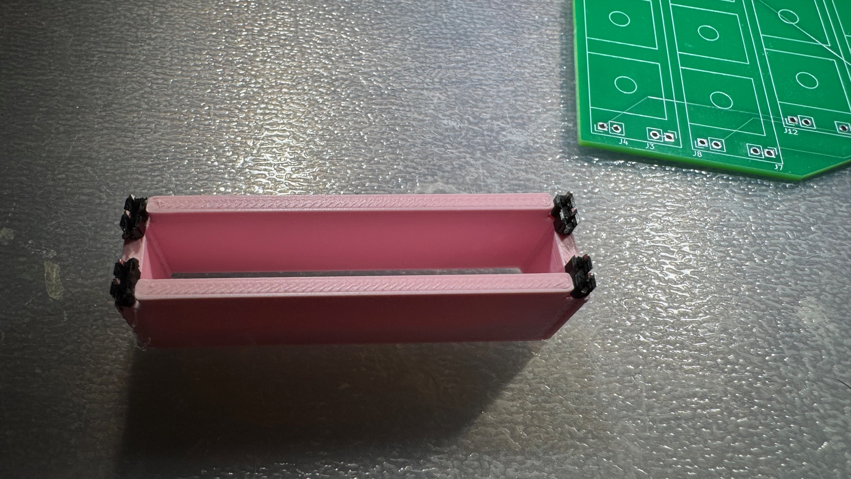
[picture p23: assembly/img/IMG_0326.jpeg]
Pins in jig


The jig and pins are then placed, and the pins solder. I generall solder one pin and check that the
plastic part is flush, if not, heat that one pin while pushing on the jig.  After everything is
solder, the jig is then removed, and the pins should be solidly positioned.

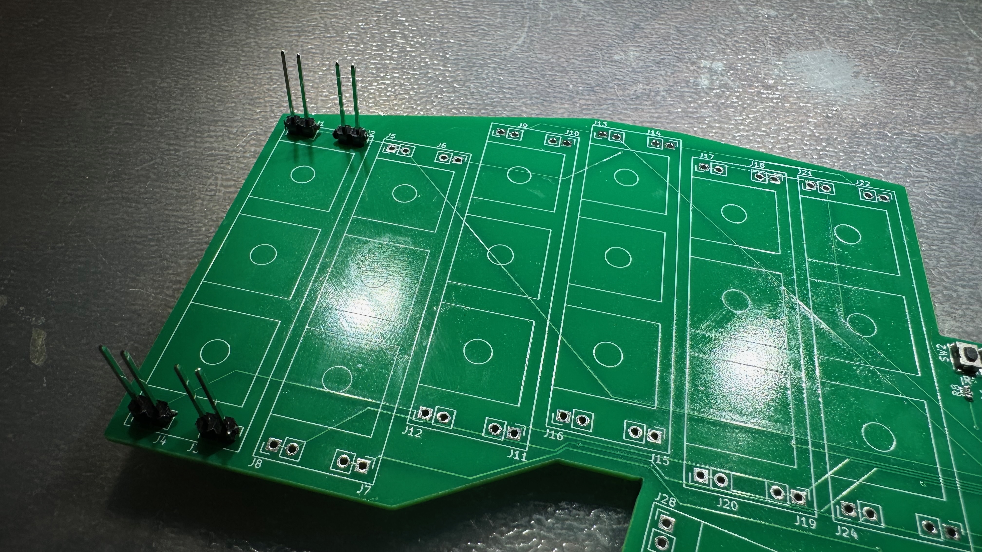
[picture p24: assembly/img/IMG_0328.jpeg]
Pins in place


**Note**: I started at the wrong end here, but caught myself before moving to the next step.

Once the pins are in place, add the appropriate spacer, as shown.  The two pinky columns and the two
index columns should use the "thick" space (10mm). The middle finger the thin spacer (4mm), and the
ring finger the medium spacer (6mm).  There is likely variation in hand shape here, although
experiementing is a bit tedious.

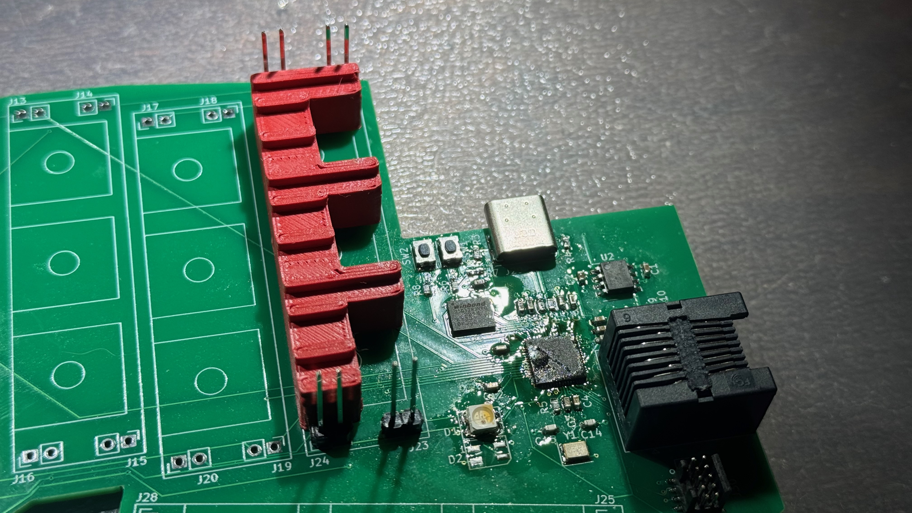
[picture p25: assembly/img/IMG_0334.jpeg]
Spacer in position


If you need to cut the pins, it is easiest at this point to add an unassembled riser board, holding
it firmly while using cutters to shorten the pins.

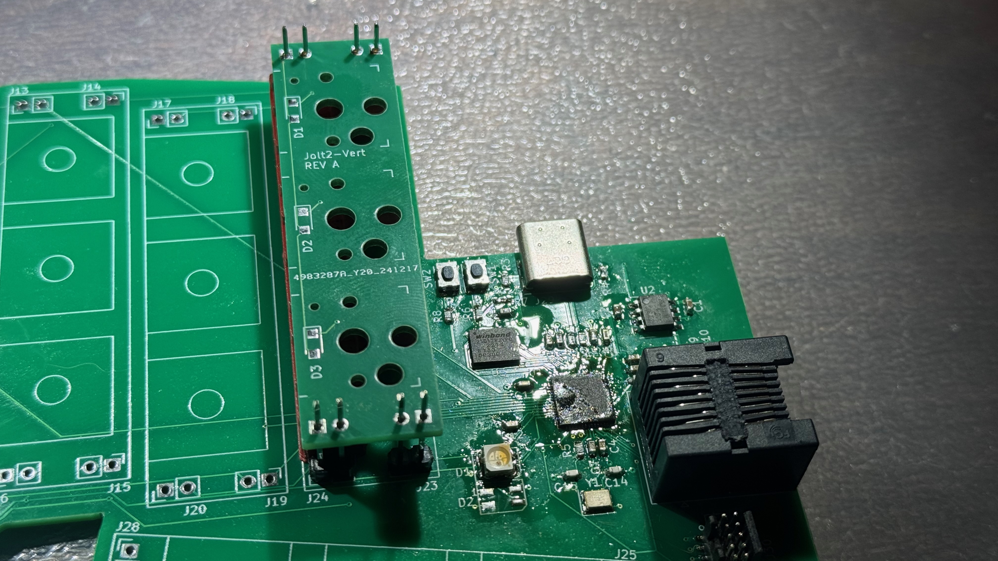
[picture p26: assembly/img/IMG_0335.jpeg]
Unpopulated Riser

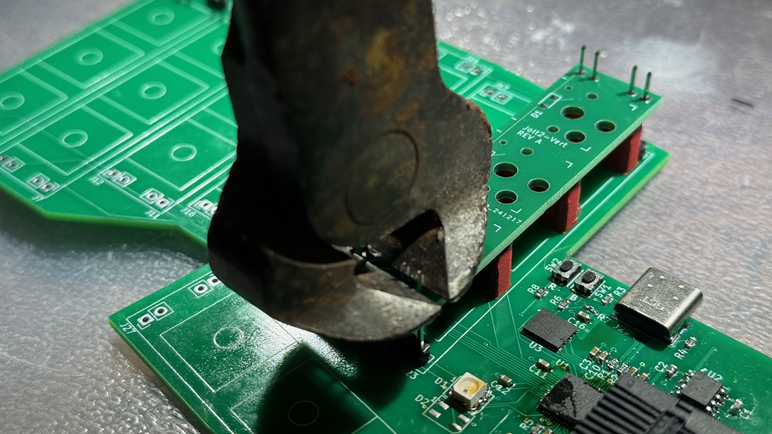
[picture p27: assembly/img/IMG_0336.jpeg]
Cutting the excess pin


After possibly cutting the pins, place the appropriate riser board (see below) and solder it down.
Again, make sure that it sits flush against the spacer for each pin you solder.

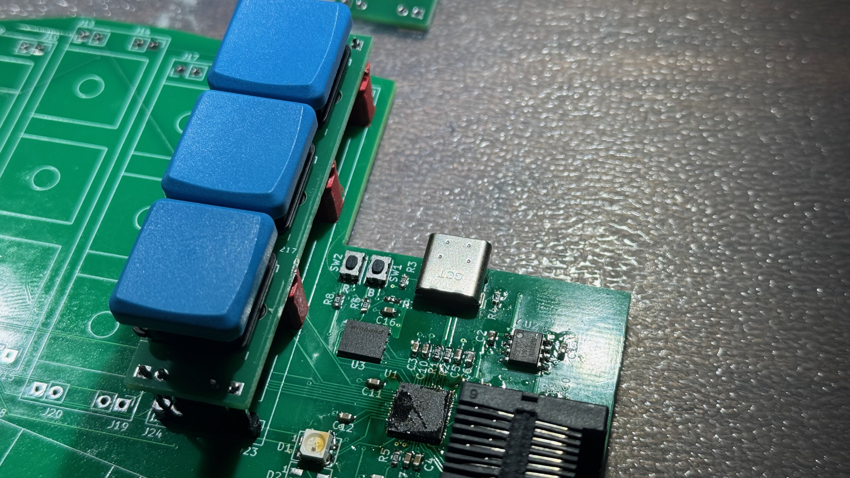
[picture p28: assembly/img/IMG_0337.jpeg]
Riser board in place

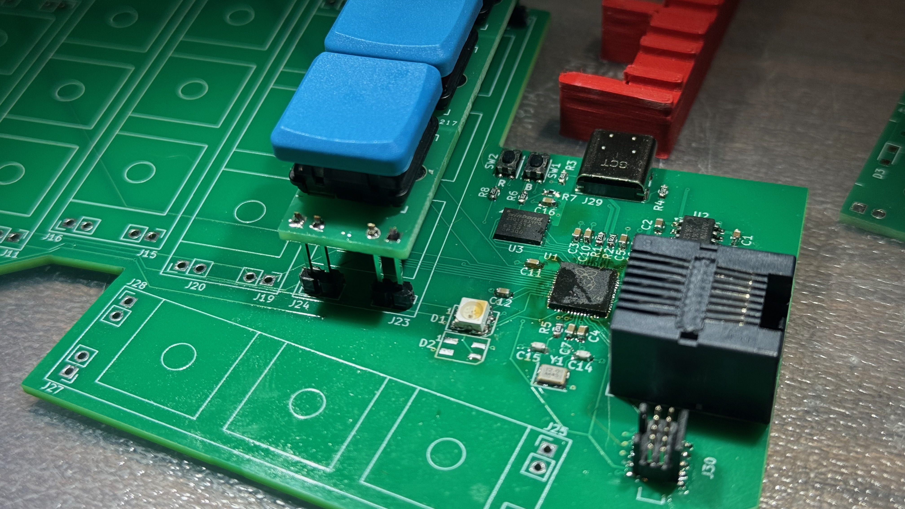
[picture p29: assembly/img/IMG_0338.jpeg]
Riser with spacer removed


When you are finished with all of the finger risers, it should look something like this:

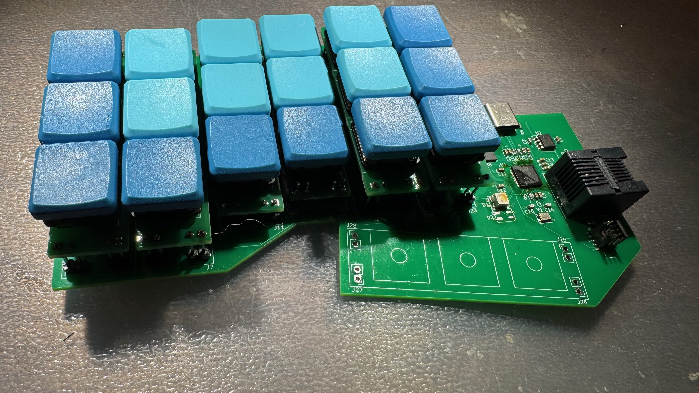
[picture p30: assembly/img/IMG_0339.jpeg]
Finger keys all installed

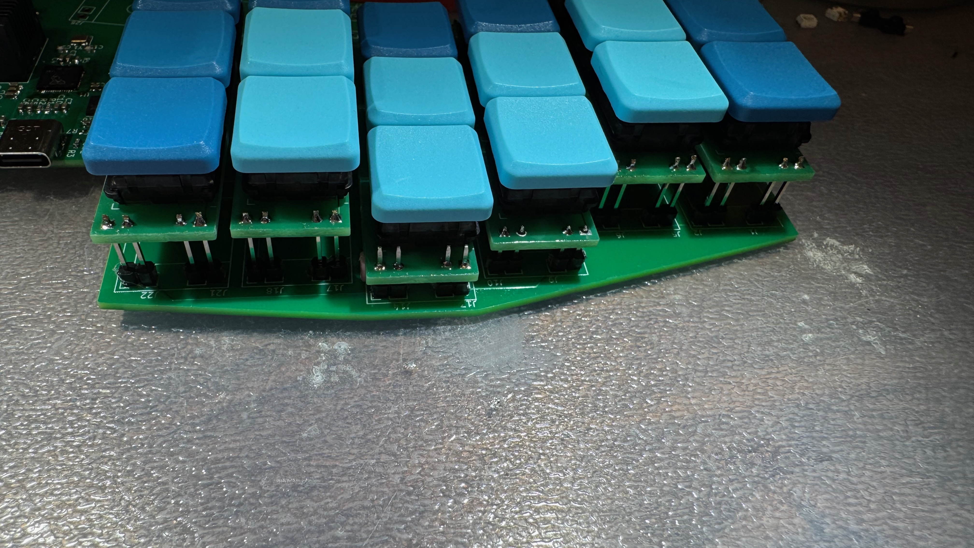
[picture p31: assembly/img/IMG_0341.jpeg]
Finger keys, back view


Lastly, install the thumb keys.  I install them only using the header plastic part for spacing.  The
end result looks like this:

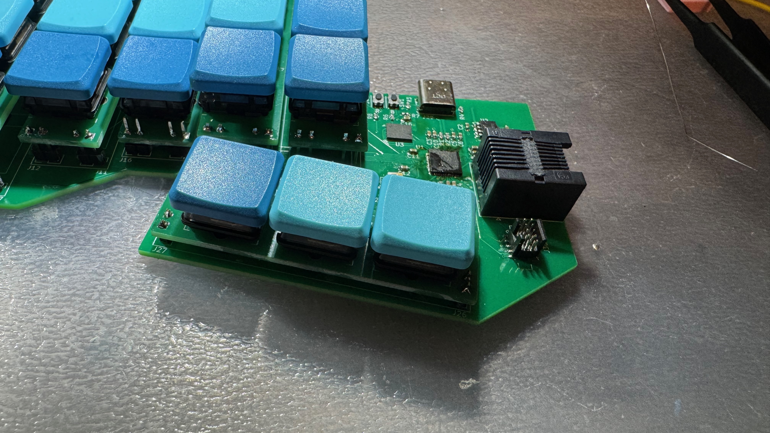
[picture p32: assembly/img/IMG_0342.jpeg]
With thumb keys


## Assembling the case

As of 2025-01-04, I am still working on the case design.  Instructions to follow here.

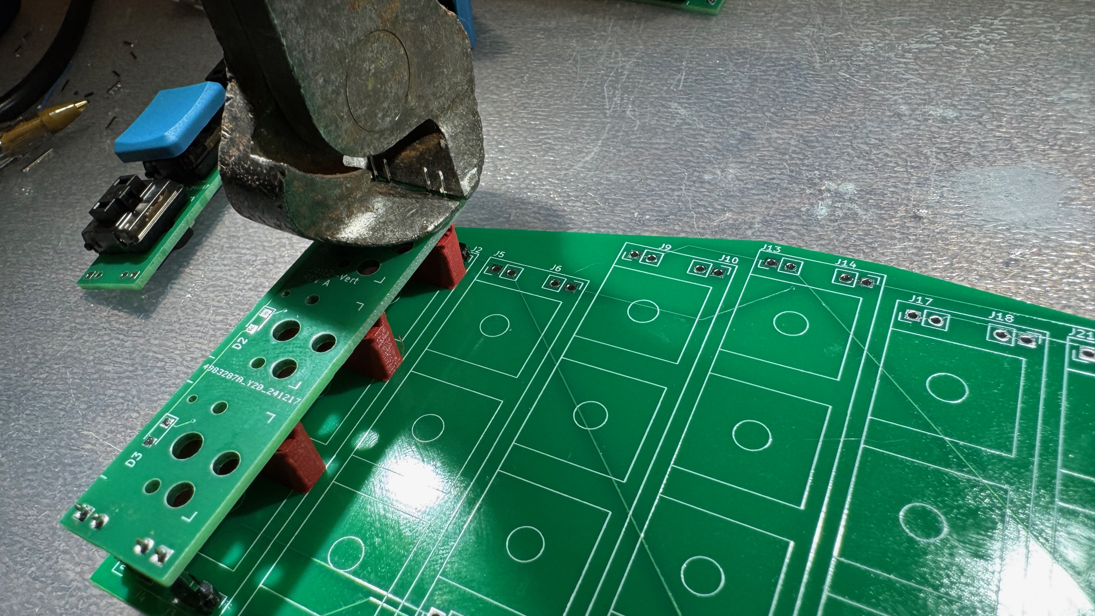
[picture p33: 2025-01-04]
assembly/img/IMG_0332.jpeg

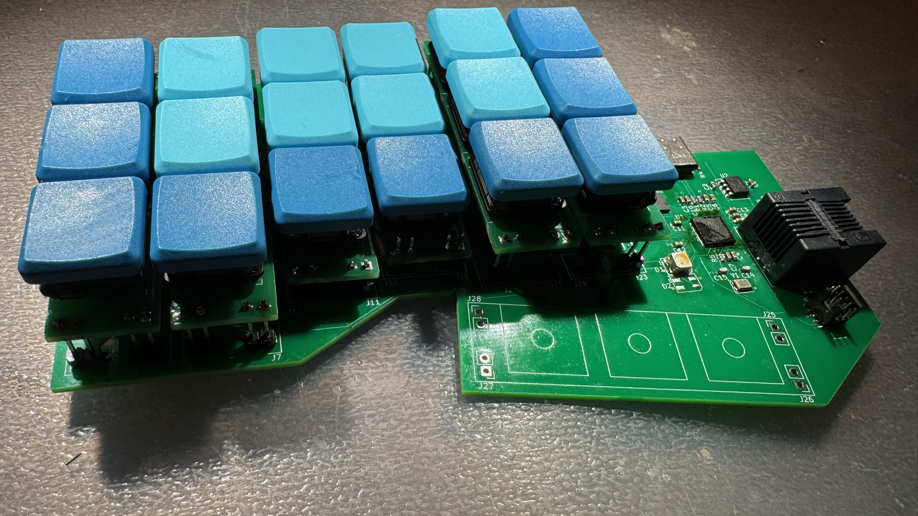
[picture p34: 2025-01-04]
assembly/img/IMG_0340.jpeg

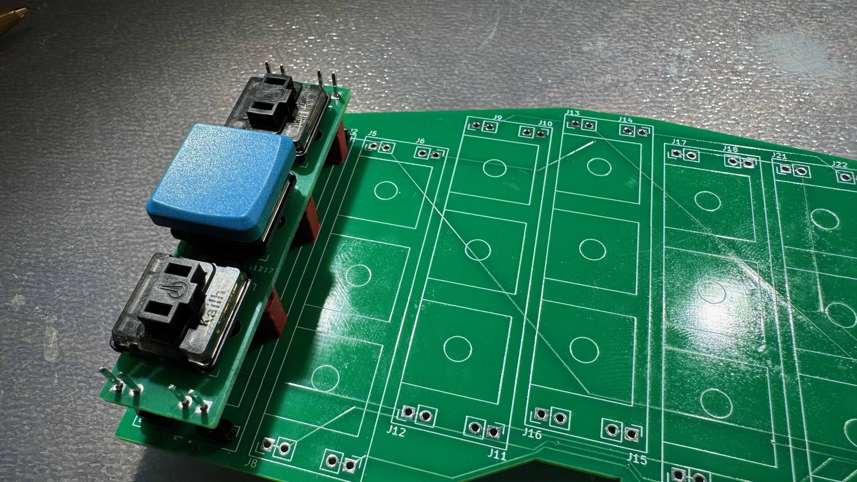
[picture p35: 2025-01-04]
assembly/img/IMG_0330.jpeg

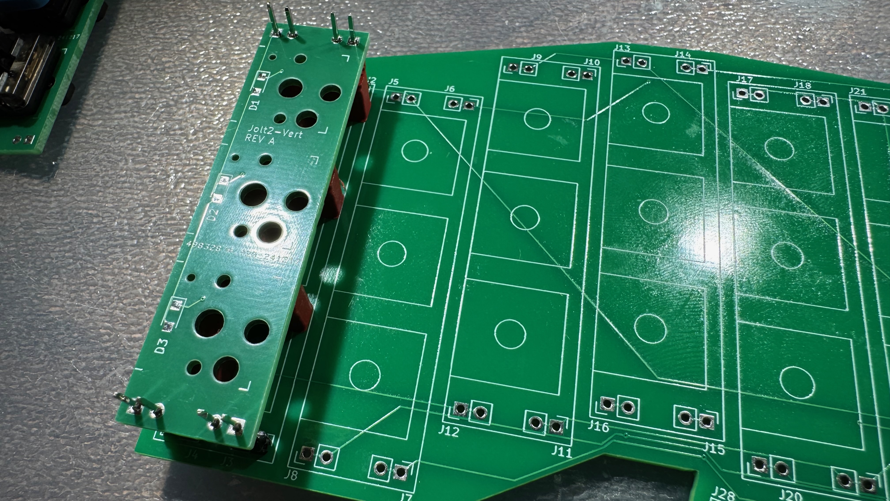
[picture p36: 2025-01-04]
assembly/img/IMG_0331.jpeg

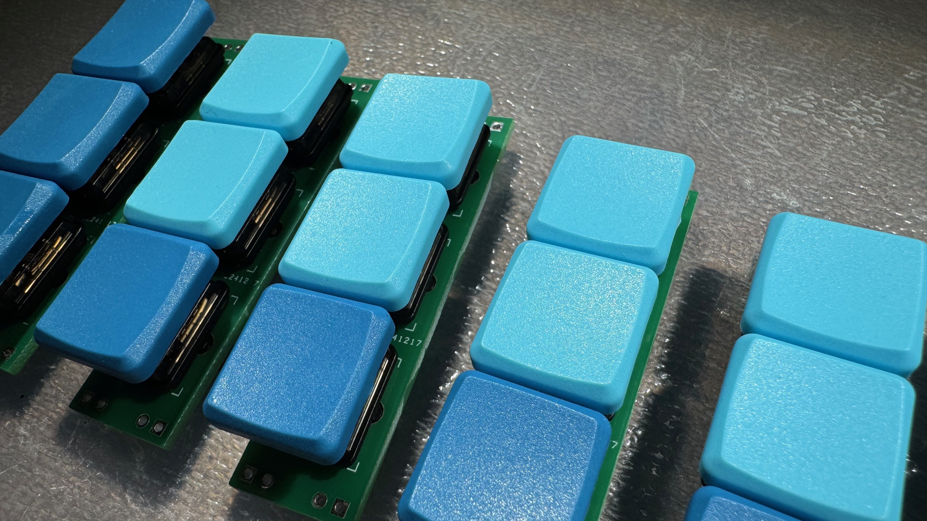
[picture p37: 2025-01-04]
assembly/img/IMG_0323.jpeg

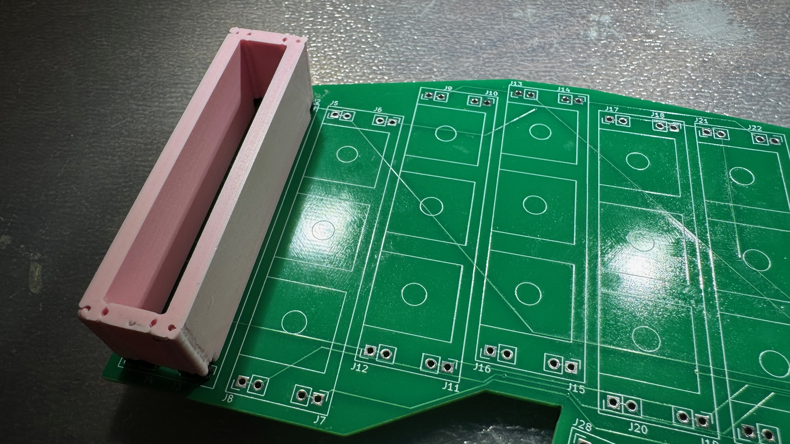
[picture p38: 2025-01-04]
assembly/img/IMG_0327.jpeg

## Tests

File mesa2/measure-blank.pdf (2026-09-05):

## mesa2 - hand measurement sheet (LEFT hand; mirror for right)

100.0 mm - print at 100%, no scaling

1. Tape this down. Sit as you type. The datum line at the bottom goes parallel to the desk edge.
2. Ink the pad of each fingertip (washable marker). Do NOT hold a pen - it changes the whole posture.
3. Rest the hand naturally, then TAP each finger straight down. That is the home row. Label the dots.
4. Curl each finger one row further and tap again. Two dots per finger = the column's direction.
The line through a finger's two dots IS its splay angle. That is the measurement worth having.
5. Thumb: sweep it through its comfortable arc and tap 4-5 times along the way. Do not aim for a line -the thumb pivots at the base, so those dots fall on an arc, and the arc gives both angle and distance.
6. Mark where the heel of your palm rests. Repeat the whole thing twice more on fresh sheets.
0 | 20 | 40 | 60 | 80 | 100 | 120 | 140 | 160
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
origin (0,0) at the red cross - X to the right, Y toward you

DATUM - line this up with the desk edge

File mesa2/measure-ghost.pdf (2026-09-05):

## mesa2 - chouchou reference, hand-local (LEFT hand)

100.0 mm - print at 100%, no scaling

Chouchou's 10 left-hand keys, drawn 1:1 with its unibody angle removed (hand-local frame).
This is the layout you already printed - use it to mark CORRECTIONS rather than absolute positions.
1. Tape down. Ink the fingertips. Rest the hand over the ghosted keys as if typing, and tap.
2. Where each dot falls relative to its cap centre is the correction, read straight off the grid.
3. For the thumbs, tap the comfortable arc rather than aiming at the two drawn keys.
Cap centres in this sheet's grid coordinates are listed in CHOUCHOU.md. Leave the palm area below clear.

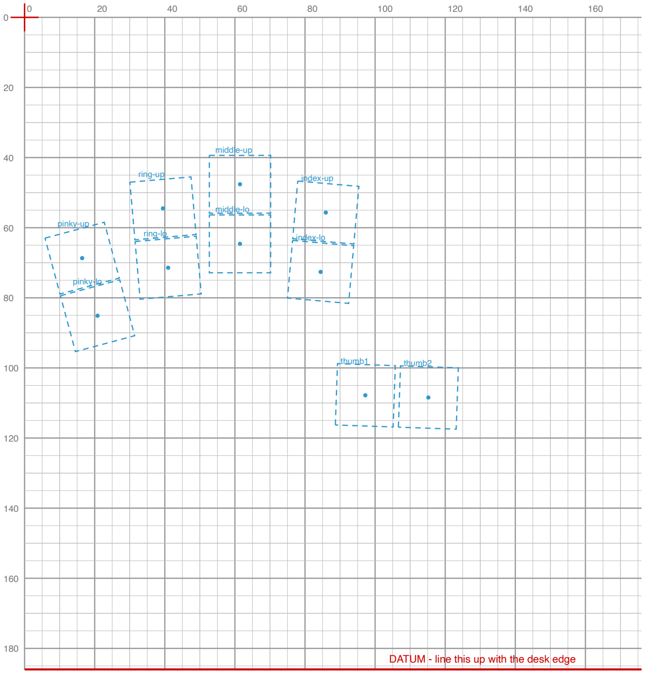
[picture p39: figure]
DATUM - line this up with the desk edge; pinky-up; pinky-lo; ring-up; ring-lo; index-lo; middle-up; middle-lo; index-up; thumb1; thumb2

origin (0,0) at the red cross - X to the right, Y toward you

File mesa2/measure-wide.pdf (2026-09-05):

## mesa2 - two-hand measurement sheet

100.0 mm - print at 100%, no scaling, LANDSCAPE

Both hands down as you would type, paper taped and NOT moved for the whole session. No desk-edge datum is needed: the angle between your two hands IS the unibody angle, so it is internal to this sheet as long as the paper never moves.
Steno rest position: each finger sits BETWEEN its two keys, not on one of them. Mark three dots per finger -
(a) where it rests, (b) rocked forward, (c) rocked back. (a) is the column centre and (b)-(c) give the column ANGLE.
Do not try to set the row pitch from (b) and (c): it is fixed at 17 mm by the caps. Only note if the rock feels SHORT.
Keep the hand PLANTED and lift one finger at a time; the others hold the posture. Mark with a pen in the other hand.
Thumbs: sweep the comfortable arc and mark 4-5 spots along it - an arc, not two aimed dots. Then mark both palm heels.
Do the left hand this way, then re-place BOTH hands naturally and do the right. Re-placing both is what keeps the angle honest.
0 | 20 | 40 | 60 | 80 | 100 | 120 | 140 | 160 | 180 | 200 | 220 | 240
0

20

40

60

80

100

120

origin (0,0) at the red cross - X runs right, Y runs toward you. Label every dot: hand, finger, and which of rest / forward / back.

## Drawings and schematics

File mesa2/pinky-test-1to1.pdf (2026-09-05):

## mesa2 - pinky splay comparison, LEFT hand, 1:1 (landscape)

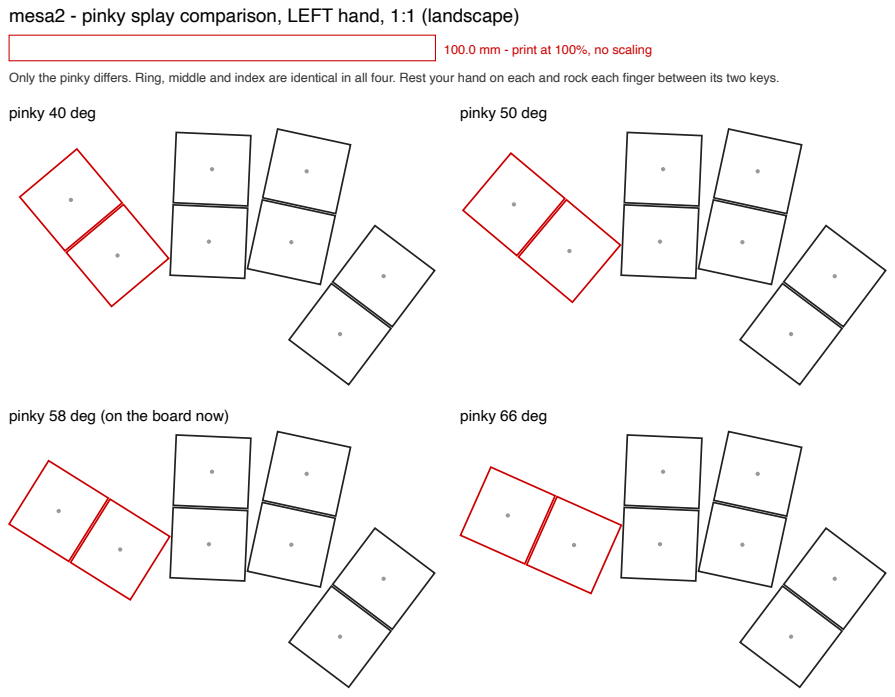
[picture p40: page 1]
pinky 40 deg; pinky 50 deg; pinky 58 deg (on the board now); pinky 66 deg

100.0 mm - print at 100%, no scaling

Only the pinky differs. Ring, middle and index are identical in all four. Rest your hand on each and rock each finger between its two keys.

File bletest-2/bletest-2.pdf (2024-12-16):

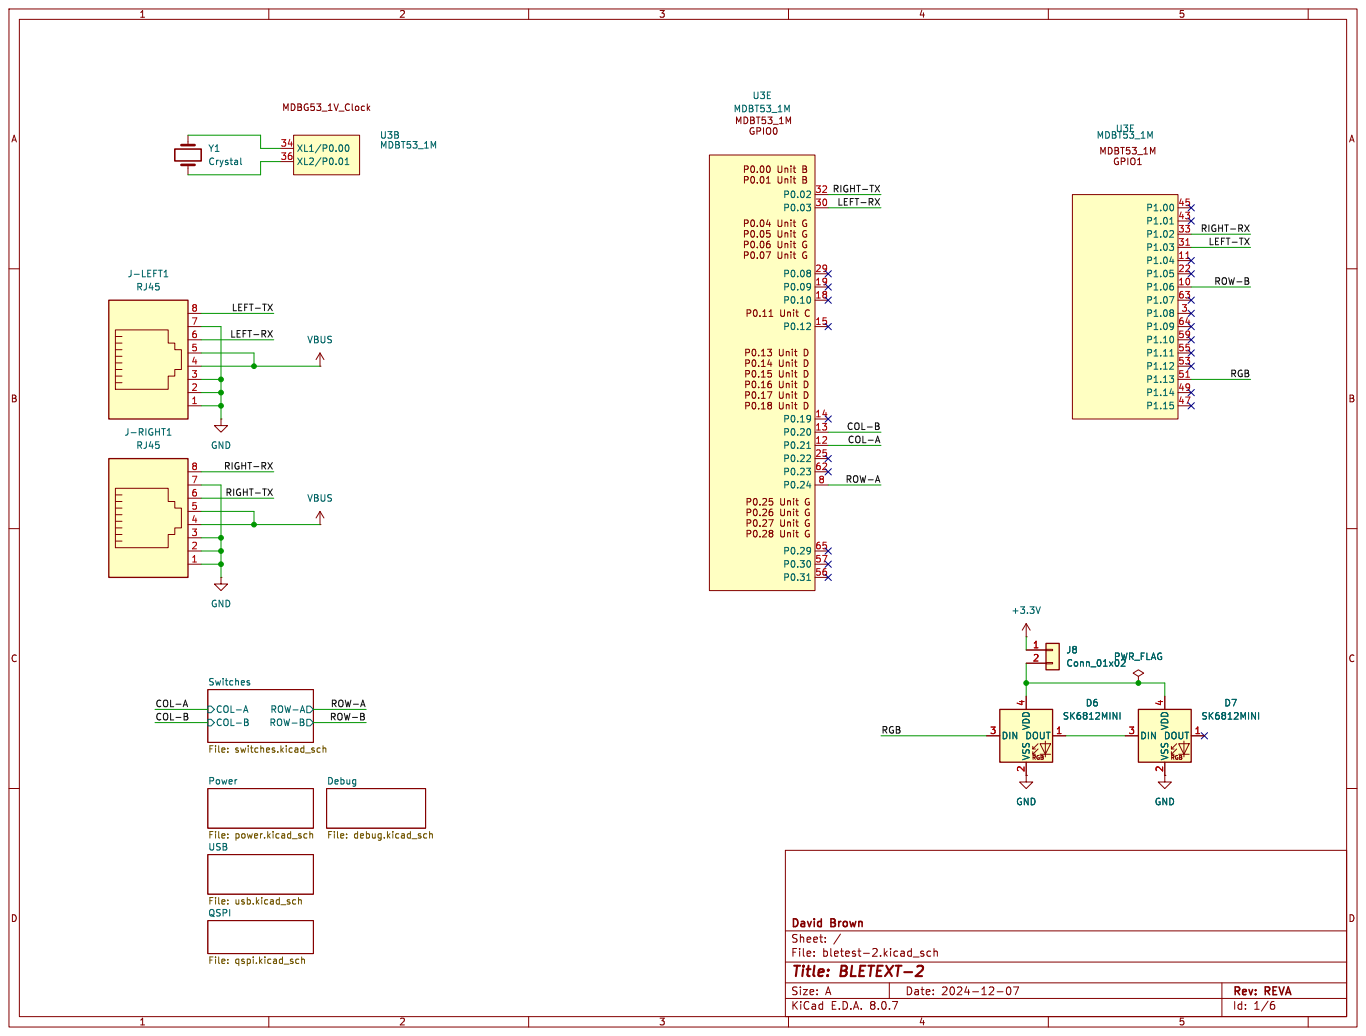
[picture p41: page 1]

LEFT-TX RIGHT-RX

File: usb.kicad_sch QSPI File: qspi.kicad_sch

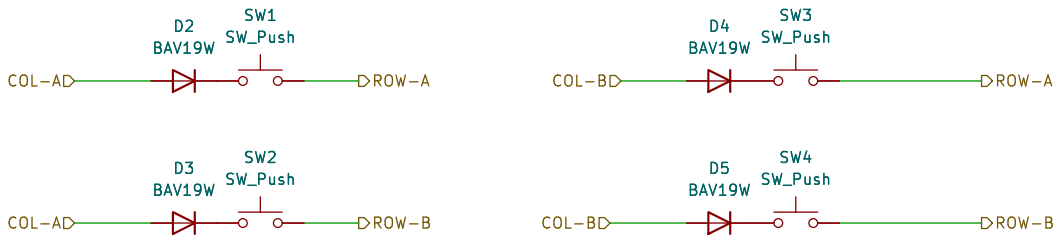
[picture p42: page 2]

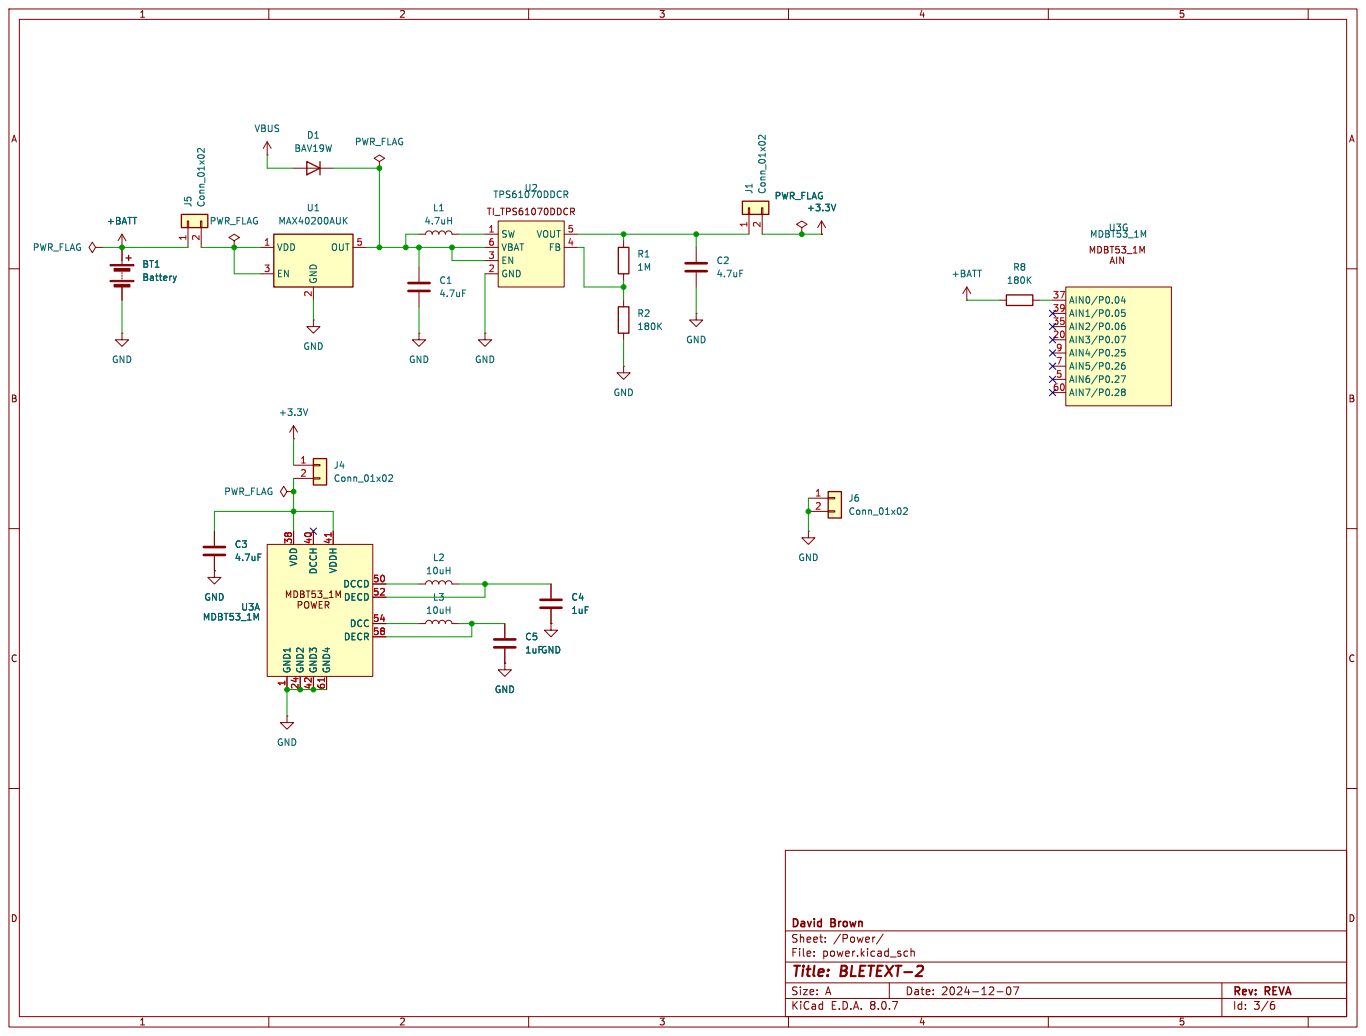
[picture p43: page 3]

1 GND2 24 VDD 38 DCCH 40 VDDH 41 GND3 42 DCCD 50 DECD 52 DCC 54 DECR 58 GND4 61 U3A MDBT53_1M
4.7uF MDBT53_1M

1 GND2 24 VDD 38 DCCH 40 VDDH 41 GND3 42 DCCD 50 DECD 52 DCC 54 DECR 58 GND4 61 C3

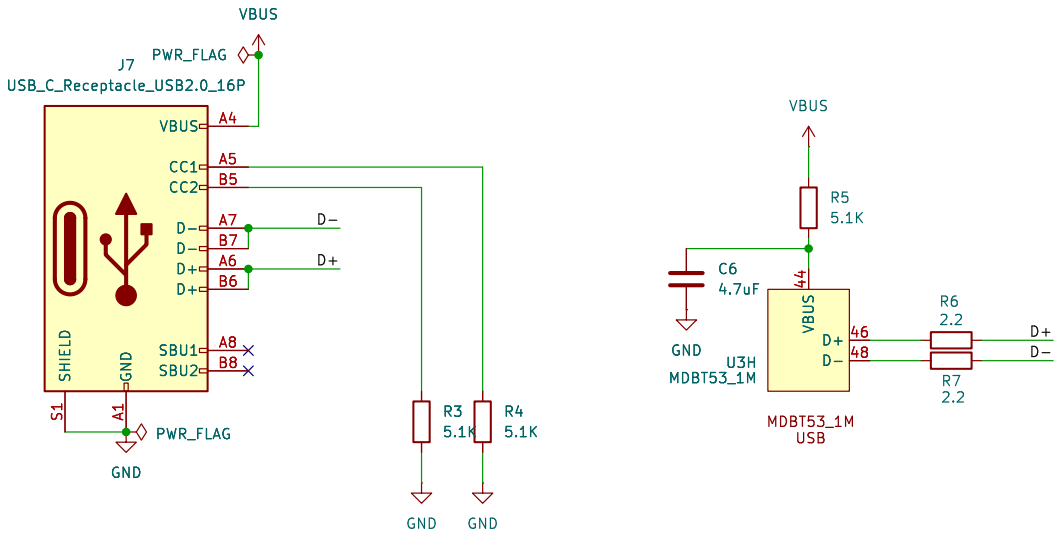
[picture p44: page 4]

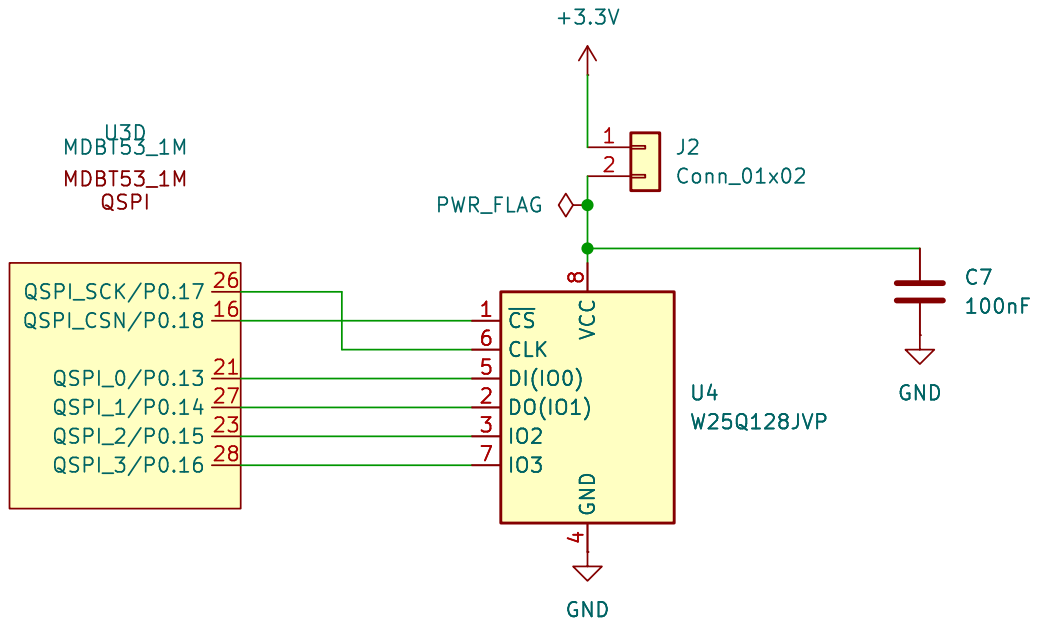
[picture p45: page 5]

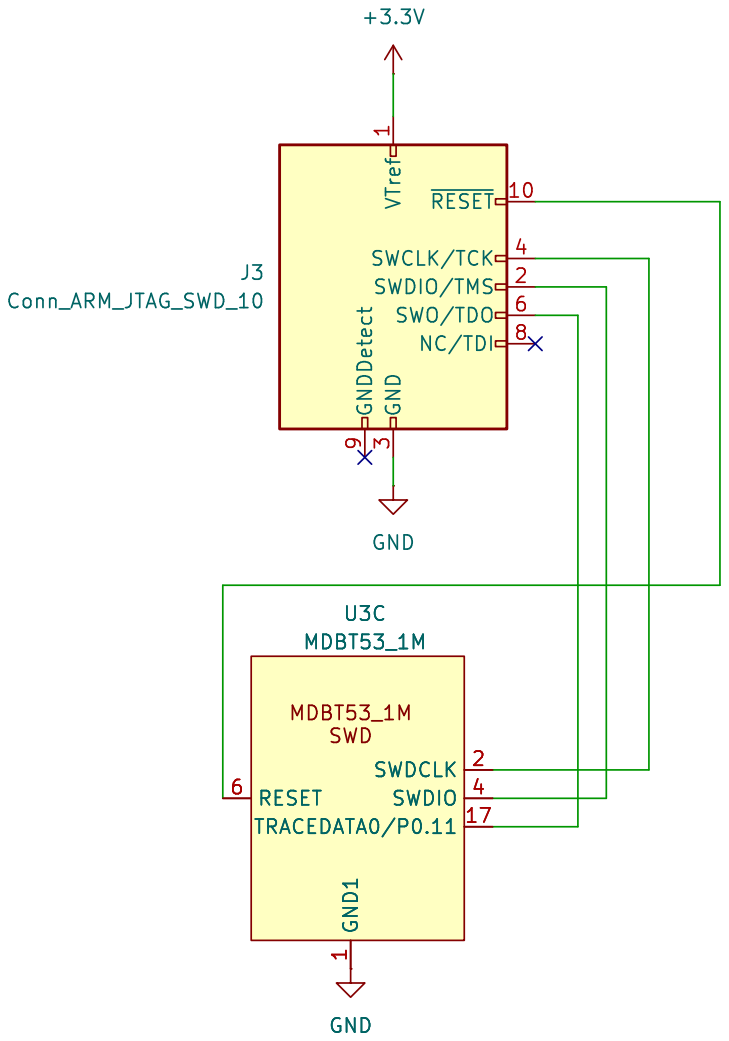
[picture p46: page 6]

3 SWCLK/TCK 4 SWO/TDO 6 NC/TDI 8 GNDDetect 9

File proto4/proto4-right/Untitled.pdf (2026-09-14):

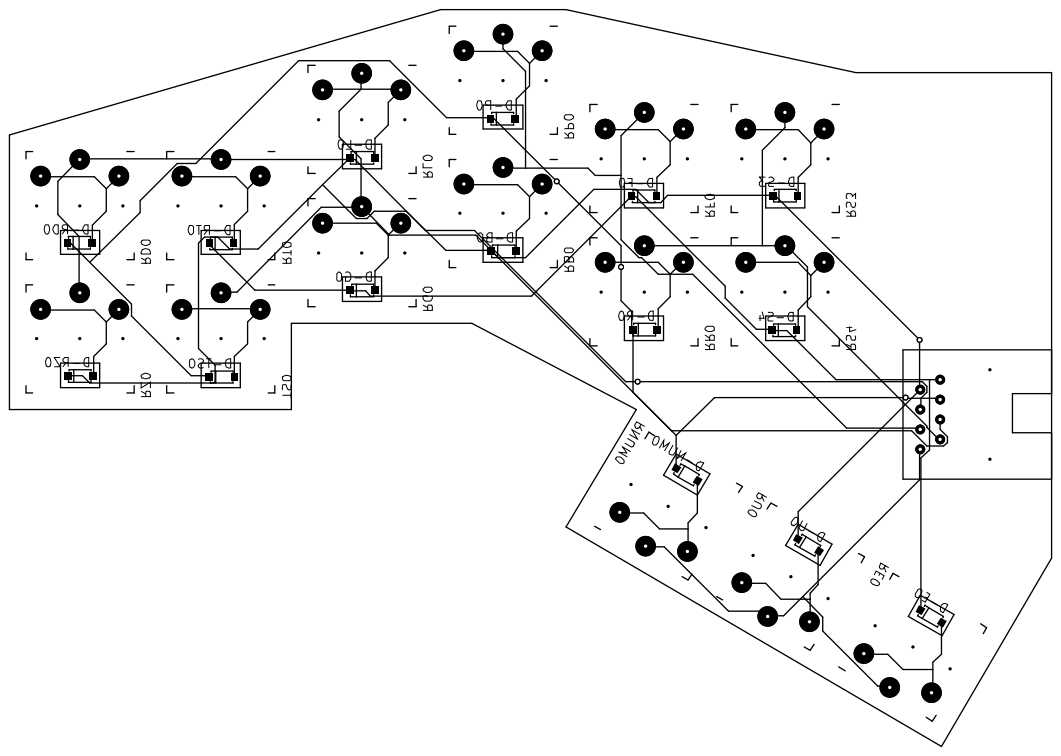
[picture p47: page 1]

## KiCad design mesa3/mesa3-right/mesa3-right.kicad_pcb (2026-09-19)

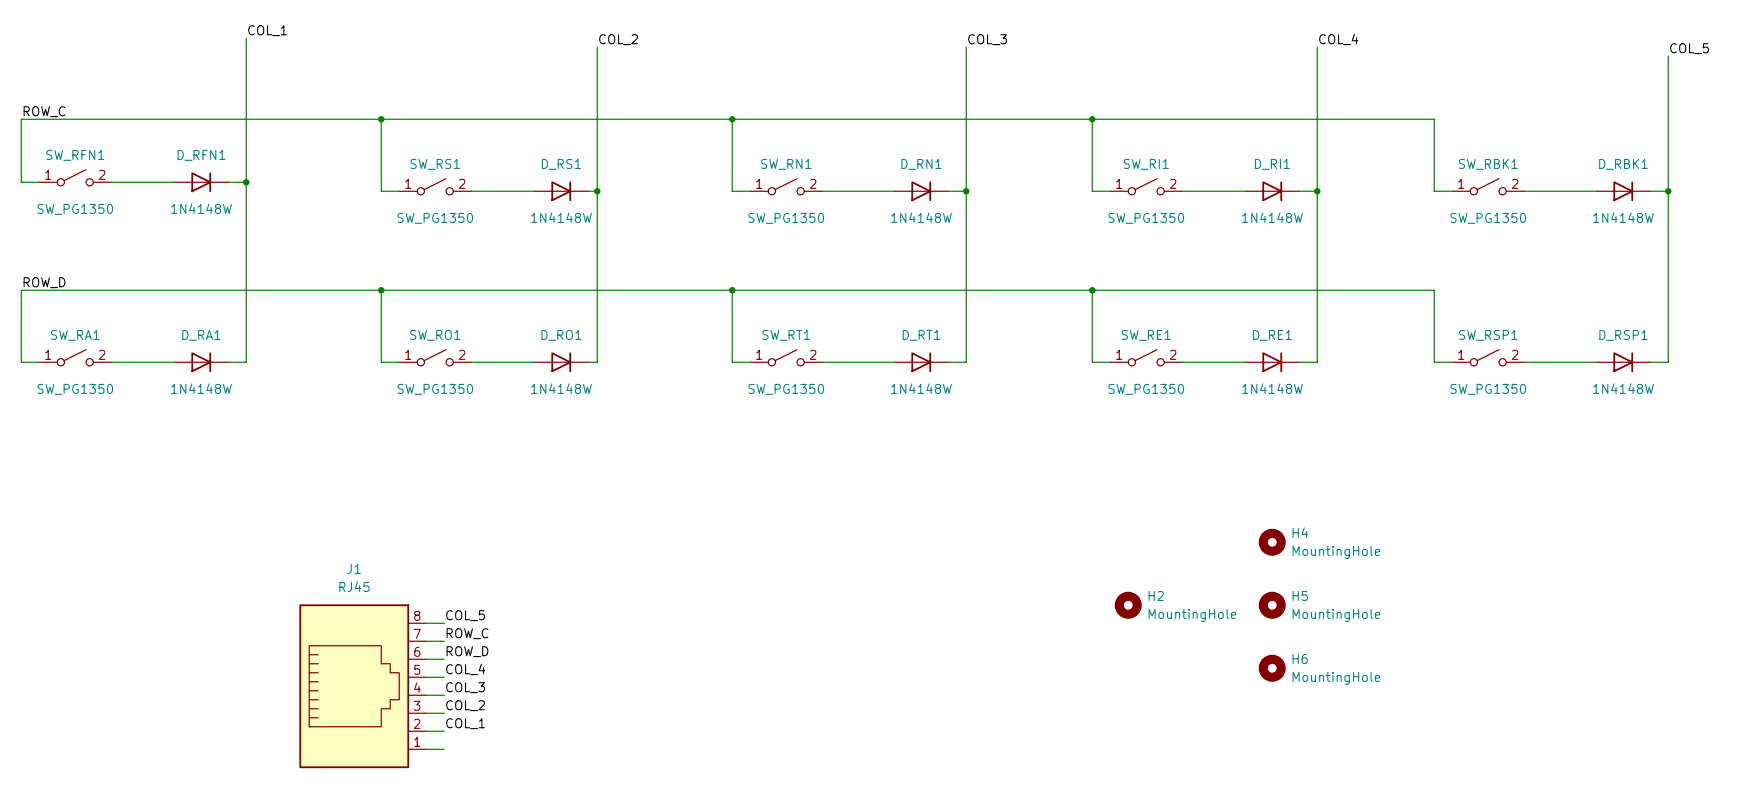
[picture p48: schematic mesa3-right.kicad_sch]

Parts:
D_RA1: 1N4148W; D_SOD-123
D_RBK1: 1N4148W; D_SOD-123
D_RE1: 1N4148W; D_SOD-123
D_RFN1: 1N4148W; D_SOD-123
D_RI1: 1N4148W; D_SOD-123
D_RN1: 1N4148W; D_SOD-123
D_RO1: 1N4148W; D_SOD-123
D_RS1: 1N4148W; D_SOD-123
D_RSP1: 1N4148W; D_SOD-123
D_RT1: 1N4148W; D_SOD-123
H2, H4, H5, H6: MountingHole; MountingHole_2.2mm_M2
J1: RJ45; RJ45_Amphenol_54602-x08_Horizontal
SW_RA1: SW_PG1350; Kailh_socket_PG1350
SW_RBK1: SW_PG1350; Kailh_socket_PG1350
SW_RE1: SW_PG1350; Kailh_socket_PG1350
SW_RFN1: SW_PG1350; Kailh_socket_PG1350
SW_RI1: SW_PG1350; Kailh_socket_PG1350
SW_RN1: SW_PG1350; Kailh_socket_PG1350
SW_RO1: SW_PG1350; Kailh_socket_PG1350
SW_RS1: SW_PG1350; Kailh_socket_PG1350
SW_RSP1: SW_PG1350; Kailh_socket_PG1350
SW_RT1: SW_PG1350; Kailh_socket_PG1350

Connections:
/COL_1: D_RA1.1 (K), D_RFN1.1 (K), J1.2
/COL_2: D_RO1.1 (K), D_RS1.1 (K), J1.3
/COL_3: D_RN1.1 (K), D_RT1.1 (K), J1.4
/COL_4: D_RE1.1 (K), D_RI1.1 (K), J1.5
/COL_5: D_RBK1.1 (K), D_RSP1.1 (K), J1.8
/ROW_C: J1.7, SW_RBK1.1 (A), SW_RFN1.1 (A), SW_RI1.1 (A), SW_RN1.1 (A), SW_RS1.1 (A)
/ROW_D: J1.6, SW_RA1.1 (A), SW_RE1.1 (A), SW_RO1.1 (A), SW_RSP1.1 (A), SW_RT1.1 (A)
unnamed: D_RA1.2 (A), SW_RA1.2 (B)
unnamed: D_RBK1.2 (A), SW_RBK1.2 (B)
unnamed: D_RE1.2 (A), SW_RE1.2 (B)
unnamed: D_RFN1.2 (A), SW_RFN1.2 (B)
unnamed: D_RI1.2 (A), SW_RI1.2 (B)
unnamed: D_RN1.2 (A), SW_RN1.2 (B)
unnamed: D_RO1.2 (A), SW_RO1.2 (B)
unnamed: D_RS1.2 (A), SW_RS1.2 (B)
unnamed: D_RSP1.2 (A), SW_RSP1.2 (B)
unnamed: D_RT1.2 (A), SW_RT1.2 (B)

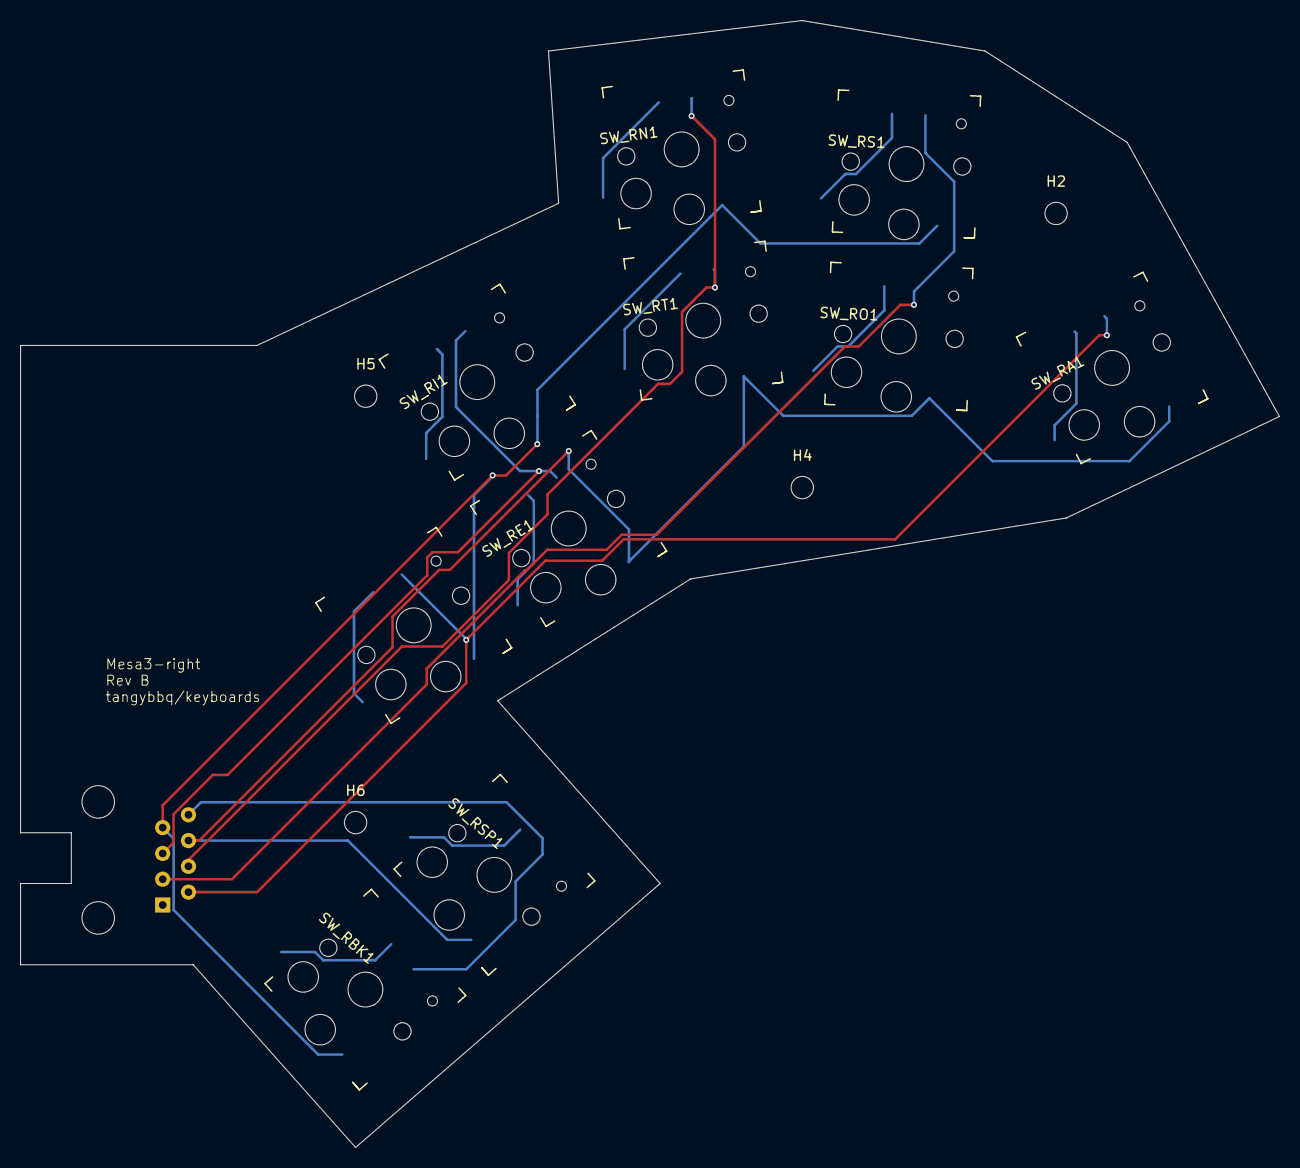
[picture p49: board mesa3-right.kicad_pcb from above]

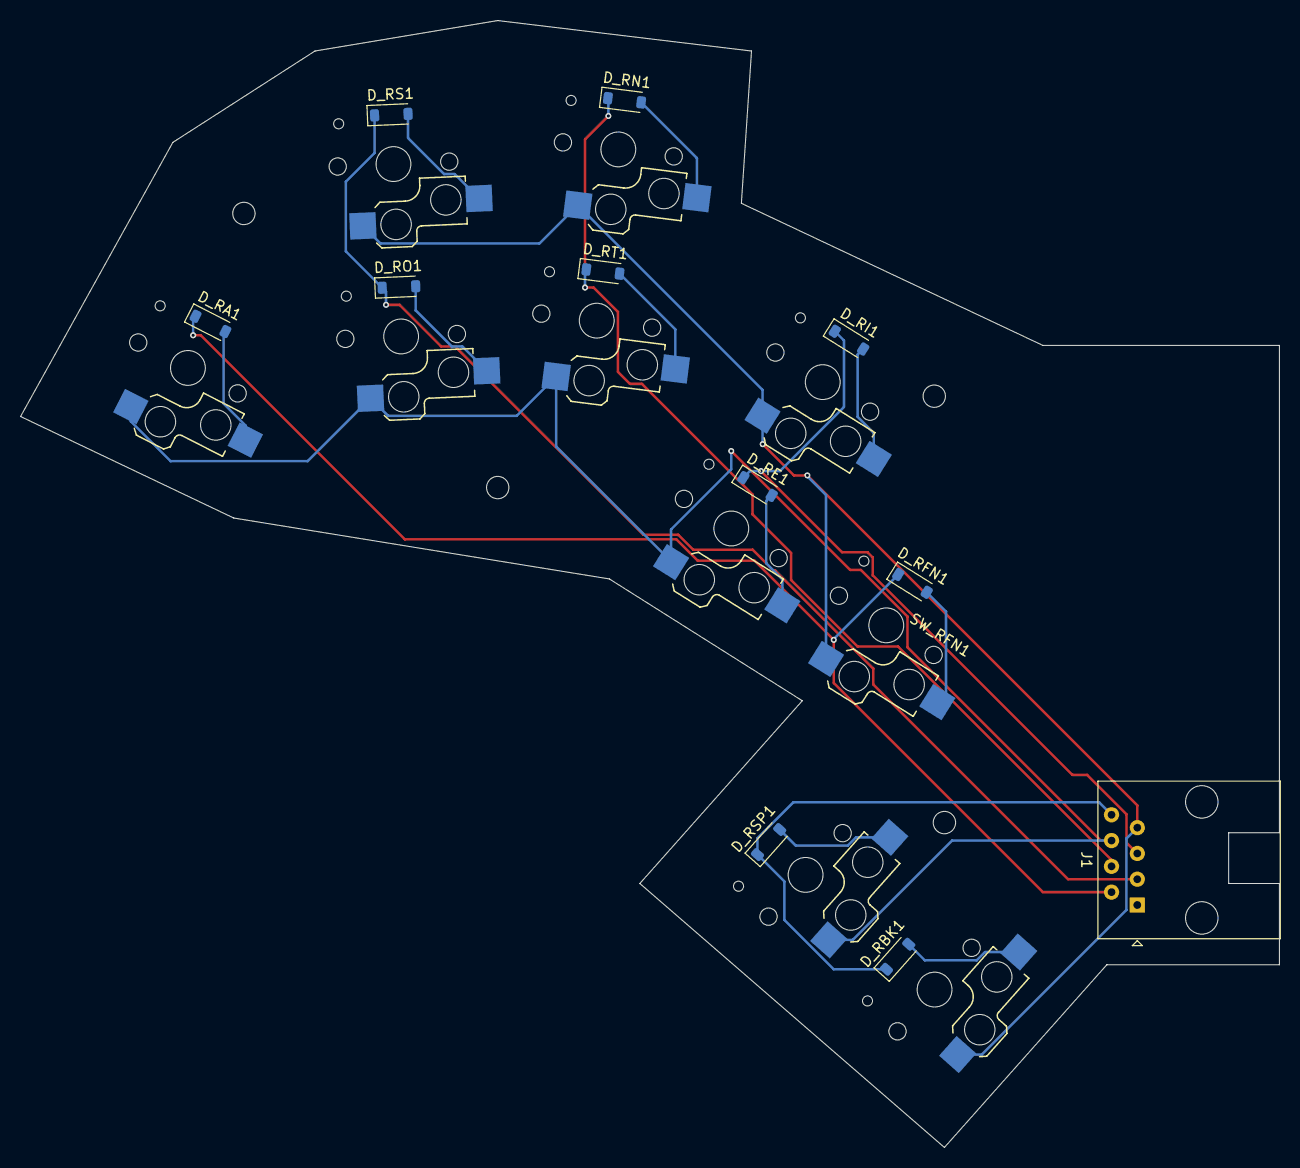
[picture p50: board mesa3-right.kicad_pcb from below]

Board: 2 copper layers, 124.0 x 111.0 mm, 25 parts (11 on the bottom side), 17 nets.

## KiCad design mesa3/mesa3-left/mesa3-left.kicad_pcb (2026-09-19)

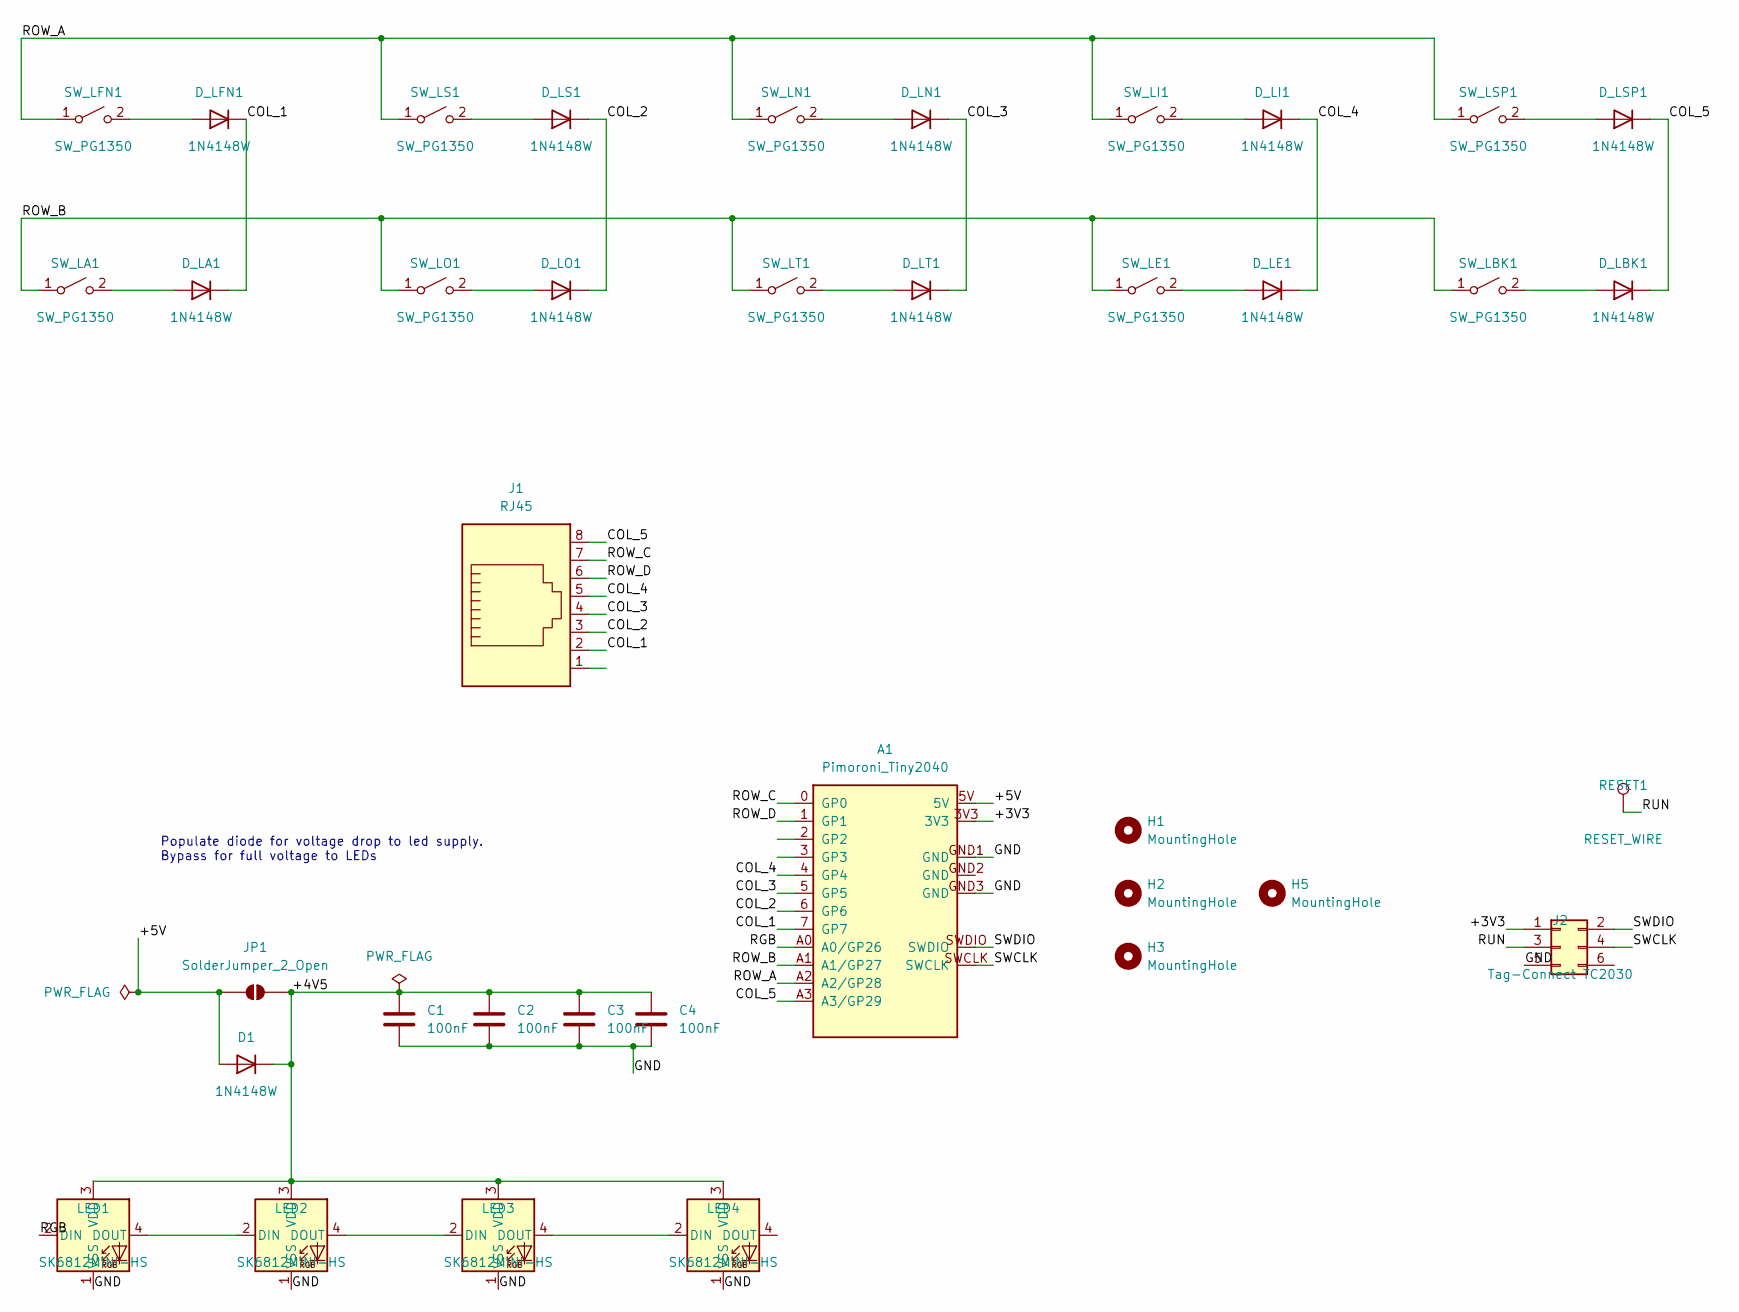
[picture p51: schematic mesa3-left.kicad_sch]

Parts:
A1: Pimoroni_Tiny2040
C1, C2, C3, C4: 100nF; C_0603_1608Metric_Pad1.08x0.95mm_HandSolder
D1: 1N4148W; D_SOD-123
D_LA1: 1N4148W; D_SOD-123
D_LBK1: 1N4148W; D_SOD-123
D_LE1: 1N4148W; D_SOD-123
D_LFN1: 1N4148W; D_SOD-123
D_LI1: 1N4148W; D_SOD-123
D_LN1: 1N4148W; D_SOD-123
D_LO1: 1N4148W; D_SOD-123
D_LS1: 1N4148W; D_SOD-123
D_LSP1: 1N4148W; D_SOD-123
D_LT1: 1N4148W; D_SOD-123
H1, H2, H3, H5: MountingHole; MountingHole_2.2mm_M2
J1: RJ45; RJ45_Amphenol_54602-x08_Horizontal
J2: Tag-Connect TC2030; Tag-Connect_TC2030-IDC-FP_2x03_P1.27mm_Vertical
JP1: SolderJumper_2_Open; SolderJumper-2_P1.3mm_Open_RoundedPad1.0x1.5mm
LED1, LED2, LED3, LED4: SK6812MINI-HS; SK6812-MINI-HS
RESET1: RESET_WIRE; TestPoint_Pad_2.0x2.0mm
SW_LA1: SW_PG1350; Kailh_socket_PG1350
SW_LBK1: SW_PG1350; Kailh_socket_PG1350
SW_LE1: SW_PG1350; Kailh_socket_PG1350
SW_LFN1: SW_PG1350; Kailh_socket_PG1350
SW_LI1: SW_PG1350; Kailh_socket_PG1350
SW_LN1: SW_PG1350; Kailh_socket_PG1350
SW_LO1: SW_PG1350; Kailh_socket_PG1350
SW_LS1: SW_PG1350; Kailh_socket_PG1350
SW_LSP1: SW_PG1350; Kailh_socket_PG1350
SW_LT1: SW_PG1350; Kailh_socket_PG1350

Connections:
/+3V3: A1.3V3, J2.1
/+4V5: C1.1, C2.1, C3.1, C4.1, D1.1 (K), JP1.2 (B), LED1.3 (VDD), LED2.3 (VDD), LED3.3 (VDD), LED4.3 (VDD)
/+5V: A1.5V, D1.2 (A), JP1.1 (A)
/COL_1: A1.7 (GP7), D_LA1.1 (K), D_LFN1.1 (K), J1.2
/COL_2: A1.6 (GP6), D_LO1.1 (K), D_LS1.1 (K), J1.3
/COL_3: A1.5 (GP5), D_LN1.1 (K), D_LT1.1 (K), J1.4
/COL_4: A1.4 (GP4), D_LE1.1 (K), D_LI1.1 (K), J1.5
/COL_5: A1.A3 (A3/GP29), D_LBK1.1 (K), D_LSP1.1 (K), J1.8
/GND: A1.GND1 (GND), A1.GND3 (GND), C1.2, C2.2, C3.2, C4.2, J2.5, LED1.1 (VSS), LED2.1 (VSS), LED3.1 (VSS), LED4.1 (VSS)
/RGB: A1.A0 (A0/GP26), LED1.2 (DIN)
/ROW_A: A1.A2 (A2/GP28), SW_LFN1.1 (A), SW_LI1.1 (A), SW_LN1.1 (A), SW_LS1.1 (A), SW_LSP1.1 (A)
/ROW_B: A1.A1 (A1/GP27), SW_LA1.1 (A), SW_LBK1.1 (A), SW_LE1.1 (A), SW_LO1.1 (A), SW_LT1.1 (A)
/ROW_C: A1.0 (GP0), J1.7
/ROW_D: A1.1 (GP1), J1.6
/RUN: J2.3, RESET1.1 (1_1)
/SWCLK: A1.SWCLK, J2.4
/SWDIO: A1.SWDIO, J2.2
unnamed: D_LA1.2 (A), SW_LA1.2 (B)
unnamed: D_LBK1.2 (A), SW_LBK1.2 (B)
unnamed: D_LE1.2 (A), SW_LE1.2 (B)
unnamed: D_LFN1.2 (A), SW_LFN1.2 (B)
unnamed: D_LI1.2 (A), SW_LI1.2 (B)
unnamed: D_LN1.2 (A), SW_LN1.2 (B)
unnamed: D_LO1.2 (A), SW_LO1.2 (B)
unnamed: D_LS1.2 (A), SW_LS1.2 (B)
unnamed: D_LSP1.2 (A), SW_LSP1.2 (B)
unnamed: D_LT1.2 (A), SW_LT1.2 (B)
unnamed: LED1.4 (DOUT), LED2.2 (DIN)
unnamed: LED2.4 (DOUT), LED3.2 (DIN)
unnamed: LED3.4 (DOUT), LED4.2 (DIN)

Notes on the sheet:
Populate diode for voltage drop to led supply. Bypass for full voltage to LEDs

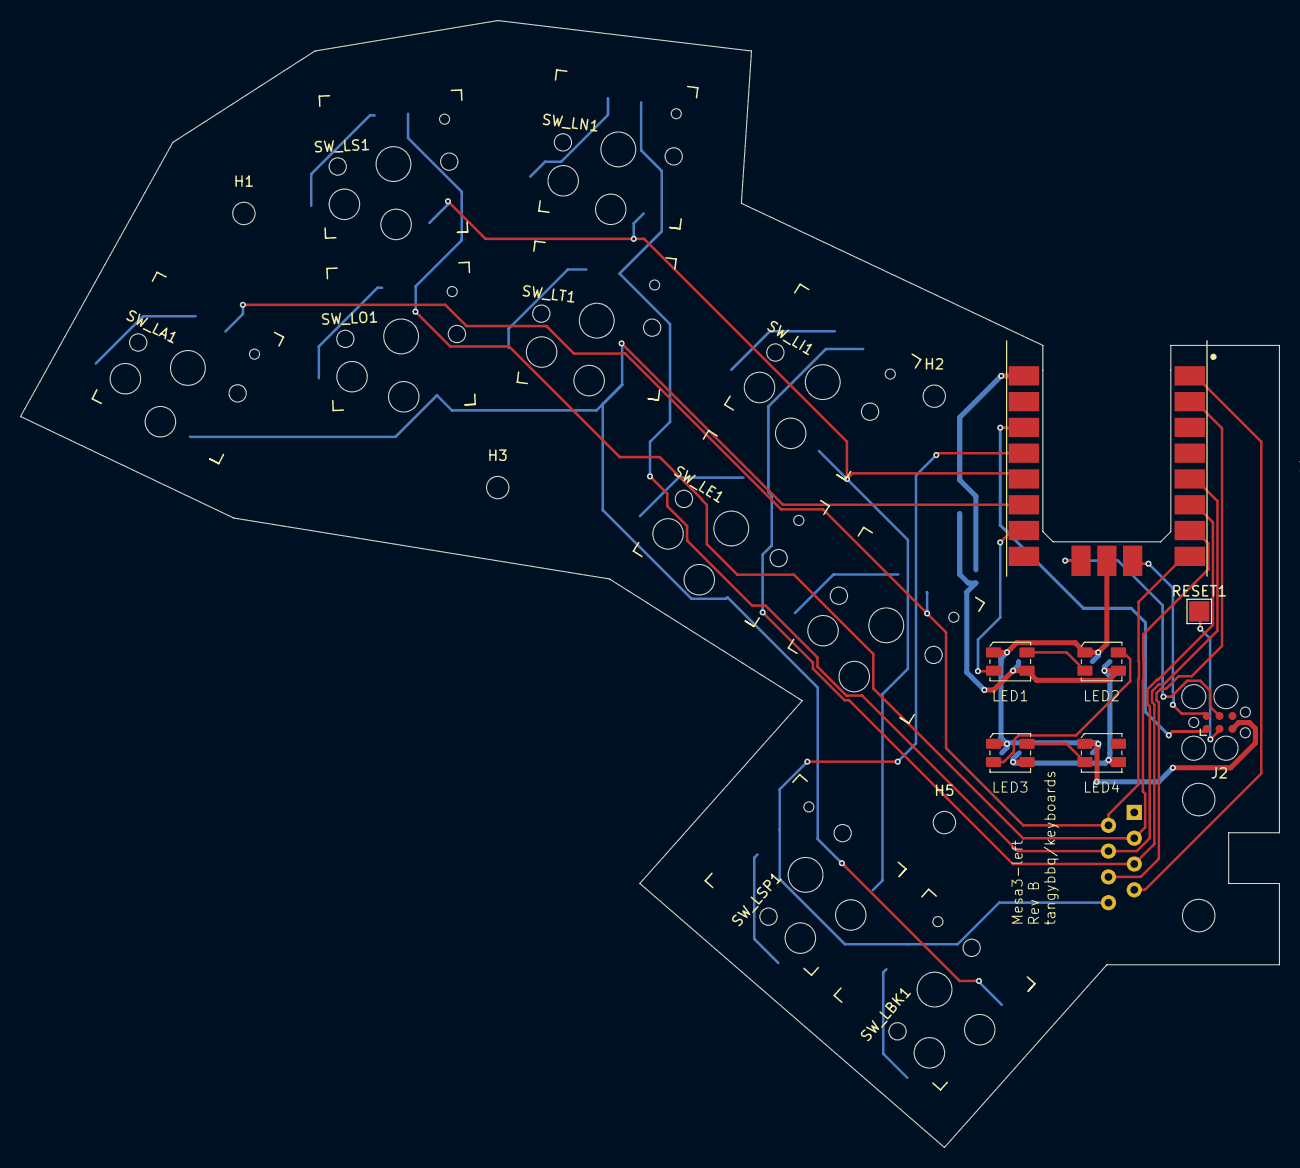
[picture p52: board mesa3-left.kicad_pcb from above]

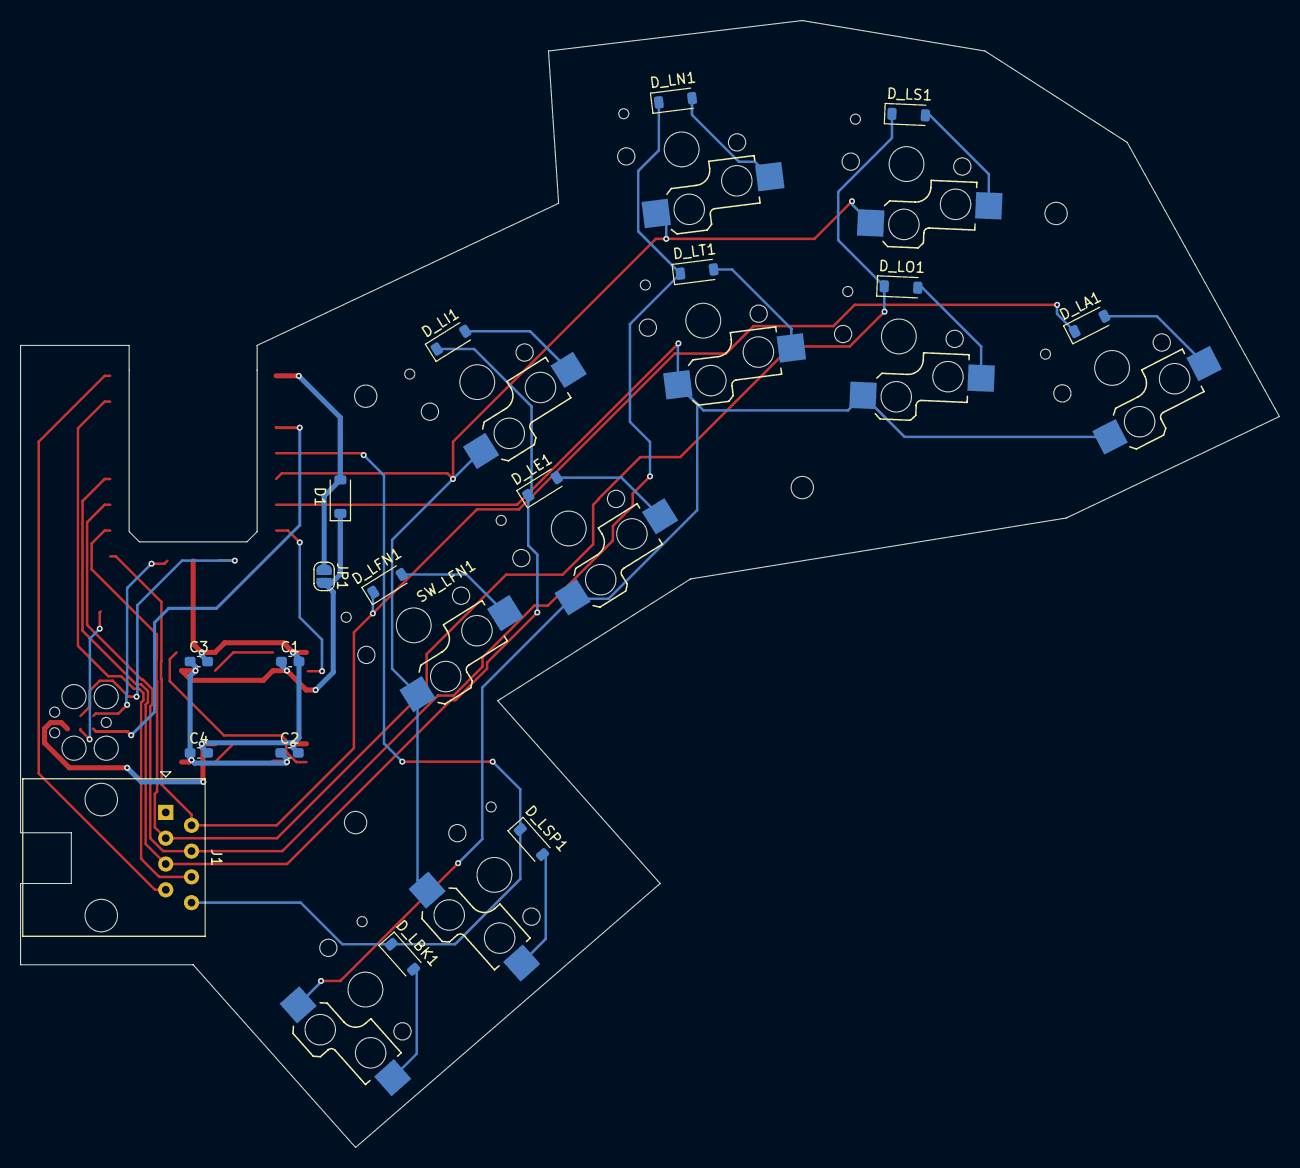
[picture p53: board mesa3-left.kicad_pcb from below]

Board: 2 copper layers, 124.0 x 111.0 mm, 38 parts (17 on the bottom side), 30 nets.

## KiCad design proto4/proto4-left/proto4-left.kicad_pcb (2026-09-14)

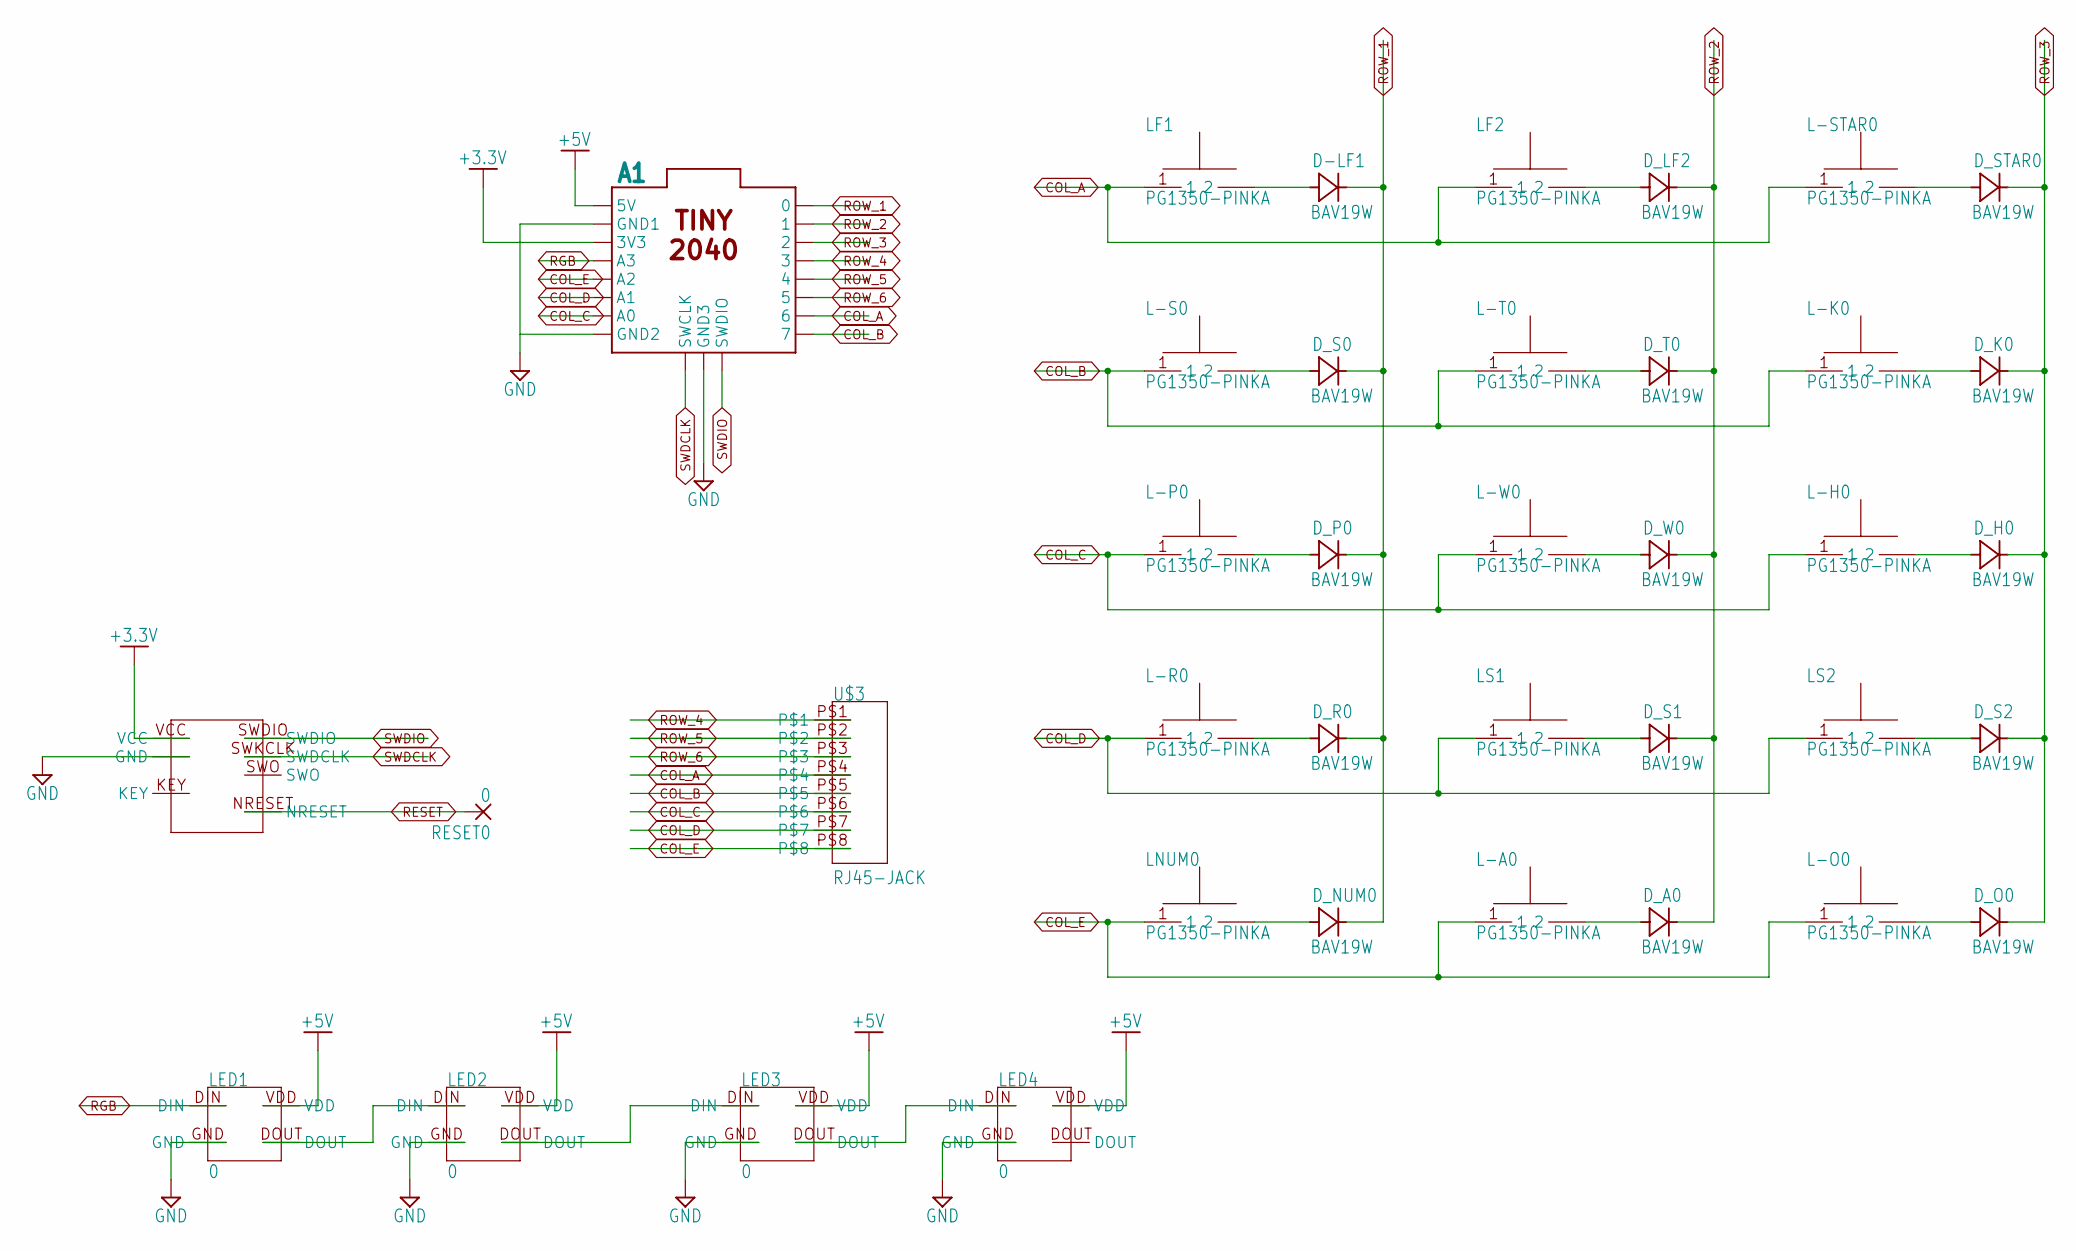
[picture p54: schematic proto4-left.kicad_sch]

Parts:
A1: TINY2040
D-LF1: BAV19W; SOD123
D_A0: BAV19W; SOD123
D_H0: BAV19W; SOD123
D_K0: BAV19W; SOD123
D_LF2: BAV19W; SOD123
D_NUM0: BAV19W; SOD123
D_O0: BAV19W; SOD123
D_P0: BAV19W; SOD123
D_R0: BAV19W; SOD123
D_S0, D_S1, D_S2: BAV19W; SOD123
D_STAR0: BAV19W; SOD123
D_T0: BAV19W; SOD123
D_W0: BAV19W; SOD123
L-A0: PG1350-PINKA; PG1350
L-H0: PG1350-PINKA; PG1350
L-K0: PG1350-PINKA; PG1350
L-O0: PG1350-PINKA; PG1350
L-P0: PG1350-PINKA; PG1350
L-R0: PG1350-PINKA; PG1350
L-S0: PG1350-PINKA; PG1350
L-STAR0: PG1350-PINKA; PG1350
L-T0: PG1350-PINKA; PG1350
L-W0: PG1350-PINKA; PG1350
LED1, LED2, LED3, LED4: 0; SK6812-MINI-HS
LF1, LF2: PG1350-PINKA; PG1350
LNUM0: PG1350-PINKA; PG1350
LS1, LS2: PG1350-PINKA; PG1350
RESET0: 0; SMD1,27-2,54
U$2: CORTEX-M0; CORTEX-M10
U$3: RJ45-JACK; C-BMJ-0051-RJ45

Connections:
+3.3V: A1.3V3, U$2.VCC
+5V: A1.5V, LED1.VDD, LED2.VDD, LED3.VDD, LED4.VDD
COL_A: A1.6, L-STAR0.1, LF1.1, LF2.1, U$3.P$4
COL_B: A1.7, L-K0.1, L-S0.1, L-T0.1, U$3.P$5
COL_C: A1.A0, L-H0.1, L-P0.1, L-W0.1, U$3.P$6
COL_D: A1.A1, L-R0.1, LS1.1, LS2.1, U$3.P$7
COL_E: A1.A2, L-A0.1, L-O0.1, LNUM0.1, U$3.P$8
GND: A1.GND1, A1.GND3, LED1.GND, LED2.GND, LED3.GND, LED4.GND, U$2.GND2 (GND), U$2.GND3 (GND), U$2.GNDDETECT (GND)
unnamed: D-LF1.A, LF1.2B (2), LF1.2T (2)
unnamed: D_LF2.A, LF2.2B (2), LF2.2T (2)
unnamed: D_STAR0.A, L-STAR0.2B (2), L-STAR0.2T (2)
unnamed: D_S0.A, L-S0.2B (2), L-S0.2T (2)
unnamed: D_T0.A, L-T0.2B (2), L-T0.2T (2)
unnamed: D_K0.A, L-K0.2B (2), L-K0.2T (2)
unnamed: D_P0.A, L-P0.2B (2), L-P0.2T (2)
unnamed: D_W0.A, L-W0.2B (2), L-W0.2T (2)
unnamed: D_H0.A, L-H0.2B (2), L-H0.2T (2)
unnamed: D_R0.A, L-R0.2B (2), L-R0.2T (2)
unnamed: D_S1.A, LS1.2B (2), LS1.2T (2)
unnamed: D_S2.A, LS2.2B (2), LS2.2T (2)
unnamed: D_NUM0.A, LNUM0.2B (2), LNUM0.2T (2)
unnamed: D_A0.A, L-A0.2B (2), L-A0.2T (2)
unnamed: D_O0.A, L-O0.2B (2), L-O0.2T (2)
unnamed: LED3.DOUT, LED4.DIN
unnamed: LED2.DOUT, LED3.DIN
unnamed: LED1.DOUT, LED2.DIN
RESET: RESET0.1, U$2.NRESET
RGB: A1.A3, LED1.DIN
ROW_1: A1.0, D-LF1.C, D_NUM0.C, D_P0.C, D_R0.C, D_S0.C
ROW_2: A1.1, D_A0.C, D_LF2.C, D_S1.C, D_T0.C, D_W0.C
ROW_3: A1.2, D_H0.C, D_K0.C, D_O0.C, D_S2.C, D_STAR0.C
ROW_4: A1.3, U$3.P$1
ROW_5: A1.4, U$3.P$2
ROW_6: A1.5, U$3.P$3
SWDCLK: A1.SWCLK, U$2.SWKCLK (SWDCLK)
SWDIO: A1.SWDIO, U$2.SWDIO

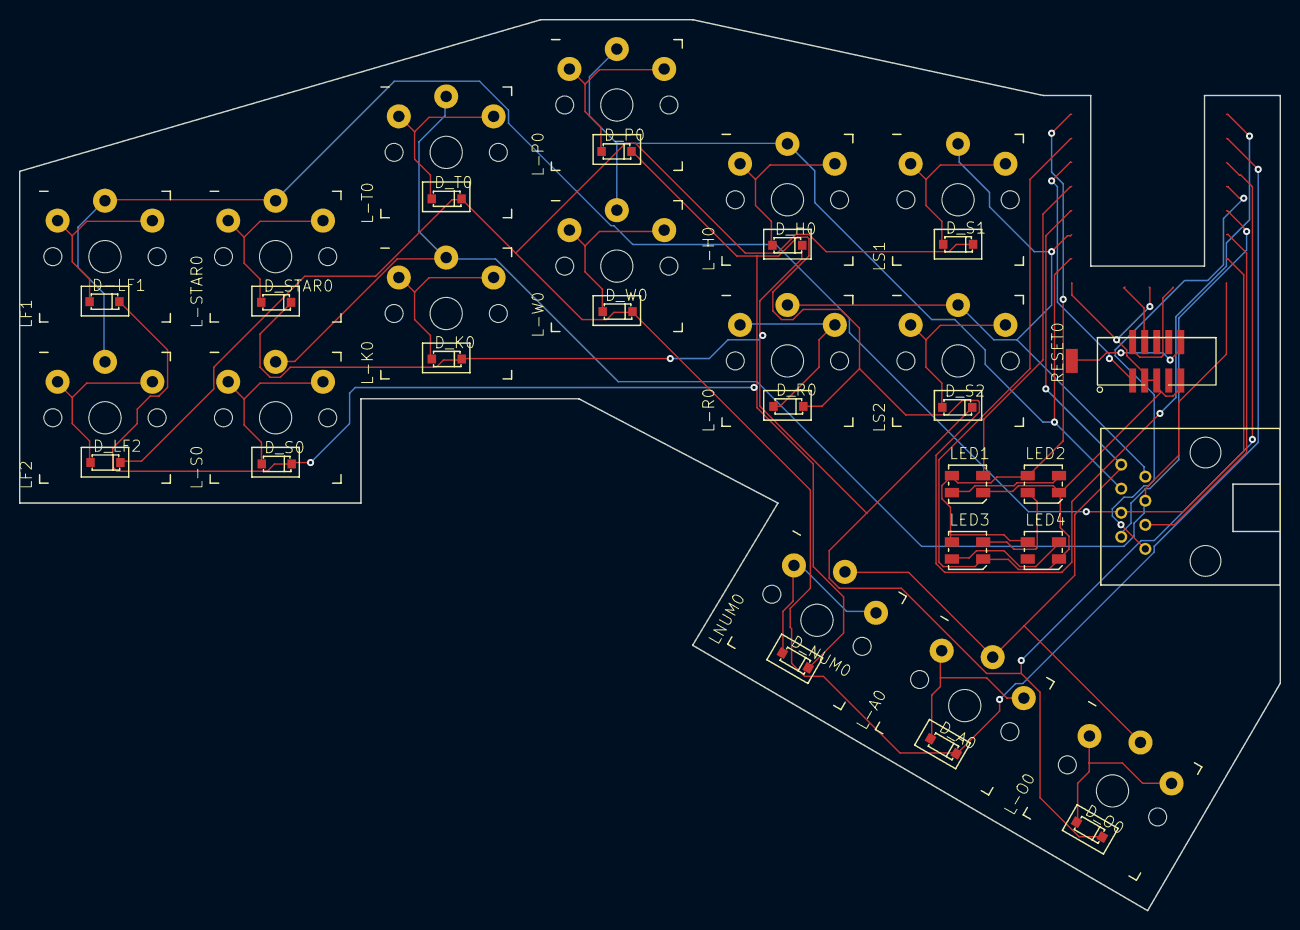
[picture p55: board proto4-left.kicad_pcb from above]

Board: 2 copper layers, 133.0 x 94.0 mm, 37 parts (0 on the bottom side), 29 nets.

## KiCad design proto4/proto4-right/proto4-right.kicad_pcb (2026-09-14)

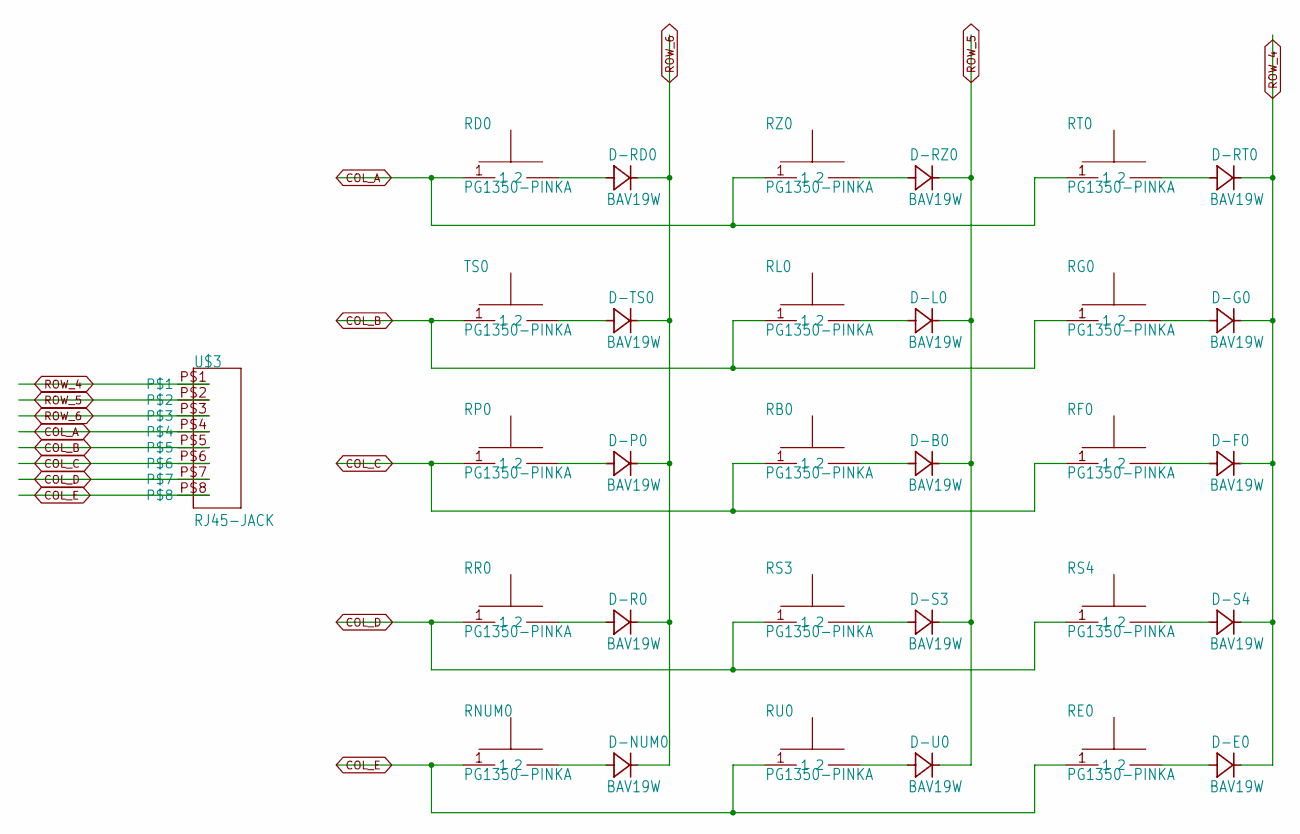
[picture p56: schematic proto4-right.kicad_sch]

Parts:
D-B0: BAV19W; SOD123
D-E0: BAV19W; SOD123
D-F0: BAV19W; SOD123
D-G0: BAV19W; SOD123
D-L0: BAV19W; SOD123
D-NUM0: BAV19W; SOD123
D-P0: BAV19W; SOD123
D-R0: BAV19W; SOD123
D-RD0: BAV19W; SOD123
D-RT0: BAV19W; SOD123
D-RZ0: BAV19W; SOD123
D-S3, D-S4: BAV19W; SOD123
D-TS0: BAV19W; SOD123
D-U0: BAV19W; SOD123
RB0: PG1350-PINKA; PG1350
RD0: PG1350-PINKA; PG1350
RE0: PG1350-PINKA; PG1350
RF0: PG1350-PINKA; PG1350
RG0: PG1350-PINKA; PG1350
RL0: PG1350-PINKA; PG1350
RNUM0: PG1350-PINKA; PG1350
RP0: PG1350-PINKA; PG1350
RR0: PG1350-PINKA; PG1350
RS3, RS4: PG1350-PINKA; PG1350
RT0: PG1350-PINKA; PG1350
RU0: PG1350-PINKA; PG1350
RZ0: PG1350-PINKA; PG1350
TS0: PG1350-PINKA; PG1350
U$3: RJ45-JACK; C-BMJ-0051-RJ45

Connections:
COL_A: RD0.1, RT0.1, RZ0.1, U$3.P$4
COL_B: RG0.1, RL0.1, TS0.1, U$3.P$5
COL_C: RB0.1, RF0.1, RP0.1, U$3.P$6
COL_D: RR0.1, RS3.1, RS4.1, U$3.P$7
COL_E: RE0.1, RNUM0.1, RU0.1, U$3.P$8
unnamed: D-RD0.A, RD0.2B (2), RD0.2T (2)
unnamed: D-RZ0.A, RZ0.2B (2), RZ0.2T (2)
unnamed: D-RT0.A, RT0.2B (2), RT0.2T (2)
unnamed: D-TS0.A, TS0.2B (2), TS0.2T (2)
unnamed: D-L0.A, RL0.2B (2), RL0.2T (2)
unnamed: D-G0.A, RG0.2B (2), RG0.2T (2)
unnamed: D-P0.A, RP0.2B (2), RP0.2T (2)
unnamed: D-B0.A, RB0.2B (2), RB0.2T (2)
unnamed: D-F0.A, RF0.2B (2), RF0.2T (2)
unnamed: D-R0.A, RR0.2B (2), RR0.2T (2)
unnamed: D-S3.A, RS3.2B (2), RS3.2T (2)
unnamed: D-S4.A, RS4.2B (2), RS4.2T (2)
unnamed: D-NUM0.A, RNUM0.2B (2), RNUM0.2T (2)
unnamed: D-U0.A, RU0.2B (2), RU0.2T (2)
unnamed: D-E0.A, RE0.2B (2), RE0.2T (2)
ROW_4: D-E0.C, D-F0.C, D-G0.C, D-RT0.C, D-S4.C, U$3.P$1
ROW_5: D-B0.C, D-L0.C, D-RZ0.C, D-S3.C, D-U0.C, U$3.P$2
ROW_6: D-NUM0.C, D-P0.C, D-R0.C, D-RD0.C, D-TS0.C, U$3.P$3

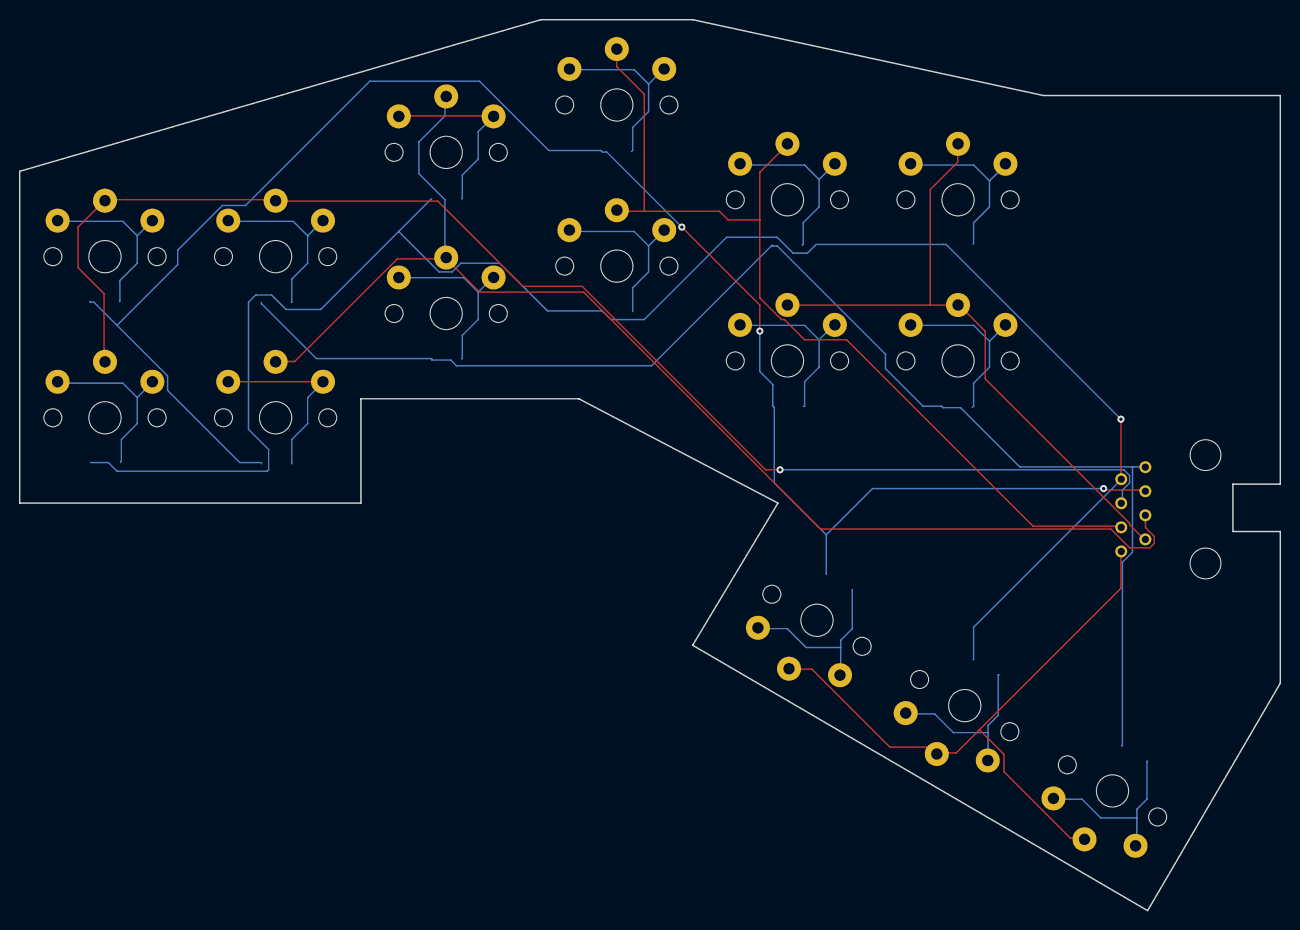
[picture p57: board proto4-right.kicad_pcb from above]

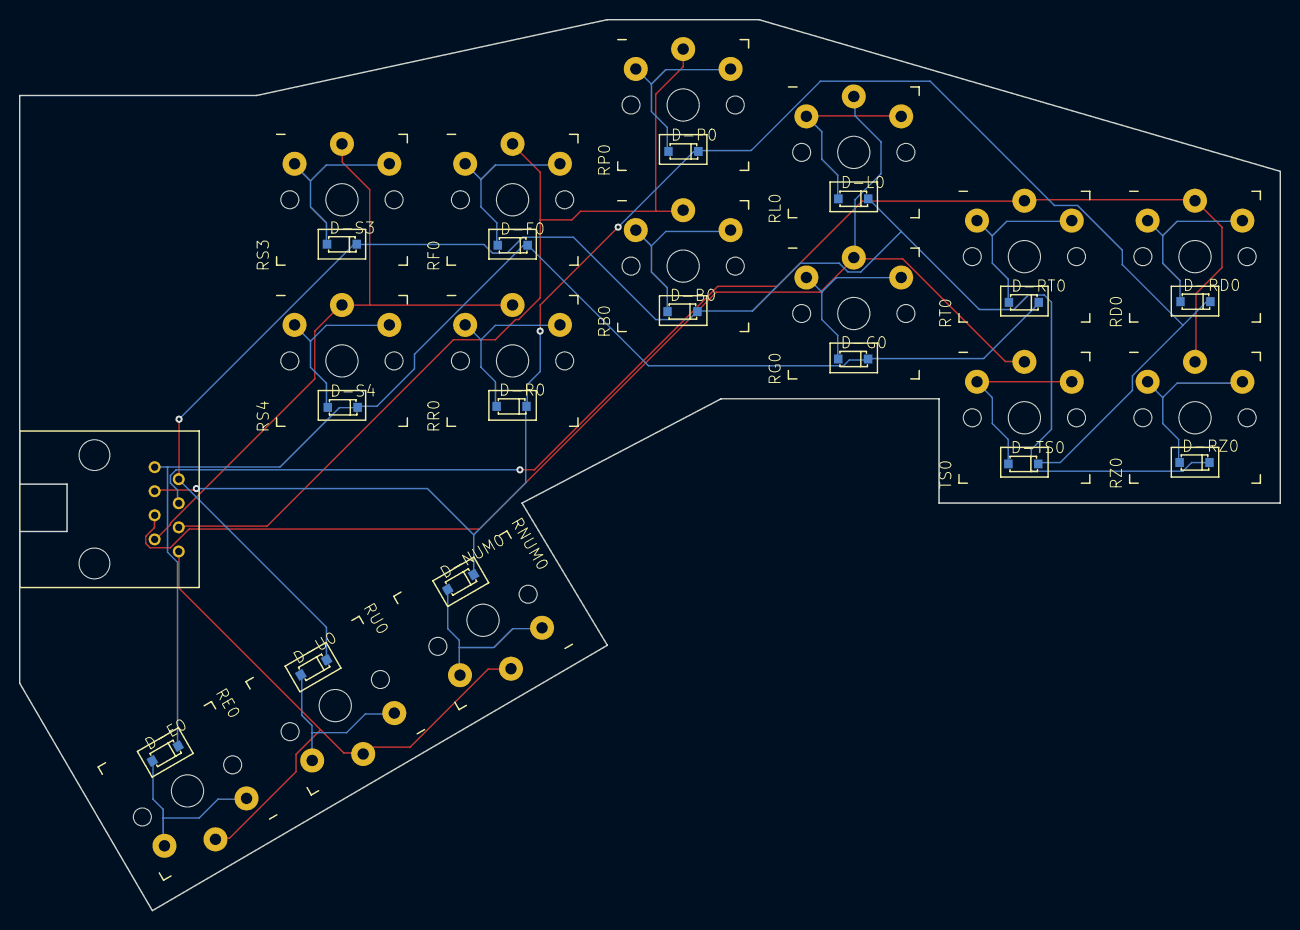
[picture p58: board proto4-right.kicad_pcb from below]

Board: 2 copper layers, 133.0 x 94.0 mm, 31 parts (31 on the bottom side), 23 nets.

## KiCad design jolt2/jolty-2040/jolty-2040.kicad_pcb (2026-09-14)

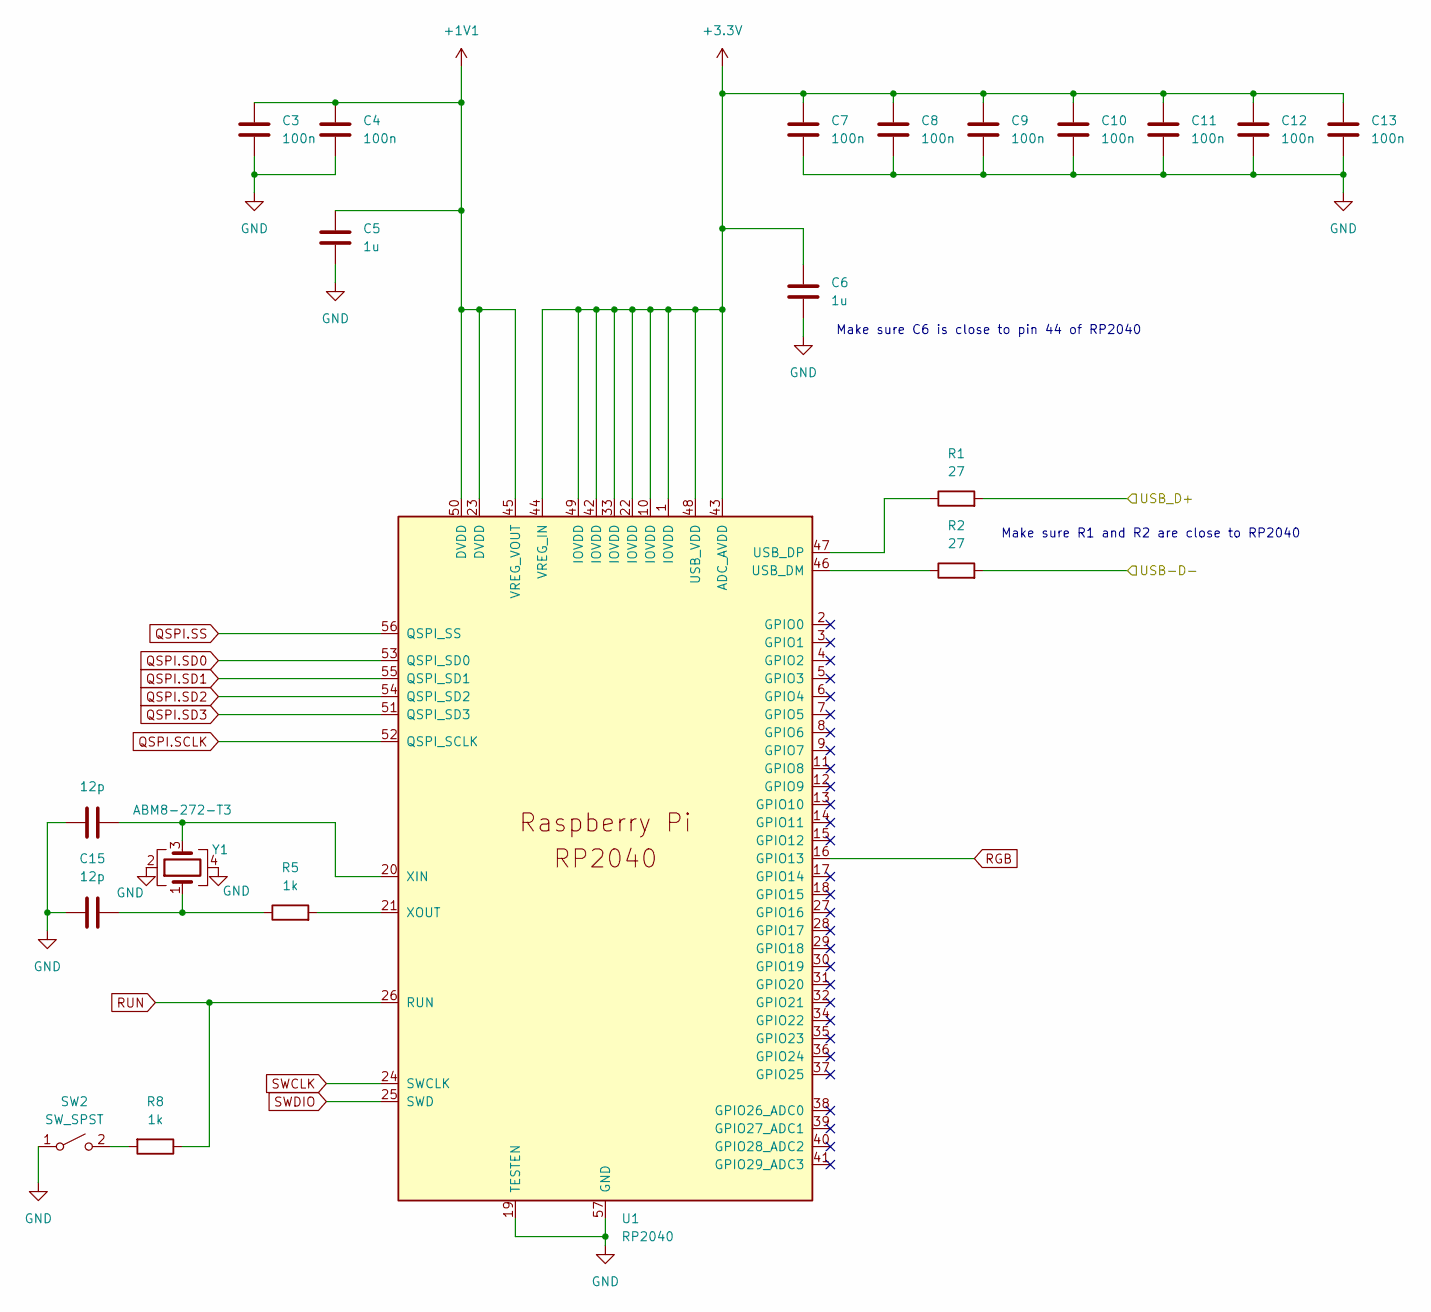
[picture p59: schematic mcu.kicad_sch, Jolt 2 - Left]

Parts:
C3, C4, C7, C8, C9, C10, C11, C12, C13: 100n; C_0402_1005Metric_Pad0.74x0.62mm_HandSolder
C5, C6: 1u; C_0402_1005Metric_Pad0.74x0.62mm_HandSolder
C14, C15: 12p; C_0402_1005Metric_Pad0.74x0.62mm_HandSolder
R1, R2: 27; R_0402_1005Metric_Pad0.72x0.64mm_HandSolder
R5, R8: 1k; R_0402_1005Metric_Pad0.72x0.64mm_HandSolder
SW2: SW_SPST; SW_Push_1P1T_NO_CK_KMR2
U1: RP2040; RP2040-QFN-56
Y1: ABM8-272-T3; Crystal_SMD_Abracon_ABM8G-4Pin_3.2x2.5mm

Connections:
+1V1: C3.1, C4.1, C5.1, U1.23 (DVDD), U1.45 (VREG_VOUT), U1.50 (DVDD)
+3.3V: C6.1, C7.1, C8.1, C9.1, C10.1, C11.1, C12.1, C13.1, U1.1 (IOVDD), U1.10 (IOVDD), U1.22 (IOVDD), U1.33 (IOVDD), U1.42 (IOVDD), U1.43 (ADC_AVDD), U1.44 (VREG_IN), U1.48 (USB_VDD), U1.49 (IOVDD); also elsewhere on the board
/USB_D+: R1.2; also elsewhere on the board
/USB_D-: R2.2; also elsewhere on the board
GND: C3.2, C4.2, C5.2, C6.2, C7.2, C8.2, C9.2, C10.2, C11.2, C12.2, C13.2, C14.1, C15.1, SW2.1 (A), U1.19 (TESTEN), U1.57 (GND), Y1.2, Y1.4; also elsewhere on the board
unnamed: C15.2, R5.1, Y1.1
unnamed: R8.2, SW2.2 (B)
unnamed: R2.1, U1.46 (USB_DM)
unnamed: R1.1, U1.47 (USB_DP)
unnamed: C14.2, U1.20 (XIN), Y1.3
unnamed: R5.2, U1.21 (XOUT)
QSPI.SCLK: U1.52 (QSPI_SCLK); also elsewhere on the board
QSPI.SD0: U1.53 (QSPI_SD0); also elsewhere on the board
QSPI.SD1: U1.55 (QSPI_SD1); also elsewhere on the board
QSPI.SD2: U1.54 (QSPI_SD2); also elsewhere on the board
QSPI.SD3: U1.51 (QSPI_SD3); also elsewhere on the board
QSPI.SS: U1.56 (QSPI_SS); also elsewhere on the board
RGB: U1.16 (GPIO13); also elsewhere on the board
RUN: R8.1, U1.26 (RUN); also elsewhere on the board
SWCLK: U1.24 (SWCLK); also elsewhere on the board
SWDIO: U1.25 (SWD); also elsewhere on the board

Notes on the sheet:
Make sure R1 and R2 are close to RP2040
Make sure C6 is close to pin 44 of RP2040


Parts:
C16: 100n; C_0402_1005Metric_Pad0.74x0.62mm_HandSolder
R6: 1k; R_0402_1005Metric_Pad0.72x0.64mm_HandSolder
R7: 10k; R_0402_1005Metric_Pad0.72x0.64mm_HandSolder; not fitted
SW1: SW_SPST; SW_Push_1P1T_NO_CK_KMR2
U3: W25Q128JVP; WSON-8-1EP_6x5mm_P1.27mm_EP3.4x4.3mm

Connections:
+3.3V: C16.1, R7.2, U3.8 (VCC); also elsewhere on the board
GND: C16.2, SW1.1 (A), U3.4 (GND); also elsewhere on the board
unnamed: R6.1, SW1.2 (B)
QSPI.SCLK: U3.6 (CLK); also elsewhere on the board
QSPI.SD0: U3.5 (DI(IO0)); also elsewhere on the board
QSPI.SD1: U3.2 (DO(IO1)); also elsewhere on the board
QSPI.SD2: U3.3 (IO2); also elsewhere on the board
QSPI.SD3: U3.7 (IO3); also elsewhere on the board
QSPI.SS: R6.2, R7.1, U3.1 (~CS); also elsewhere on the board


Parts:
C1, C2: 10u; C_0402_1005Metric_Pad0.74x0.62mm_HandSolder
D1, D2: SK6812MINI-HS; SK6812-MINI-HS
J29: USB_C_Receptacle_USB2.0_14P; USB_C_Receptacle_GCT_USB4085
J30: Conn_ARM_JTAG_SWD_10; Cortex-M-Debug10
R3, R4: 5.1k; R_0402_1005Metric_Pad0.72x0.64mm_HandSolder
U2: AP2112-M3.3; AP2112M-SO8

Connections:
+3.3V: C2.1, D1.3 (VDD), D2.3 (VDD), J30.1 (VTref), U2.1 (VOUT); also elsewhere on the board
/USB_D+: J29.A6 (D+), J29.B6 (D+); also elsewhere on the board
/USB_D-: J29.A7 (D-), J29.B7 (D-); also elsewhere on the board
GND: C1.2, C2.2, D1.1 (VSS), D2.1 (VSS), J29.A1 (GND), J29.A12 (GND), J29.B1 (GND), J29.B12 (GND), J29.S1 (SHIELD), J30.3 (GND), J30.5 (GND), J30.9 (GNDDetect), R3.2, R4.2, U2.6 (GND), U2.7 (GND); also elsewhere on the board
unnamed: D1.4 (DOUT), D2.2 (DIN)
unnamed: J29.A5 (CC1), R4.1
unnamed: J29.B5 (CC2), R3.1
RGB: D1.2 (DIN); also elsewhere on the board
RUN: J30.10 (~RESET); also elsewhere on the board
SWCLK: J30.4 (SWCLK/TCK); also elsewhere on the board
SWDIO: J30.2 (SWDIO/TMS); also elsewhere on the board
VBUS: C1.1, J29.A4 (VBUS), J29.A9 (VBUS), J29.B4 (VBUS), J29.B9 (VBUS), U2.5 (EN), U2.8 (VIN)

Board: 4 copper layers, 34 parts (0 on the bottom side), 26 nets, no tracks yet.

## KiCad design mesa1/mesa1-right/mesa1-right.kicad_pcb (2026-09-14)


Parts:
D_RB0: 1N4148W; D_SOD-123
D_RD0: 1N4148W; D_SOD-123
D_RE0: 1N4148W; D_SOD-123
D_RF0: 1N4148W; D_SOD-123
D_RG0: 1N4148W; D_SOD-123
D_RL0: 1N4148W; D_SOD-123
D_RNUM0: 1N4148W; D_SOD-123
D_RP0: 1N4148W; D_SOD-123
D_RR0: 1N4148W; D_SOD-123
D_RS3, D_RS4: 1N4148W; D_SOD-123
D_RT0: 1N4148W; D_SOD-123
D_RU0: 1N4148W; D_SOD-123
D_RZ0: 1N4148W; D_SOD-123
D_TS0: 1N4148W; D_SOD-123
J1: RJ45; RJ45_Amphenol_54602-x08_Horizontal
RB0: SW_PG1350; Kailh_socket_PG1350
RD0: SW_PG1350; Kailh_socket_PG1350
RE0: SW_PG1350; Kailh_socket_PG1350
RF0: SW_PG1350; Kailh_socket_PG1350
RG0: SW_PG1350; Kailh_socket_PG1350
RL0: SW_PG1350; Kailh_socket_PG1350
RNUM0: SW_PG1350; Kailh_socket_PG1350
RP0: SW_PG1350; Kailh_socket_PG1350
RR0: SW_PG1350; Kailh_socket_PG1350
RS3, RS4: SW_PG1350; Kailh_socket_PG1350
RT0: SW_PG1350; Kailh_socket_PG1350
RU0: SW_PG1350; Kailh_socket_PG1350
RZ0: SW_PG1350; Kailh_socket_PG1350
TS0: SW_PG1350; Kailh_socket_PG1350

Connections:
/COL_4: J1.1, RB0.1 (A), RD0.1 (A), RNUM0.1 (A), RP0.1 (A), RZ0.1 (A)
/COL_5: J1.2, RF0.1 (A), RR0.1 (A), RT0.1 (A), RU0.1 (A), TS0.1 (A)
/COL_6: J1.3, RE0.1 (A), RG0.1 (A), RL0.1 (A), RS3.1 (A), RS4.1 (A)
/ROW_A: D_RD0.1 (K), D_RL0.1 (K), D_RT0.1 (K), J1.4
/ROW_B: D_RF0.1 (K), D_RP0.1 (K), D_RS3.1 (K), J1.5
/ROW_C: D_RG0.1 (K), D_RZ0.1 (K), D_TS0.1 (K), J1.6
/ROW_D: D_RB0.1 (K), D_RR0.1 (K), D_RS4.1 (K), J1.7
/ROW_E: D_RE0.1 (K), D_RNUM0.1 (K), D_RU0.1 (K), J1.8
unnamed: D_RB0.2 (A), RB0.2 (B)
unnamed: D_RD0.2 (A), RD0.2 (B)
unnamed: D_RE0.2 (A), RE0.2 (B)
unnamed: D_RF0.2 (A), RF0.2 (B)
unnamed: D_RG0.2 (A), RG0.2 (B)
unnamed: D_RL0.2 (A), RL0.2 (B)
unnamed: D_RNUM0.2 (A), RNUM0.2 (B)
unnamed: D_RP0.2 (A), RP0.2 (B)
unnamed: D_RR0.2 (A), RR0.2 (B)
unnamed: D_RS3.2 (A), RS3.2 (B)
unnamed: D_RS4.2 (A), RS4.2 (B)
unnamed: D_RT0.2 (A), RT0.2 (B)
unnamed: D_RU0.2 (A), RU0.2 (B)
unnamed: D_RZ0.2 (A), RZ0.2 (B)
unnamed: D_TS0.2 (A), TS0.2 (B)



Board: 2 copper layers, 133.0 x 94.0 mm, 31 parts (16 on the bottom side), 23 nets.

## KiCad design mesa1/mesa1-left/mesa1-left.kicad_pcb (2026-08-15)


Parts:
A1: Pimoroni_Tiny2040
D_LA0: 1N4148W; D_SOD-123
D_LF1, D_LF2: 1N4148W; D_SOD-123
D_LH0: 1N4148W; D_SOD-123
D_LK0: 1N4148W; D_SOD-123
D_LNUM0: 1N4148W; D_SOD-123
D_LO0: 1N4148W; D_SOD-123
D_LP0: 1N4148W; D_SOD-123
D_LR0: 1N4148W; D_SOD-123
D_LS0, D_LS1, D_LS2: 1N4148W; D_SOD-123
D_LSTAR0: 1N4148W; D_SOD-123
D_LT0: 1N4148W; D_SOD-123
D_LW0: 1N4148W; D_SOD-123
J1: RJ45; RJ45_Amphenol_54602-x08_Horizontal
J2: Tag-Connect TC2030; Tag-Connect_TC2030-IDC-FP_2x03_P1.27mm_Vertical
L-A0: SW_PG1350; Kailh_socket_PG1350
L-H0: SW_PG1350; Kailh_socket_PG1350
L-K0: SW_PG1350; Kailh_socket_PG1350
L-O0: SW_PG1350; Kailh_socket_PG1350
L-P0: SW_PG1350; Kailh_socket_PG1350
L-R0: SW_PG1350; Kailh_socket_PG1350
L-S0: SW_PG1350; Kailh_socket_PG1350
L-STAR0: SW_PG1350; Kailh_socket_PG1350
L-T0: SW_PG1350; Kailh_socket_PG1350
L-W0: SW_PG1350; Kailh_socket_PG1350
LED1, LED2, LED3, LED4: SK6812MINI-HS; SK6812-MINI-HS
LF1, LF2: SW_PG1350; Kailh_socket_PG1350
LNUM0: SW_PG1350; Kailh_socket_PG1350
LS1, LS2: SW_PG1350; Kailh_socket_PG1350
RESET1: RESET_WIRE; TestPoint_Pad_2.0x2.0mm

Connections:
/+3V3: A1.3V3, J2.1
/+5V: A1.5V, LED1.3 (VDD), LED2.3 (VDD), LED3.3 (VDD), LED4.3 (VDD)
/COL_1: A1.A1 (A1/GP27), L-P0.1 (A), L-W0.1 (A), LF1.1 (A), LF2.1 (A), LNUM0.1 (A)
/COL_2: A1.A2 (A2/GP28), L-A0.1 (A), L-H0.1 (A), L-R0.1 (A), L-S0.1 (A), L-STAR0.1 (A)
/COL_3: A1.A3 (A3/GP29), L-K0.1 (A), L-O0.1 (A), L-T0.1 (A), LS1.1 (A), LS2.1 (A)
/COL_4: A1.7 (GP7), J1.1
/COL_5: A1.6 (GP6), J1.2
/COL_6: A1.5 (GP5), J1.3
/GND: A1.GND1 (GND), A1.GND3 (GND), J2.5, LED1.1 (VSS), LED2.1 (VSS), LED3.1 (VSS), LED4.1 (VSS)
/RGB: A1.A0 (A0/GP26), LED1.2 (DIN)
/ROW_A: A1.4 (GP4), D_LF1.1 (K), D_LSTAR0.1 (K), D_LT0.1 (K), J1.4
/ROW_B: A1.3 (GP3), D_LH0.1 (K), D_LP0.1 (K), D_LS1.1 (K), J1.5
/ROW_C: A1.2 (GP2), D_LF2.1 (K), D_LK0.1 (K), D_LS0.1 (K), J1.6
/ROW_D: A1.1 (GP1), D_LR0.1 (K), D_LS2.1 (K), D_LW0.1 (K), J1.7
/ROW_E: A1.0 (GP0), D_LA0.1 (K), D_LNUM0.1 (K), D_LO0.1 (K), J1.8
/RUN: J2.3, RESET1.1 (1_1)
/SWCLK: A1.SWCLK, J2.4
/SWDIO: A1.SWDIO, J2.2
unnamed: D_LA0.2 (A), L-A0.2 (B)
unnamed: D_LF1.2 (A), LF1.2 (B)
unnamed: D_LF2.2 (A), LF2.2 (B)
unnamed: D_LH0.2 (A), L-H0.2 (B)
unnamed: D_LK0.2 (A), L-K0.2 (B)
unnamed: D_LNUM0.2 (A), LNUM0.2 (B)
unnamed: D_LO0.2 (A), L-O0.2 (B)
unnamed: D_LP0.2 (A), L-P0.2 (B)
unnamed: D_LR0.2 (A), L-R0.2 (B)
unnamed: D_LS0.2 (A), L-S0.2 (B)
unnamed: D_LS1.2 (A), LS1.2 (B)
unnamed: D_LS2.2 (A), LS2.2 (B)
unnamed: D_LSTAR0.2 (A), L-STAR0.2 (B)
unnamed: D_LT0.2 (A), L-T0.2 (B)
unnamed: D_LW0.2 (A), L-W0.2 (B)
unnamed: LED1.4 (DOUT), LED2.2 (DIN)
unnamed: LED2.4 (DOUT), LED3.2 (DIN)
unnamed: LED3.4 (DOUT), LED4.2 (DIN)



Board: 2 copper layers, 133.0 x 94.0 mm, 38 parts (16 on the bottom side), 36 nets.

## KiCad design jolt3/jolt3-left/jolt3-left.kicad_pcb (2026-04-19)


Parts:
BT1: Battery; BAT-2xAA-SHELL-CASE-BOX
J29: df40c-2_0-30P-0_4v
J31: RJ45; RJ45_Amphenol_54602-x08_Horizontal
R1, R2: 4.7k; R_0603_1608Metric_Pad0.98x0.95mm_HandSolder

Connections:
+3.3V: J29.21, R1.1, R2.1
/COL-A: J29.13; also elsewhere on the board
/COL-B: J29.15; also elsewhere on the board
/COL-C: J29.17; also elsewhere on the board
/COL-D: J29.19; also elsewhere on the board
/ROW-A: J29.1; also elsewhere on the board
/ROW-B: J29.3; also elsewhere on the board
/ROW-C: J29.5; also elsewhere on the board
/ROW-D: J29.7; also elsewhere on the board
/ROW-E: J29.9; also elsewhere on the board
/ROW-F: J29.11; also elsewhere on the board
/SCL: J29.6, J31.7, R2.2
/SDA: J29.8, J31.8, R1.2
/SER-RX: J29.2, J31.1
/SER-TX: J29.4, J31.3
GND: BT1.2 (-), J29.10, J29.12, J29.14, J29.16, J29.18, J29.20, J29.22, J29.24, J29.26, J29.28, J29.30, J31.2, J31.6
unnamed: BT1.1 (+), J29.27, J29.29
VBUS: J29.23, J29.25, J31.4, J31.5

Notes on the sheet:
Ensure SER-RX and SER-TX are reversed on right-side board.
Remove pullups (or DNP) for right side.


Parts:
J13, J14, J15, J16: Conn_01x02_Pin; PinHeader_1x02_P2.54mm_Vertical

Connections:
/COL-B: J13.1, J13.2; also elsewhere on the board
/ROW-D: J14.1, J14.2; also elsewhere on the board
/ROW-E: J15.1, J15.2; also elsewhere on the board
/ROW-F: J16.1, J16.2; also elsewhere on the board

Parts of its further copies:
J1, J2, J3, J4, J5, J6, J7, J8, J9, J10, J11, J12, J17, J18, J19, J20, J21, J22, J23, J24, J25, J26, J27, J28: Conn_01x02_Pin; PinHeader_1x02_P2.54mm_Vertical

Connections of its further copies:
/COL-A: J1.1, J1.2, J5.1, J5.2; also elsewhere on the board
/COL-B: J9.1, J9.2; also elsewhere on the board
/COL-C: J17.1, J17.2, J21.1, J21.2; also elsewhere on the board
/COL-D: J25.1, J25.2; also elsewhere on the board
/ROW-A: J2.1, J2.2, J10.1, J10.2, J18.1, J18.2, J26.1, J26.2; also elsewhere on the board
/ROW-B: J3.1, J3.2, J11.1, J11.2, J19.1, J19.2, J27.1, J27.2; also elsewhere on the board
/ROW-C: J4.1, J4.2, J12.1, J12.2, J20.1, J20.2, J28.1, J28.2; also elsewhere on the board
/ROW-D: J6.1, J6.2, J22.1, J22.2; also elsewhere on the board
/ROW-E: J7.1, J7.2, J23.1, J23.2; also elsewhere on the board
/ROW-F: J8.1, J8.2, J24.1, J24.2; also elsewhere on the board



Board: 2 copper layers, 151.0 x 98.0 mm, 33 parts (2 on the bottom side), 18 nets.

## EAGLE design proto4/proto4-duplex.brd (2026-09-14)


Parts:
A1: TINY2040
L-A: PG1350-PINKA; PG1350
L-H: PG1350-PINKA; PG1350
L-K: PG1350-PINKA; PG1350
L-O: PG1350-PINKA; PG1350
L-P: PG1350-PINKA; PG1350
L-R: PG1350-PINKA; PG1350
L-S: PG1350-PINKA; PG1350
L-STAR: PG1350-PINKA; PG1350
L-T: PG1350-PINKA; PG1350
L-W: PG1350-PINKA; PG1350
LF1, LF2: PG1350-PINKA; PG1350
LNUM: PG1350-PINKA; PG1350
LS1, LS2: PG1350-PINKA; PG1350
U$1, U$4, U$5, U$6, U$7, U$8, U$9, U$10, U$11, U$12, U$13, U$14, U$15, U$16, U$17: BAV19W; SOD123
U$2: CORTEX-M0; CORTEX-M10
U$3: RJ45-JACK; C-BMJ-0051-RJ45
U$18, U$19, U$20: RGB-LEDLTST-E263CEGBK; DFN180X180X65-2

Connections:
+3.3V: A1.3V3, U$18.1 (VDD), U$19.1 (VDD), U$20.1 (VDD)
GND: A1.GND1, A1.GND2, A1.GND3, U$2.GND, U$2.GND2 (GND), U$2.GNDDETEC (GND), U$18.4 (VSS), U$19.4 (VSS), U$20.4 (VSS)
KEYA: A1.0, LF1.1, LF2.1, U$3.P$1, U$10.C, U$14.C
KEYB: A1.1, L-S.1, L-STAR.1, U$3.P$2, U$11.C, U$16.C
KEYC: A1.2, L-K.1, L-T.1, U$3.P$3, U$12.C, U$17.C
KEYD: A1.3, L-P.1, L-W.1, U$3.P$4, U$13.C
KEYE: A1.4, U$3.P$5
KEYF: A1.5, U$3.P$6
KEYG: A1.6, L-H.1, L-R.1, LS1.1, LS2.1, U$3.P$7, U$4.C, U$6.C, U$8.C, U$15.C
KEYH: A1.7, L-A.1, L-O.1, LNUM.1, U$1.C, U$5.C, U$7.C, U$9.C
unnamed: LF1.2B (2), LF1.2T (2), U$15.A
unnamed: LF2.2B (2), LF2.2T (2), U$1.A
unnamed: L-STAR.2B (2), L-STAR.2T (2), U$4.A
unnamed: L-S.2B (2), L-S.2T (2), U$5.A
unnamed: L-T.2B (2), L-T.2T (2), U$6.A
unnamed: L-K.2B (2), L-K.2T (2), U$7.A
unnamed: L-P.2B (2), L-P.2T (2), U$8.A
unnamed: L-W.2B (2), L-W.2T (2), U$9.A
unnamed: L-H.2B (2), L-H.2T (2), U$10.A
unnamed: L-R.2B (2), L-R.2T (2), U$11.A
unnamed: LS1.2B (2), LS1.2T (2), U$12.A
unnamed: LS2.2B (2), LS2.2T (2), U$13.A
unnamed: LNUM.2B (2), LNUM.2T (2), U$14.A
unnamed: L-A.2B (2), L-A.2T (2), U$16.A
unnamed: L-O.2B (2), L-O.2T (2), U$17.A
unnamed: U$18.3 (DOUT), U$19.2 (DIN)
unnamed: U$19.3 (DOUT), U$20.2 (DIN)
RESET: U$2.NRESET
RGB: A1.A0, U$18.2 (DIN)
SWDCLK: A1.SWCLK, U$2.SWDCLK
SWDIO: A1.SWDIO, U$2.SWDIO


Board: 2 copper layers, 134.0 x 94.0 mm, 36 parts (0 on the bottom side), 30 nets.

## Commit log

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2024-12-16 Clean up most ERC violations
    The remaining are silkscreen overlaps or clipping issues.
    [bletest-2.kicad_pcb]
2024-12-16 Rev A of bletest
    Finish cleanup, and remove last remaining violations.
    There are a handful of silkscreen overlaps with explicit exclusions.
    [bletest-2.kicad_pcb, bletest-2.kicad_sch, bom-reva.xlsx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]
2024-12-16 Cleanup the Cortex-M Debug footprint
    Try to make a silkscreen for it that shows the full connector, with a
    clear pin 1 indicator, that also doesn't overlap any pads.
2024-12-16 jolt2: Add Initial WIP
    The jolt is a "3D" staggered keyboard. There are 3 PCB designs here:
    - jolt2-verts: These are the 1x3 individual key segments. Each holds
    3 keys and is a vertical column.
    - jolt2-left: The base of the left side of the keyboard. This is the
    side intended to be plugged into the host.
    - jolt2-right (not yet made): The right side base.
    [assembled-left.FCStd, base-left.FCStd, flash.kicad_sch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]
2024-12-16 shield-kb1: A keyboard prototype shield for the nRF DK boards
    This initial one has 4 keys, connectors for compatibility with left and
    right, and some LEDs.
    [shield-kb1.dsn, shield-kb1.kicad_pcb, shield-kb1.kicad_sch]
2024-12-16 Commit some missing footprints
    The RP2040 comes from their reference schematic.
    The AP211-SO8 and QBLP600-RGB5 I've drawn from the datasheets.
2024-12-16 shield-kb1: rev-b updates: LEDs
    In addition to actually hooking up the switches, add a PWM RGB LED. It
    is hard to find these that will work with 3.2V, hopefully this one will.
    It is fairly small, and I've come up with some resistors for about 15mA.
    I've also added a jumper to allow the SK6812 to be powered either from
    3.3V or 5V, which should help figring out issues with that.
    [shield-kb1.kicad_pcb, shield-kb1.kicad_sch]
2024-12-16 jolt2: Prepare rev A
    This is Rev A, being sent for production.
    [flash.kicad_sch, jolt2-left.kicad_pcb, mcu.kicad_sch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]
2024-12-16 jolt2: add pim-left board
    Copy the current left board, to jolt2-pim-left, which will be
    re-designed using the PIM722, the Pimoroni 25.4mm x 25.4mm PGA board.
    [flash.kicad_sch, jolt-left.3mf, jolt2-pim-left.kicad_pcb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]
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2024-12-16 jolt2-left: Add inter-board termination
    Add 27 ohm resisters for termination on the inter-board protocol.
    [flash.kicad_sch, jolt2-left.kicad_pcb]
2024-12-16 jolt2-pim-left: Add uart terminating resistors
    Place 27 ohm series resisters on the inter-board uart lines.
    [jolt2-pim-left.kicad_pcb, jolt2-pim-left.kicad_sch]
2024-12-16 Create jolt2-tiny2040-left
    The jump references are messed up, and I'm going to edit the text file
    directly to fix them.
    [flash.kicad_sch, jolt-left.3mf, jolt2-tiny2040-left.kicad_pcb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]
2024-12-16 jolt2-tiny204-left: Cleanup and route
    Fix the designators for all of the pin headers. This was mostly done
    manually, naming them consistently for each component.
    Perform manual routing.
    This should be ready for REV A.
    [jolt2-tiny2040-left.kicad_pcb, jolt2-tiny2040-left.kicad_sch, power.kicad_sch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]
2024-12-16 jolt-tiny2040-right: Create and build rev A
    Create the right side, copying the left, and flipping everything. Route
    the result, ready for Rev A production.
    [flash.kicad_sch, jolt-left.3mf, jolt-tiny2040-right.kicad_pcb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]
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2024-12-16 bletest-2: update xls bom
    This file is not actually useful, as the html bom from the KiCad plugin
    is much more useful.
    [jolt-pcb-layout.xlsx]
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2024-12-16 Rename jolt-tiny2040-right to jolt2-tiny2040-right
    Fix the name to align with the rest of the PCBs.
    [flash.kicad_sch, jolt-left.3mf, jolt2-tiny2040-right.kicad_pcb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]
2024-12-17 Copy jolt2-tiny2040-left to jolt2-pm2350-left
    Start on the 2350 PCB by copying the tiny2040.
    [flash.kicad_sch, jolt2-pm2350-left.kicad_pcb, jolt2-pm2350-left.kicad_sch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]
2024-12-17 jolt2: Update pm2350 left footprint
    Build the footprint, updating it for the left side of the keyboard
    [jolt2-pm2350-left.kicad_pcb, jolt2-pm2350-left.kicad_sch]
2024-12-24 jolt2-tiny2040-right: Update PCB from schematic
    Schematic was missing swapping TX and RX.
    [jolt2-tiny2040-right.kicad_pcb]
2025-01-04 Various PCB updates
    This is before fixing the footprint for the WS2812. Turns out there is a
    ws2812 MINI, and a MINI-HS, and they have very different footprints.
    [PG1350-socket.STEP, board-case-Base-obj.3mf, board-case-Pad (Meshed).3mf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]
2025-01-04 jolt2-left: Fix symbol and footprint for ws2812
    The ws2812 has both a MINI and a MINI-HS footprint, and they have rather
    different footprints. Update the symbol and draw a footprint for the
    proper one we have purchased.
    [jolt2-left.kicad_pcb, power.kicad_sch]
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2025-01-14 jolt2-left: Add some calibration circles
    Add some calibration circles to a user layer that can be included in a
    CAD export and should help determining the position of the keys.
    [jolt2-left.kicad_pcb]
2025-01-22 jolt3: First pass
    This defines a mezzanine board, with connector, and separate left and
    right sides.
    This design doesn't work with the right side, as the connector
    interferes with the RJ-45, so I have to position that differently.
    [flash.kicad_sch, j3-mez-2040.kicad_pcb, j3-mez-2040.kicad_sch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]
2025-01-22 Jolt 3: Rev A for 3 boards
    Send Rev A out for jolt3-left, jolt3-right, and j3-mez-2040.
    [j3-mez-2040.kicad_pcb, jolt3-left.kicad_pcb, jolt3-right.kicad_pcb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]
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2026-04-19 Update for latest KiCad
    This seems to have done a rewrite of uuids within the files.
    [j3-mez-2040.kicad_pcb, jolt3-left.kicad_pcb, jolt3-left.step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]
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2026-08-10 Update the mesa1 for Rev A
    This version rejects compatibility with older designs, in order to make
    routing a lot easier.
    [bom.csv, designators.csv, mesa1-left.kicad_pcb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]
2026-08-15 Add models for keys
    Bring in models for the switches, sockets, and keycaps.
    [Kailh_socket_PG1350.step, MBK_Keycap_1u.step, SW_Kailh_Choc_V1.step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]
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2026-09-05 Commit the mesa2 Rev A design
    Capture mesa2 as it stands: the 20-key unibody board I am typing on, its
    Tiny2040 schematic and routed PCB, the production outputs that were sent
    to fab, and the Python pipeline that derived the key geometry from the
    hand scan. LAYOUT.md, CHOUCHOU.md and SCAN-1.md record where the
    positions came from and what is still open.
    This is a capture point before the Rev B changes start, so the board in
    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
    [bom.csv, designators.csv, mesa2-Edge_Cuts.dxf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]
2026-09-05 Add the plan for Rev B, mesa2x and the Mesa 3
    Write down the path from the mesa2 Rev A board to a split Mesa 3: the
    Rev B layout changes for the Dosh layout, a mesa2x variant to try a
    pairwise matrix, and the Mesa 3 split itself. All four boards go to fab
    in one order, since shipping dominates the cost.
    Records the decisions that were otherwise only in my head: the matrix
    Rev B and the Mesa 3 share, that the firmware must not be able to tell
    those two apart, and that Rev A's mirrored column pairing gets fixed in
    Rev B for legibility rather than function.
    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
2026-09-05 Do the Rev B schematic work for mesa2
    Delete the outer pinky keys and repair the column pairing, the two
    changes that live entirely in the schematic. SW_LR1, SW_RR1 and their
    diodes are gone along with the eight wire stubs that tied those grid
    cells to their row and column buses, leaving 18 keys in the 5x4 grid.
    The columns now pair by finger rather than mirroring the two hands, so
    COL_1 is the pinky on both sides instead of the left pinky and the right
    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
    [mesa2.kicad_sch]
2026-09-05 Update the mesa2 PCB from the Rev B schematic
    Ran Update PCB from Schematic in KiCad: the four outer-pinky footprints
    are gone and every right-hand diode's cathode moved to the column its
    finger uses on the left. The board now agrees with the schematic on 18
    keys and per-finger columns.
    Key placement is untouched -- the pinky rotation and the thumb move are
    a separate step. The right-side column routing is stale by construction
    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
    [mesa2.kicad_pcb]
2026-09-05 Apply the Rev B key placement
    Rotate the surviving pinky keys 90 degrees and pull the SP thumb keys
    1 mm in toward BK, with each diode following its switch. Eight
    footprints move; the other 28 were already correct.
    Konnect's IPC path is the normal route for this, but it segfaults KiCad
    10.0.5 here on writes and on read-only queries alike, so apply-revb.py
    does it through KiCad's own pcbnew module instead -- the board is loaded
    and written by KiCad's serializer, not by touching the file as text. The
    diff stays inside the eight footprints and the board's structure is
    unchanged: 50 footprints, 401 segments, 41 vias, one zone.
    revb.py grows a guard, since it transforms Rev A and is not idempot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
    [mesa2.kicad_pcb]
2026-09-05 Rotate the pinky keys the other way
    Both pinky keys were turned the wrong way: -90 on the left and +90 on
    the right is what the board wants, not the reverse. The keycap lands in
    the same place either way, since the two options are 180 degrees apart
    and the cap is a rectangle, so every clearance number is identical and
    nothing in the geometry could have picked between them. What differs is
    which side the socket body and the diode sit on, which is visible on the
    board and not in the numbers. LAYOUT.md now says so, to stop the
    clearance table arguing for the wrong one later.
    revb.py can recover Rev A from git now that the working board has moved
    past it, so regenerating the placement no longer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
    [mesa2.kicad_pcb]
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2026-09-05 Bring the moved symbols' field text with them
    The column rearrangement left every moved symbol's Reference, Value and
    hidden field text stranded at the old grid cell, so fourteen symbols on
    the right-hand side were labelled from somewhere else on the sheet.
    Konnect's bulk move relocates a symbol but not its fields, while the
    single-symbol move carries both. Bulk-moving each group back by its
    original delta therefore re-aligns the fields against the symbol, and a
    single move then returns the pair together. Every symbol now sits at the
    same field offsets as the ones that never moved.
    Also drop the junction dot the deleted right pinky cell left behind on
    the COL_1 bus, which no longer had thr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
    [mesa2.kicad_sch]
2026-09-05 Record the Rev B design review
    The board passes: DRC has no errors, schematic parity is clean, the
    outline closes through the Tiny2040 cutout, all 36 footprints still sit
    where revb-placement.json puts them, and the silkscreen carries the rev.
    Correct the GPIO map in LAYOUT.md, which still claimed the columns ran
    GP4 up to GP7. They run GP7 down to GP4 now, reassigned after the
    columns paired by finger, and the firmware reads that table.
    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
    [mesa2.kicad_pcb, mesa2.kicad_sch]
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2026-09-06 Finish mesa2 Rev B
    Rev B is complete: 18 keys with the outer pinky gone, the pinky caps
    turned to line up with the other fingers, the thumbs on the same 17 mm
    pitch as the finger rows, and columns paired by finger so one keymap
    serves this board and the Mesa 3 alike.
    Design the SK6812 supply fix in, rather than leaving it as the hand
    rework Rev A needed. D_RE2 drops the LED rail to ~4.3 V so the RP2040's
    3.3 V data clears the 0.7*VDD threshold, JP1 sits open across it as an
    escape hatch for a lot that does not need the drop, and C1-C4 decouple
    each LED. LAYOUT.md records why, since Mesa 3 inherits this circuit and
    the reasoning is not visible in the netlist.
    DRC has no errors and schematic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
    [mesa2.kicad_pcb, mesa2.kicad_sch]
2026-09-06 Tidy the Rev B LED supply and power flags
    Rename the LED series diode to D1, out of the matrix-diode naming it
    first landed in, where it would have sat beside D_RE1 in the BOM and
    read like a key diode. Add PWR_FLAGs to +5V and +4V5, which clears the
    "input power pin not driven" reports that inserting a diode in a rail
    produces. ERC goes from 12 entries to 10; DRC still has no errors and
    parity is clean.
    Record in LAYOUT.md what still reports and why, all of it inherited from
    Rev A: GND has no flag of its own, A1's GND2 sits on no net, and GND1 has
    no copper reaching it. Clearing those three is cosmetic, and worth it
    only so that a real problem cannot hide in the noise later.
    Assisted-by: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
    [mesa2.kicad_pcb, mesa2.kicad_sch, mesa2.step]
2026-09-06 Start the Mesa 3 as two copies of the mesa2
    Copy the finished mesa2 Rev B to mesa3/mesa3-left and mesa3/mesa3-right,
    renamed and with the silkscreen and rev updated. Each half starts as the
    complete 18-key board so the split can be made by deleting what belongs
    to the other side, rather than by building each half up from nothing.
    Nothing else changed: both halves carry the same 55 components, 43 nets,
    55 footprints at identical positions, and the same routing and outline as
    mesa2. The mesa3 directory gets a 3dmodels symlink so the boards' model
    paths resolve as they do under mesa2.
    Also record that the firmware identifies a board from a flashed CBOR
    model blob, which closes the Rev A/Rev B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
    [mesa3-left.kicad_pcb, mesa3-left.kicad_sch, mesa3-right.kicad_pcb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]
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2026-09-06 Split the Mesa 3 into left and right halves
    Each half now carries its own nine keys, its own outline and its own
    routing. The left keeps the Tiny2040, the LEDs, the Tag-Connect and the
    reset pad; the right is switches, diodes and the RJ-45 and nothing else,
    with no power and no ground anywhere on it.
    The two checks that mattered both hold. The RJ-45 pinout is identical at
    both ends, so a straight-through cable is correct -- the pin order runs
    opposite between the halves, which is what a part that cannot be mirrored
    does, and does not matter since the nets match. And all eighteen keys
    keep their exact mesa2 column and row, so one keymap still serves Rev B
    and both halves.
    Record the review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
    [mesa3-left.kicad_pcb, mesa3-left.kicad_sch, mesa3-right.kicad_pcb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]
2026-09-06 Say why the spare RJ-45 conductor stays unused
    The earlier note framed grounding pin 1 as a trade-off that was decided
    against. It is not a trade-off: the right half has no ground net, so the
    conductor would terminate in nothing. Every scan loop already closes
    through two wires of the same cable, the driven row and the column it is
    switched into, so there is no return path missing to supply.
    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
2026-09-07 Finish mesa2x and write down why it does not work
    The pairwise matrix is built and routed: 18 keys on 7 GPIOs, one per pin
    pair, freeing GP5-GP7 and GP29. DRC is clean and parity is clean.
    The ghosting analysis it was built to answer comes out negative, and
    structurally so. Two pressed keys a->c and c->b forge a->b through a
    two-diode sneak path, and 21 two-key chords forge a third real key. The
    forged key is electrically identical to a real one, so no scan order or
    timing resolves it, and no reassignment helps: 18 keys on 7 pins is 18
    edges on 7 vertices, where Mantel's theorem caps a triangle-free graph at
    12. The first pin count that fits 18 keys triangle-free is 9, and the
    graph that do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
    [bom.csv, designators.csv, mesa2x.dsn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]
2026-09-07 Retract the claim that resistors fix the mesa2x matrix
    I said seven series resistors would make the pairwise matrix sound. They
    do not, and a DC solve of the real network with a diode model shows why.
    Driving the non-read pins high does block the ghost, but every other key
    pressed on the same strobe lifts the strobe node by a diode drop, and the
    real press being read rides up with it -- 1.79 V where it needs to be
    under 0.8 V. A false key traded for a missed key. Making the strobe stiff
    instead recovers detection and hands the ghost straight back.
    The reason is structural: the read pin clamps one diode drop above the
    strobe for a real press and two for a ghost, so the separation is always
    o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
2026-09-14 Regenerate the mesa2 fabrication outputs for Rev B
    The board went to Rev B several commits ago but the production directory
    still held the Rev A exports, so the committed BOM and placement files
    described a board that no longer existed. Re-run Fabrication Toolkit and
    add mesa2_B.zip beside the Rev A gerbers.
    The BOM diff is the Rev B change list in miniature: the R column keys and
    their diodes are gone, and the four 100nF decoupling caps and D1 have
    arrived. The 3D export is refreshed from the same board.
    [bom.csv, designators.csv, mesa2.step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]
2026-09-14 Attach 3D models to the mesa1-right key footprints
    The left half already carried STEP models on its switch footprints; the
    right half did not, so the 3D viewer showed bare pads where the keys
    should be. Hang the Kailh socket, Choc V1 switch and 1u MBK keycap
    models off each key footprint, 45 in all, from the shared ../3dmodels
    directory.
    KiCad also dropped the (units ...) blocks it no longer writes while
    saving, which accounts for the rest of the diff.
    [mesa1-right.kicad_pcb]
2026-09-14 Write the jolt3 notes and JLC assembly task list
    CLAUDE.md sketches the three boards in this directory and their debt to
    the jolt2 vertical segments. TASKS.md collects the work j3-mez-2040 still
    needs before JLCPCB will assemble it: the two footprint swaps, the LCSC
    part numbers every symbol has to carry for the BOM to be machine-readable,
    and the per-part mapping table.
    The .gitignore keeps KiCad 10's own .history directories out of the repo;
    it tracks file history itself and we do not need a second copy of it here.
2026-09-14 Move j3-mez-2040 to KiCad 10 and reseat U3 as SOIC-8
    Opening the board in KiCad 10 rewrites it wholesale: the copper and user
    layers are renumbered, vias gain the tenting/covering/plugging/capping
    attributes, the numeric net table is replaced by net names quoted at each
    pad, the duplicated Footprint properties are dropped, and -90 degree
    rotations normalise to 270. None of that is a design change; all 427
    track segments survive untouched.
    Riding along is the first item from TASKS.md: U3, the QSPI flash, swaps
    from WSON-8 to Package_SO:SOIC-8_5.3x5.3mm_P1.27mm so JLC can assemble it,
    which cost one via in the re-route. The two changes cannot be separated
    because the format migration rewrot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
    [j3-mez-2040.kicad_pcb]
2026-09-14 Commit the seven missing davidb-keyboard-foot footprints
    Every one of these is already referenced by a board that is in the repo,
    so a fresh clone could not open jolt2 or jolt3 without unresolved
    footprints. They were created in place and never added.
    The set covers the microcontroller modules the jolt2 variants were built
    around (Tiny2040, Pimoroni PGA2035, SparkFun Pro Micro RP2350), the
    SK6812MINI-HS indicator LED and GCT USB4085 USB-C receptacle that nearly
    every board here uses, and the two halves of the DF40C board-to-board
    connector that joins the jolt3 mezzanine to its main boards.
2026-09-14 Add the jolty-2040 board and two jolt2 exports
    jolty-2040 is the jolt2 left half reworked to carry a bare RP2040 instead
    of a plug-in module: its own QFN-56, W25Q128 flash, crystal and regulator,
    drawn from the RP2040_minimal reference design. It still titles itself
    "Jolt 2 - Left" because it started as a copy of that board. The full
    project comes along — schematic sheets, layout, 3D and interactive BOM
    exports, and the FreeCAD case model that follows the outline.
    Also here: the edge-cuts DXF that jolt2-left hands to the case model, and
    the 4mm spacer body for the vertical segments.
    KiCad backups, fp-info-cache and the FreeCAD .FCBak are left ignored, which
    is why only 1.2M of the dire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
    [flash.kicad_sch, jolt-left.3mf, jolt2-left-Edge_Cuts.dxf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]
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2026-09-14 Write the mesa3w wireless plan
    A BLE, battery-powered spin-off of the mesa3, worked out far enough to
    build from. The scope settled on 2026-09-13 is a rework of the left board
    only: the Tiny2040 comes out, an nRF52840 module, a PMIC and a cell pack go
    in, and the right half and the RJ-45 between them stay exactly as they are.
    That is a reversal of the two-independently-wireless-halves plan the
    earlier analysis assumed, and the note keeps that analysis because it still
    frames the requirements. Wanting the keyboard to run from USB is what
    broke it: USB reaches one half, anything powering the other is a cable, and
    once a cable is granted a passive right half beats a smart one outright.
    It al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
2026-09-14 Record the Rev A order and open the Rev B plan
    The fab batch went out on 2026-09-07, three boards rather than the four
    originally planned, and both mesa3 halves are in transit. The batch
    checklist is closed out against evidence: the three .kicad_dru files are
    byte-identical, all three boards are 1.6mm two-layer, each silkscreen
    names itself and its rev, and the production outputs are committed. Only
    the 3D viewer check is left open, because nothing recorded whether it
    happened. DESIGN.md no longer claims the halves are unfabbed.
    Rev B opens with one change: an extra key per hand immediately inboard of
    the near-row index key, for mode switching rather than chording. Checking
    it against t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
2026-09-14 Settle the mesa3 interconnect on RJ-45
    USB-C is set aside and Rev B keeps the RJ-45. The pin analysis stands
    and is kept, but it turned out not to be the deciding argument: the
    connector question is really a topology question. USB-C only starts to
    make sense once the right half has an MCU of its own, because the link is
    then a two- or three-wire serial one between smart halves, needing far
    fewer conductors and no longer caring about plug orientation. Stretching
    a passive matrix over a USB-C cable is using the connector for something
    it was never shaped for, so the question reopens only if the right half
    stops being passive.
    Also recorded, because it cost time to find out: Keebio publishe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
2026-09-14 Add the FN mode key to mesa3-left and place it
    The Rev B change lands on the left half: SW_LFN1 and D_LFN1, one key
    inboard of the near-row index key, for mode switching. It takes the slot
    the dropped outer pinky left free — SW_LFN1 pad 1 on ROW_A, D_LFN1 pad 1
    on COL_1 — so it costs no GPIO, and since pinky A sits on ROW_B the two
    share COL_1 without colliding.
    Placement comes from fnkey.py rather than the mouse. The key was first
    dropped by hand at (112.700, 84.700), which measured 17.053 mm along
    SW_LE1's local X with 0.435 mm of lateral drift; the computed position is
    (113.272, 85.571) at a clean local (18, 0), a move of 1.042 mm. D_LFN1
    follows at the usual (0, -4.876) offset.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
    [mesa3-left.kicad_pcb, mesa3-left.kicad_sch]
2026-09-14 Make the FN key clearance check layer-aware
    The clearance warning about JP1 was wrong. The switches sit on F.Cu and
    the keycaps stand above that face, so a part on B.Cu is on the far side of
    the board and cannot foul a cap however close it looks in x and y. JP1 is
    back-side, as are D1, C1-C4, J1 and every diode, so none of them bear on
    keycap clearance at all. The nearest part actually sharing the front face
    is LED1 at 15.67 mm, against a 12.03 mm cap half-diagonal.
    fnkey.py now reads each footprint's layer and prints it beside the
    neighbour distances, marking the far-side ones as such. The list still
    includes them, because the far side matters for routing even when it does
    not matter f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
